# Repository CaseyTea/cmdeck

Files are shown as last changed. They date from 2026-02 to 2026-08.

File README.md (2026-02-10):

<p align="center">
    
</p>

Watch the build video ↓

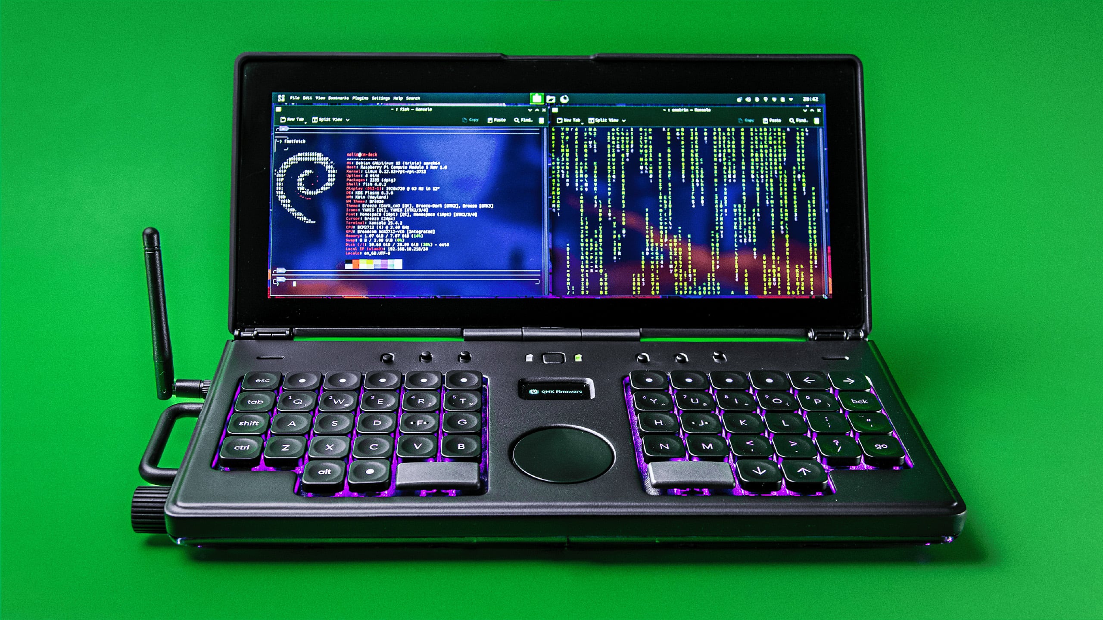
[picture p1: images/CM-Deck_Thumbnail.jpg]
[](https://youtu.be/U5GZeMm5nhI)

CM Deck is a clamshell style cyberdeck built around the Raspberry Pi Compute Module 5. It has a custom carrier board and a low profile mechanical keyboard.

<sub>⚠️ The PCBs will be updated to fix three issues: 1. The flash chip CS pin isn’t connected (see video at [11:09](https://youtu.be/U5GZeMm5nhI?si=vS6aNDHk9gTeop53&t=669)) | 2. Add jumper pads for the power button so I can solder wires and connect it to the power board (see video at [16:32](https://youtu.be/U5GZeMm5nhI?si=_Pz7x-TjfpxkA6fn&t=992)) | 3. Add an open jumper pad on the 3V3 line of the DSI connector on the main board (see video at [15:09](https://youtu.be/U5GZeMm5nhI?si=e3sX7tEprCDsY_S7&t=909))</sub>

[][cc-by-nc-sa]

[][cc-by-nc-sa]

[cc-by-nc-sa]: http://creativecommons.org/licenses/by-nc-sa/4.0/
[cc-by-nc-sa-image]: https://licensebuttons.net/l/by-nc-sa/4.0/88x31.png
[cc-by-nc-sa-shield]: https://img.shields.io/badge/License-CC%20BY--NC--SA%204.0-lightgrey.svg

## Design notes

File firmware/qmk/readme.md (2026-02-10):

⚠️ Copy the `cmdeck` folder to your qmk directory → `qmk_firmware/keyboards/cmdeck`
____

Flashing example for this keyboard:

    qmk flash -kb cmdeck -km default

See the [build environment setup](https://docs.qmk.fm/#/getting_started_build_tools).
Brand new to QMK? Start with our [Complete Newbs Guide](https://docs.qmk.fm/#/newbs).

## Bootloader

Enter the bootloader in 3 ways:

* **Bootmagic reset**: Hold down the key at top right and plug in the keyboard
* **Physical reset button**: Briefly press the button on the the PCB
* **Keycode in layout**: Press the key mapped to `QK_BOOT` if it is available

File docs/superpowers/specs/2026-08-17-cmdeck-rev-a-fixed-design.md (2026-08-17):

# CMDeck Rev A Fixed Design

## Scope

Correct only the three PCB defects documented in the upstream README. Preserve unrelated electrical, mechanical, manufacturing, and firmware behavior.

## Keyboard flash chip select

Rename the anonymous flash-select net `N$12` to `QSPI_SS_N` and connect RP2040 U1 pin `QSPI_SS_N` (physical pad 56) to it. The same net must contain W25Q128JVSIM U3 pin `!CS` (physical pad 1), pull-up R4 pin 1, and BOOT-series resistor R6 pin 2.

Route the new pad-56 connection on the keyboard bottom copper using the existing 0.2032 mm QSPI width. Follow the outside of the existing QSPI bundle with the board's 0.1524 mm clearance instead of crossing another QSPI trace.

No firmware changes are permitted because this is RP2040's dedicated external-flash interface.

## X1203 power-button pads

Add two enlarged plated through-hole wire/test pads to the main board:

- TP15: `PWR_BUTTON`
- TP16: `GND`

Use the existing `testpad:TP` device with its `PAD1-13` device / `P1-13` package: one 1.3208 mm plated hole in a 2.159 mm octagonal pad. Place the pair outside the X1203 module footprint and label the board silkscreen `X1203 BTN`, `PWR`, and `GND`. TP15 replaces an existing same-net 0.35 mm via so the original top-to-bottom connection remains intact without stacking a solder pad over a via.

TP15 is wired in parallel with the existing keyboard power switch and X1203 `PWR_SW` pad. TP16 connects to ground. The external two-pin X1203 power-button connector is wired to these pads without polarity; pressing the keyboard switch produces a momentary short between them.

Both test pads are DNP PCB features, not BOM line items or pick-and-place parts.

## DSI 3V3 isolation jumper

Add main-board JP5 as a dedicated two-terminal, normally-open solder jumper with two 1.2 x 1.5 mm top SMD pads separated by a 0.3 mm copper gap. It has no paste apertures and is not an assembled component.

Insert JP5 in series immediately before DSI connector J1 pin 22:

- JP5 pad 1: `CM5_3.3V`
- JP5 pad 2 and J1 pin 22: `DSI_3V3`

Default state is open. Do not apply solder. Closing JP5 is optional only for a separately verified DSI peripheral that requires host-supplied 3V3 and cannot back-power the carrier.

## Verification and fabrication policy

Use XML/netlist assertions before and after editing. Validate that the Eagle schematic and board agree on every new part, footprint, and target net. Compare BOM, pick-and-place, drill, Gerber, and logical netlist outputs against upstream and explain every change.

Run Autodesk Fusion/EAGLE ERC and DRC and export fresh manufacturing data when the tool is available. If it is unavailable or any CAD/export check remains incomplete, `FABRICATION_READINESS.md` must conclude **DO NOT FABRICATE** and identify the missing verification explicitly.

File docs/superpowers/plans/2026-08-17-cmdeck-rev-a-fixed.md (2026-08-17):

# CMDeck Rev A Fixed Implementation Plan

> **For agentic workers:** REQUIRED SUB-SKILL: Use superpowers:subagent-driven-development (recommended) or superpowers:executing-plans to implement this plan task-by-task. Steps use checkbox (`- [ ]`) syntax for tracking.

**Goal:** Correct the three documented CMDeck PCB defects while preserving unrelated behavior and producing an evidence-based fabrication-readiness decision.

**Architecture:** Make minimal native Eagle XML changes to the paired schematic/board sources. Use structural netlist tests as the regression harness, then use Autodesk Fusion/EAGLE for ERC, DRC, and manufacturing exports if available.

**Tech Stack:** Autodesk Eagle/Fusion XML (`.sch`, `.brd`), Python standard-library XML validation, Gerber X2, Excellon, CSV, pick-and-place text.

**Spec:** `docs/superpowers/specs/2026-08-17-cmdeck-rev-a-fixed-design.md`

## Global Constraints

- Work only on branch `rev-a-fixed`.
- Preserve unrelated electrical, mechanical, and firmware behavior.
- Keep schematic and board files mutually consistent.
- Do not modify firmware unless electrical evidence requires it.
- Do not claim fabrication readiness while ERC, DRC, export, or comparison evidence is missing.

---

### Task 1: Structural regression validator

**Files:**
- Create: `tools/validate_rev_a_fixed.py`

**Interfaces:**
- Consumes: the four Eagle source files.
- Produces: exit-zero structural validation with a human-readable assertion summary.

- [x] Write assertions for the required keyboard CS membership, main-board power pads, DSI series split, footprint defaults, and unchanged firmware tree hash.
- [x] Run the validator against upstream and confirm it fails for the three missing repairs.
- [x] Keep the validator as the repeatable source/netlist regression check.

### Task 2: Keyboard flash CS repair

**Files:**
- Modify: `pcbs/keyboard/src/Keyboard _Schematic.sch`
- Modify: `pcbs/keyboard/src/Keyboard _Board.brd`

**Interfaces:**
- Consumes: existing U1, U3, R4, R6, and QSPI routing.
- Produces: net `QSPI_SS_N` containing U1.56, U3.1, R4.1, and R6.2.

- [x] Add U1 `QSPI_SS_N` to the existing flash-select net in the schematic and rename the net.
- [x] Add U1 pad 56 to the board signal and route it around the outside of the existing bottom-layer QSPI bundle.
- [x] Run XML parsing and the keyboard validator; confirm the CS assertion passes.

### Task 3: Main-board X1203 wire pads

**Files:**
- Modify: `pcbs/main board/src/Main_Board_Schematic.sch`
- Modify: `pcbs/main board/src/Main Board _Board.brd`

**Interfaces:**
- Consumes: `PWR_BUTTON`, `GND`, and existing schematic device `testpad:PAD1-13` / package `P1-13`.
- Produces: plated through-hole TP15 (`PWR_BUTTON`) and TP16 (`GND`) with explicit silkscreen assembly labels.

- [x] Add TP15 and TP16 parts and schematic instances on the UPS/interconnect sheet.
- [x] Add their pin references to `PWR_BUTTON` and `GND`.
- [x] Add the used P1-13 package to the board's embedded testpad library and place both pads outside the X1203 footprint.
- [x] Route TP15 to the existing `PWR_BUTTON` trace and connect TP16 to ground.
- [x] Run XML parsing and the power-pad validator.

### Task 4: Main-board DSI 3V3 isolation

**Files:**
- Modify: `pcbs/main board/src/Main_Board_Schematic.sch`
- Modify: `pcbs/main board/src/Main Board _Board.brd`

**Interfaces:**
- Consumes: `CM5_3.3V` and DSI J1 pin 22.
- Produces: JP5 pad 1 on `CM5_3.3V`, JP5 pad 2 and J1.22 on `DSI_3V3`, default open.

- [x] Add a dedicated two-pad normally-open solder-jumper package, symbol, and device.
- [x] Place JP5 directly in the existing J1.22 trace and split that trace into the two named nets.
- [x] Add the schematic instance and series net split.
- [x] Run XML parsing and the DSI validator.

### Task 5: Manufacturing outputs and comparisons

**Files:**
- Update: `pcbs/keyboard/fab/`
- Update: `pcbs/main board/fab/`
- Create: `verification/upstream-comparison/`

**Interfaces:**
- Consumes: corrected Eagle sources and immutable upstream files from commit `66e5f08`.
- Produces: Gerber, Excellon, BOM, front/back PnP, hashes, and explained comparisons.

- [ ] Run Fusion/EAGLE ERC and DRC with the repository design rules. **Blocked: Fusion/EAGLE is unavailable.**
- [ ] Export fresh Gerber and Excellon files for both boards. **Blocked: Fusion/EAGLE is unavailable.**
- [ ] Export BOM and front/back pick-and-place files for both boards. **Blocked: Fusion/EAGLE is unavailable.**
- [x] Compare source logical nets and source-derived expected aperture/feature, drill, BOM, and placement differences against upstream.
- [x] Do not synthesize or relabel upstream outputs as fresh exports; record the native-CAD deliverables as blocked.

### Task 6: Release documentation and final verification

**Files:**
- Create: `REV_A_FIXED_CHANGELOG.md`
- Create: `FABRICATION_READINESS.md`

**Interfaces:**
- Consumes: all source, validation, ERC/DRC, export, and comparison evidence.
- Produces: exact assembly instructions and an unambiguous fabricate/do-not-fabricate conclusion.

- [x] Document exact nets, pins, footprints, jumper defaults, wiring, and assembly instructions.
- [x] Document every source-derived output difference and every missing native-export verification.
- [x] Run the full structural validator, XML parser, git diff checks, and checked-in fabrication-tree comparison.
- [x] Conclude `DO NOT FABRICATE` because CAD and manufacturing checks remain blocked.

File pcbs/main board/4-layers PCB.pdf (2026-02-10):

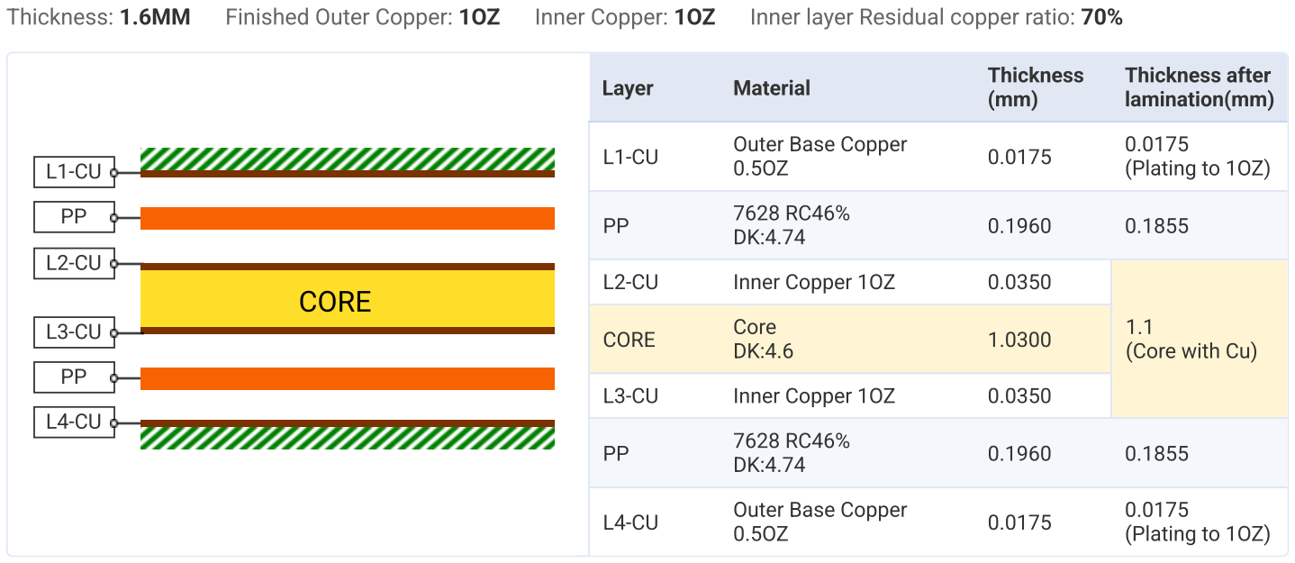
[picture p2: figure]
Layer; Material; Thickness (mm); Thickness after lamination(mm); Outer Base Copper 0.5OZ; 0.0175 (Plating to 1OZ); Inner Copper 1OZ; 1.1 (Core with Cu); CORE; Core DK:4.6

Thickness: 1.6MM | Finished Outer Copper: 1OZ | Inner Copper: 1OZ | Inner layer Residual copper ratio: 70%

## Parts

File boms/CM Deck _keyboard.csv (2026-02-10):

Qty | Value | Parts | Description | Digikey | MPN
64 | 0.1uF | C3, C4, C5, C6, C7, C8, C9, C10, C11, C16, C17, C18, C19, C20, C21, C22, C23, C24, C25, C26, C27, C28, C29, C30, C31, C32, C33, C34, C35, C36, C37, C38, C39, C40, C41, C42, C43, C44, C45, C46, C47, C48, C49, C50, C51, C52, C53, C54, C55, C56, C57, C58, C59, C60, C61, C62, C63, C64, C65, C66, C67, C68, C69, C70 | 0.1 µF ±10% 50V Ceramic Capacitor X7R 0805 (2012 Metric) | 1276-1003-1-ND | CL21B104KBCNNNC
1 | 1-1775333-6CONN16_1-1775333-6_TEC | J3 | 16 Position FPC Connector Contacts, Bottom 0.020" (0.50mm) Surface Mount, Right Angle | A120285CT-ND | 1-1775333-6
7 | 10K | R4, R5, R11, R12, R13, R14, R15 | 10 kOhms ±1% 0.125W, 1/8W Chip Resistor 0805 (2012 Metric) | A129761CT-ND | CRGCQ0805F10K
4 | 10uF | C1, C2, C71, C72 | 10 µF ±10% 25V Ceramic Capacitor X7R 1206 (3216 Metric) | 1276-1804-1-ND | CL31B106KAHNNNE
2 | 15pF | C14, C15 | 15 pF ±5% 50V Ceramic Capacitor C0G, NP0 0805 (2012 Metric) | 732-7847-1-ND | 885012007052
2 | 1K | R1, R6 | 1 kOhms ±5% 0.125W, 1/8W Chip Resistor 0805 (2012 Metric) | A126391CT-ND | CRG0805J1K0
55 | 1N4148W | D1, D2, D3, D4, D5, D6, D7, D8, D9, D10, D11, D12, D13, D14, D15, D16, D17, D18, D19, D20, D21, D22, D23, D24, D25, D26, D27, D28, D29, D30, D31, D32, D33, D34, D35, D36, D37, D38, D39, D40, D41, D42, D43, D44, D45, D46, D47, D48, D49, D50, D51, D52, D53, D54, D55 | Diode 100 V 150mA Surface Mount SOD-123 | 1N4148W-FDICT-ND | 1N4148W-7-F
4 | 1uF | C12, C13, C73, C74 | 1 µF ±10% 50V Ceramic Capacitor X7R 0805 (2012 Metric) | 1276-1029-1-ND | CL21B105KBFNNNE
2 | 2.2K | R9, R10 | 2.2 kOhms ±1% 0.125W, 1/8W Chip Resistor 0805 (2012 Metric) | A106060CT-ND | CRG0805F2K2
2 | 27 | R2, R3 | 27 Ohms ±1% 0.125W, 1/8W Chip Resistor 0805 (2012 Metric) | A129730CT-ND | CRGCQ0805F27R
1 | 5.1K | R8 | 5.1 kOhms ±1% 0.125W, 1/8W Chip Resistor 0805 (2012 Metric) | A126379CT-ND | CRG0805F5K1
54 | 5114 | S1, S2, S3, S4, S5, S6, S7, S8, S9, S10, S11, S12, S13, S14, S15, S16, S17, S18, S19, S20, S21, S22, S23, S24, S25, S26, S27, S28, S29, S30, S31, S32, S33, S34, S35, S36, S37, S38, S39, S40, S41, S42, S43, S44, S45, S46, S47, S48, S49, S50, S51, S52, S53, S54 | Kailh Low Profile Switch Socket | 1528-5118-ND | CPG135001S30
1 | 680K | R7 | 680 kOhms ±1% 0.125W, 1/8W Chip Resistor 0805 (2012 Metric) | A129783CT-ND | CRGCQ0805F680K
1 | ABM8-272-T3 | Y1 | 12 MHz ±30ppm Crystal 10pF 50 Ohms 4-SMD, No Lead | 5254-MP12641CT-ND | MP12641
1 | AP2112K-3.3TRG1SOT_RG1_DIO | U2 | Linear Voltage Regulator IC Positive Fixed 1 Output 600mA SOT-25 | AP2112K-3.3TRG1DICT-ND | AP2112K-3.3TRG1
2 | CHIP-FLAT-G_1206 | D58, D59 | Green 570nm LED Indication - Discrete 2V 1206 (3216 Metric) | 732-4993-1-ND | 150120VS75000
2 | CMS-151135-18S-X8 | LS1, LS2 | 8 Ohms General Purpose Speaker 1 W 760 Hz ~ 20 kHz Top Rectangular | 2223-CMS-151135-18S-X8-ND | CMS-151135-18S-X8
1 | F31L-1A7H1-11012 | J4 | 12 Position FFC, FPC Connector Contacts, Bottom 0.020" (0.50mm) Surface Mount, Right Angle | 609-F31L-1A7H1-11012CT-ND | F31L-1A7H1-11012
2 | M55-6001242R | J1, J2 | 12 Position Receptacle Connector 0.050" (1.27mm) Surface Mount Gold | 952-3835-1-ND | M55-6001242R
1 | PEC09-2120F-S0012 | U$1 | Rotary Encoder Mechanical 12 Quadrature (Incremental) Right Angle | PEC09-2120F-S0012-ND | PEC09-2120F-S0012
1 | SC0914(13) | U1 | RP2040 ARM® Cortex®-M0+ - Microcontroller IC | 2648-SC0914(13)CT-ND | SC0914(13)
54 | SK6812-EJ | LED1, LED2, LED3, LED4, LED5, LED6, LED7, LED8, LED9, LED10, LED11, LED12, LED13, LED14, LED15, LED16, LED17, LED18, LED19, LED20, LED21, LED22, LED23, LED24, LED25, LED26, LED27, LED28, LED29, LED30, LED31, LED32, LED33, LED34, LED35, LED36, LED37, LED38, LED39, LED40, LED41, LED42, LED43, LED44, LED45, LED46, LED47, LED48, LED49, LED50, LED51, LED52, LED53, LED54 | Neopixel Reverse Mount 3.10mm L x 2.70mm W - SK6812-E | 1528-4960-ND | 4960
6 | SLW-1277744-3A-N-D | S55, S56, S57, S58, S59, S60 | Slide Switch SPDT Through Hole | 2223-SLW-1277744-3A-N-D-ND | SLW-1277744-3A-N-D
2 | SN74AHCT1G125DBVR | U4, U5 | Buffer, Non-Inverting 1 Element 1 Bit per Element 3-State Output SOT-23-5 | 296-4708-1-ND | SN74AHCT1G125DBVR
2 | SPST-NO_SWITCH_KMR2 | BOOT, RESET | Tactile Switch SPST-NO Top Actuated Surface Mount | 401-1426-1-ND | Y78B21110FP
1 | SPST-NO_SWITCH_PTS645-SMT-6MM | S61 | Tactile Switch SPST-NO Top Actuated Surface Mount | CKN11907CT-ND | Y97HT23B4EAFP
1 | W25Q128JVSIM_TR | U3 | Check availability | W25Q128JVSIM-ND | W25Q128JVSIM

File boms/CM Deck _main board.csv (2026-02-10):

Qty | Value | Parts | Description | Digikey | MPN
17 | 0.1uF | C1, C2, C3, C4, C5, C6, C7, C8, C11, C21, C27, C28, C30, C32, C34, C45, C51 | 0.1 µF ±10% 50V Ceramic Capacitor X7R 0805 (2012 Metric) | 1276-1003-1-ND | CL21B104KBCNNNC
1 | 1-2199119-5 | J7 | 67 Position Female Connector M.2 (NGFF) Mini Card | A115902CT-ND | 1-2199119-5
6 | 100K | R7, R11, R12, R13, R14, R17 | 100 kOhms ±1% 0.125W, 1/8W Chip Resistor 0805 (2012 Metric) | A129773CT-ND | CRGCQ0805F100K
1 | 100uF | C18 | 100 µF Molded Tantalum Polymer Capacitor 10 V 1411 (3528 Metric) | 478-TCTOBL1A107M8R-ZS1CT-ND | TCTOBL1A107M8R-ZS1
8 | 10K | R1, R6, R16, R19, R28, R31, R32, R33, R34 | 10 kOhms ±1% 0.125W, 1/8W Chip Resistor 0805 (2012 Metric) | A129761CT-ND | CRGCQ0805F10K
17 | 10uF | C9, C10, C14, C15, C16, C17, C19, C20, C22, C23, C24, C25, C29, C31, C33, C35, C52 | 10 µF ±10% 25V Ceramic Capacitor X7R 1206 (3216 Metric) | 1276-1804-1-ND | CL31B106KAHNNNE
1 | 12K | R10 | 12 kOhms ±1% 0.125W, 1/8W Chip Resistor 0805 (2012 Metric) | A129762CT-ND | CRGCQ0805F12K
1 | 15K | R15 | 15 kOhms ±1% 0.125W, 1/8W Chip Resistor 0805 (2012 Metric) | A126341CT-ND | CRG0805F15K
8 | 1uF | C40, C41, C44, C46, C47, C48, C49, C50 | 1 µF ±10% 50V Ceramic Capacitor X7R 0805 (2012 Metric) | 1276-1029-1-ND | CL21B105KBFNNNE
3 | 2.2K | R18, R24, R25 | 2.2 kOhms ±1% 0.125W, 1/8W Chip Resistor 0805 (2012 Metric) | A106060CT-ND | CRG0805F2K2
2 | 2.2nF | C38, C39 | 2200 pF ±5% 50V Ceramic Capacitor C0G, NP0 0805 (2012 Metric) | 1276-2993-1-ND | CL21C222JBFNNNE
4 | 2.2uF | C36, C37, C42, C43 | 2.2 µF ±10% 10V Ceramic Capacitor X7R 0805 (2012 Metric) | 1276-1188-1-ND | CL21B225KPFNNNE
1 | 2.2uH | L1 | 2.2 µH Shielded Molded Inductor 10.3 A 14.52mOhm Max | 732-74439334022CT-ND | 74439334022
1 | 2328702-8 | J14 | 8 Position FPC Connector Contacts, Top and Bottom 0.020" (0.50mm) Surface Mount, Right Angle | A141389CT-ND | 2328702-8
1 | 24 MHz | Y1 | 24 MHz ±20ppm Crystal 18pF 50 Ohms 4-SMD, No Lead | 732-830058124CT-ND | 830058124
2 | 27pF | C12, C13 | 27 pF ±5% 50V Ceramic Capacitor C0G, NP0 0805 (2012 Metric) | 738-CML0805C0G270JT50VCT-ND | CML0805C0G270JT50V
1 | 4.7nF | C26 | 4700 pF ±5% 50V Ceramic Capacitor C0G, NP0 0805 (2012 Metric) | 490-3044-1-ND | GRM2165C1H472JA01D
4 | 470 | R2, R3, R26, R27 | 470 Ohms ±5% 0.125W, 1/8W Chip Resistor 0805 (2012 Metric) | A130132CT-ND | CRGCQ0805J470R
4 | 5.1K | R4, R5, R8, R9 | 5.1 kOhms ±1% 0.125W, 1/8W Chip Resistor 0805 (2012 Metric) | A126379CT-ND | CRG0805F5K1
4 | 56K | R20, R21, R22, R23 | 56 kOhms ±1% 0.125W, 1/8W Chip Resistor 0805 (2012 Metric) | A129770CT-ND | CRGCQ0805F56K
2 | 61201621721 | J18, J19 | Connector Header Through Hole, Right Angle 16 position 0.100" (2.54mm) | 732-2099-ND | 61201621721
1 | 614104190121 | J4 | USB-A (USB TYPE-A) USB 2.0 Receptacle Connector | 732-10011-1-ND | 614104190121
1 | AP22653W6-7 | U3 | Power Switch/Driver 1:1 N-Channel 2.1A SOT-26 (Type A1) | 31-AP22653AW6-7CT-ND | AP22653AW6-7
1 | AP3441SHE-7BIC8_AP3441SHE-7B_DIO-M | U12 | Buck Switching Regulator IC Positive Adjustable 0.6V 1 Output 3A | AP3441SHE-7BDICT-ND | AP3441SHE-7B
1 | ASEK-32.768KHZ-L-R-T | Y2 | 32.768 kHz XO (Standard) CMOS Oscillator 3.3V Enable/Disable 4-SMD, No Lead | 535-ASEK-32.768KHZ-L-R-TCT-ND | ASEK-32.768KHZ-L-R-T
2 | CM5108064B | U1 | 100 Position Connector Receptacle, Center Strip Contacts Surface Mount Gold | H11615CT-ND | DF40C-100DS-0.4V(51)
1 | COIN-CELL-SMT-3P-3002-BR2016 | BT1 | Battery Retainer Coin, 20.0mm 1 Cell SMD (SMT) Tab | 36-3002-ND | 3002
1 | FBCHIP-0805(2012-METRIC) | FB1 | 1 kOhms @ 100 MHz 1 Signal Line Ferrite Bead 0805 (2012 Metric) | 732-6704-1-ND | 782851102
1 | FH12-22S-0.5SH(55)CONN_FH12-22S-0.5SH(55)_HIR | J1 | 22 Position FFC, FPC Connector Contacts, Bottom 0.020" (0.50mm) Surface Mount, Right Angle | HFJ122CT-ND | FH12-22S-0.5SH(55)
1 | FSUSB42MUX | U5 | USB Switch IC 1 Channel 10-MSOP | FSUSB42MUXCT-ND | FSUSB42MUX
2 | HD05-19-TH-TR | J2, J3 | HDMI HDMI 2.0 Receptacle Connector 19 Position Surface Mount, Right Angle; Through Hole | 2223-HD05-19-TH-TRCT-ND | HD05-19-TH-TR
1 | L8BE-1G1T-BFH | J10 | 1 Port RJ45 Board Edge, Cutout; Through Hole 10/100/1000 Base-T, AutoMDIX | 5923-L8BE-1G1T-BFH-ND | L8BE-1G1T-BFH
2 | M55-7011242R | J16, J21 | Connector Header Surface Mount 12 position 0.050" (1.27mm) | 952-3875-1-ND | M55-7011242R
1 | MAX98306ETD+T | U14 | Amplifier IC 2-Channel (Stereo) Class D 14-TDFN (3x3) | MAX98306ETD+TCT-ND | MAX98306ETD+T
1 | PCM5100APWRPW0020A | U13 | DAC, Audio 16 b, 24 b, 32 b 384k PCM 20-TSSOP | 296-36705-1-ND | PCM5100APWR
1 | RT9742SNGVSOT_42SNGV_RIT | U2 | Power Switch/Driver 1:1 N-Channel 500mA SOT-23-3 | 1028-RT9742SNGVCT-ND | RT9742SNGV
2 | S2B-XH-A | J12, J13 | Connector Header Through Hole, Right Angle 2 position 0.098" (2.50mm) | 455-S2B-XH-A-1-ND | S2B-XH-A-1
1 | SJ-3579AN | J17 | 3.50mm (0.141", 1/8", Mini Plug) - Headphone Phone Jack Stereo (3 Conductor, TRS) | 102-5874-ND | SJ-3579AN
1 | SM04B-SRSS-TBCONN_SM04B-SRSS-TB_JST | J8 | Connector Header Surface Mount, Right Angle 4 position 0.039" (1.00mm) | 455-SM04B-SRSS-TBCT-ND | SM04B-SRSS-TB
1 | TPA6132A2 | IC1 | Amplifier IC Headphones, 2-Channel (Stereo) Class AB 16-WQFN (3x3) | 296-27194-1-ND | TPA6132A2RTET
5 | TPD2EUSB30DRTR | D1, D2, D3, D4, D5 | 8V Clamp 5A (8/20µs) Ipp Tvs Diode Surface Mount SOT-3 | 296-25509-1-ND | TPD2EUSB30DRTR
6 | TPD4EUSB30DQAR | U6, U7, U8, U9, U10, U11 | 8V Clamp 1A (8/20µs) Ipp Tvs Diode Surface Mount 10-USON (2.5x1) | 296-28063-1-ND | TPD4EUSB30DQAR
4 | UJ20-C-R-G-TH-2-P14-TR | J5, J6, J9, J11 | USB-C (USB TYPE-C) USB 2.0 Receptacle Connector 24 (14+10 Dummy) | 2223-UJ20-C-R-G-TH-2-P14-TRCT-ND | UJ20-C-R-G-TH-2-P14-TR
1 | USB2514B/M2SQFN36_6X6_MCH | U4 | USB Hub Controller USB Interface 36-SQFN (6x6) | USB2514B/M2-ND | USB2514B/M2

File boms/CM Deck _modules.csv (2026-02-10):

Qty | Part | Link
1 | Raspberry Pi Compute Module 5
1 | NVMe SSD
1 | Aluminum Heatsink for Raspberry Pi CM4
1 | 2.4G/5G WiFi Antenna Compatible w/ Raspberry Pi CM4 & CM5
2 | 3.7V 5000mAh Lithium Ion Polymer Battery
1 | 12.3inch DSI Capacitive Touch Screen
1 | SupTronics X1203 UPS for Raspberry Pi 5
1 | Raspberry Pi 27W USB-C Power Supply
1 | Cirque Capacitance Touch Sensor Modules 40mm Round
54 | Kailh c V1 Low Profile Switches
52 | Choc V1 Low profile Keycaps
2 | (2u) Choc V1 Low profile Keycaps
1 | Monochrome 1.3" 128x64 SH1106G SPI OLED Monochrome Display | 1528-5228-ND
1 | 22 Position FFC, FPC Cable 0.020" (0.50mm) 12.0" (304.8mm) | 0151660248-ND
1 | 8 Position FFC, FPC Cable 0.020" (0.50mm) 12.0" (304.8mm) | 2073-05-08-D-0304-A-4-06-4-G-ND

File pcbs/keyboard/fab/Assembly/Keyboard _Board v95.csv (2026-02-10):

Qty | Value | Device | Package | Parts | Description
64 | 0.1uF | C-US_CHIP-0805(2012-METRIC) | CAPC2012X110 | C3, C4, C5, C6, C7, C8, C9, C10, C11, C16, C17, C18, C19, C20, C21, C22, C23, C24, C25, C26, C27, C28, C29, C30, C31, C32, C33, C34, C35, C36, C37, C38, C39, C40, C41, C42, C43, C44, C45, C46, C47, C48, C49, C50, C51, C52, C53, C54, C55, C56, C57, C58, C59, C60, C61, C62, C63, C64, C65, C66, C67, C68, C69, C70 | Capacitor - ANSI
1 | 1-1775333-6CONN16_1-1775333-6_TEC | 1-1775333-6CONN16_1-1775333-6_TEC | CONN16_1-1775333-6_TEC | J3
7 | 10K | R-US_CHIP-0805(2012-METRIC) | RESC2012X65 | R4, R5, R11, R12, R13, R14, R15 | Resistor Fixed - ANSI
4 | 10uF | C-US_CHIP-1206(3216-METRIC) | CAPC3216X135 | C1, C2, C71, C72 | Capacitor - ANSI
2 | 15pF | C-US_CHIP-0805(2012-METRIC) | CAPC2012X110 | C14, C15 | Capacitor - ANSI
2 | 1K | R-US_CHIP-0805(2012-METRIC) | RESC2012X65 | R1, R6 | Resistor Fixed - ANSI
55 | 1N4148W | 1N4148W | SOD3715X135N | D1, D2, D3, D4, D5, D6, D7, D8, D9, D10, D11, D12, D13, D14, D15, D16, D17, D18, D19, D20, D21, D22, D23, D24, D25, D26, D27, D28, D29, D30, D31, D32, D33, D34, D35, D36, D37, D38, D39, D40, D41, D42, D43, D44, D45, D46, D47, D48, D49, D50, D51, D52, D53, D54, D55 | 1N4148W Series 2 A 100 V 400 mW Surface Mount Fast Switching Diode - SOD-123 Check availability
4 | 1uF | C-US_CHIP-0805(2012-METRIC) | CAPC2012X110 | C12, C13, C73, C74 | Capacitor - ANSI
2 | 2.2K | R-US_CHIP-0805(2012-METRIC) | RESC2012X65 | R9, R10 | Resistor Fixed - ANSI
2 | 27 | R-US_CHIP-0805(2012-METRIC) | RESC2012X65 | R2, R3 | Resistor Fixed - ANSI
1 | 5.1K | R-US_CHIP-0805(2012-METRIC) | RESC2012X65 | R8 | Resistor Fixed - ANSI
54 | 5114 | 5114 | SW_5114 | S1, S2, S3, S4, S5, S6, S7, S8, S9, S10, S11, S12, S13, S14, S15, S16, S17, S18, S19, S20, S21, S22, S23, S24, S25, S26, S27, S28, S29, S30, S31, S32, S33, S34, S35, S36, S37, S38, S39, S40, S41, S42, S43, S44, S45, S46, S47, S48, S49, S50, S51, S52, S53, S54 | Check availability
1 | 680K | R-US_CHIP-0805(2012-METRIC) | RESC2012X65 | R7 | Resistor Fixed - ANSI
1 | ABM8-272-T3 | ABM8-272-T3 | XTAL_ABM8-272-T3 | Y1
1 | AP2112K-3.3TRG1SOT_RG1_DIO | AP2112K-3.3TRG1SOT_RG1_DIO | SOT_RG1_DIO | U2
2 | CHIP-FLAT-G_1206 | CHIP-FLAT-G_1206 | LEDC3216X75N_FLAT-G | D58, D59 | Green LED - Generic
2 | CMS-151135-18S-X8 | CMS-151135-18S-X8 | SPKR_CMS-151135-18S-X8 | LS1, LS2
1 | F31L-1A7H1-11012 | F31L-1A7H1-11012 | AMPHENOL_F31L-1A7H1-11012 | J4
3 | JUMPER-SMT_2_NC_TRACE_NO-SILK | JUMPER-SMT_2_NC_TRACE_NO-SILK | SMT-JUMPER_2_NC_TRACE_NO-SILK | JP1, JP2, JP3 | Normally closed trace jumper
2 | M55-6001242R | M55-6001242R | HARWIN_M55-6001242R | J1, J2
1 | PEC09-2120F-S0012 | PEC09-2120F-S0012 | PEC09-2XXXF-SXXXX | U$1
1 | SC0914(13) | SC0914(13) | QFN40P700X700X90-57N | U1
54 | SK6812-EJ | SK6812-EJ | LED_SK6812-E | LED1, LED2, LED3, LED4, LED5, LED6, LED7, LED8, LED9, LED10, LED11, LED12, LED13, LED14, LED15, LED16, LED17, LED18, LED19, LED20, LED21, LED22, LED23, LED24, LED25, LED26, LED27, LED28, LED29, LED30, LED31, LED32, LED33, LED34, LED35, LED36, LED37, LED38, LED39, LED40, LED41, LED42, LED43, LED44, LED45, LED46, LED47, LED48, LED49, LED50, LED51, LED52, LED53, LED54 | Check availability
6 | SLW-1277744-3A-N-D | SLW-1277744-3A-N-D | SW_SLW-1277744-3A-N-D | S55, S56, S57, S58, S59, S60
2 | SN74AHCT1G125DBVR | SN74AHCT1G125DBVR | SOT95P280X145-5N | U4, U5
2 | SPST-NO_SWITCH_KMR2 | SPST-NO_SWITCH_KMR2 | KMR2 | BOOT, RESET | SPST Switches with NO Configuration
1 | SPST-NO_SWITCH_PTS645-SMT-6MM | SPST-NO_SWITCH_PTS645-SMT-6MM | PTS645-SMT-6MM | S61 | SPST Switches with NO Configuration
8 | TPB1,27 | TPB1,27 | B1,27 | TP4, TP6, TP7, TP8, TP9, TP10, TP11, TP12 | Test pad
5 | TPB2,54 | TPB2,54 | B2,54 | TP1, TP2, TP3, TP5, TP13 | Test pad
1 | W25Q128JVSIM_TR | W25Q128JVSIM_TR | SOIC127P790X216-8N | U3 | Check availability

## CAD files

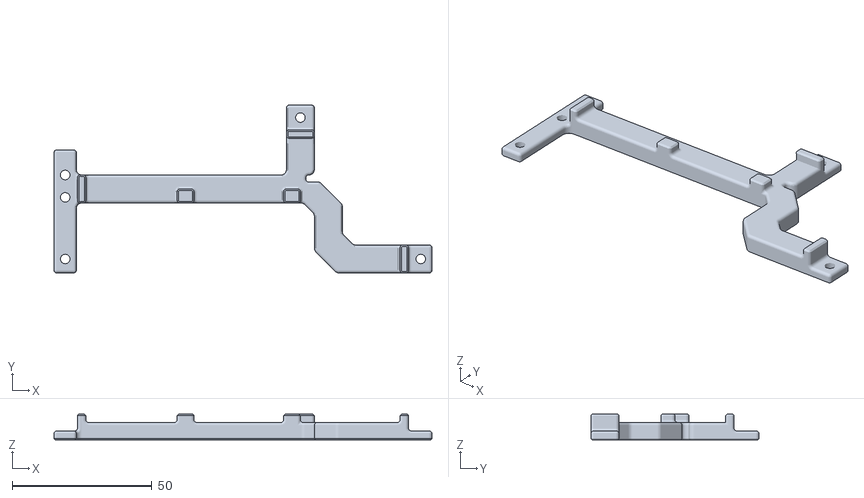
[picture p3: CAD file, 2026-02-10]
enclosure/exports/STL/02_support structure/CDMDECK_KB_INTERNAL_SUP_MAIN_BOARD_RIGHT.stl
135.0 x 60.0 x 9.25

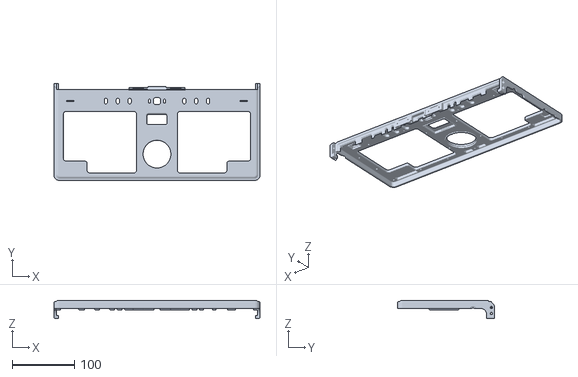
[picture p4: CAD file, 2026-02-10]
enclosure/exports/STL/00_shell/CMDECK_KB_SHELL_TOP.stl
330.0 x 155.0 x 29.1

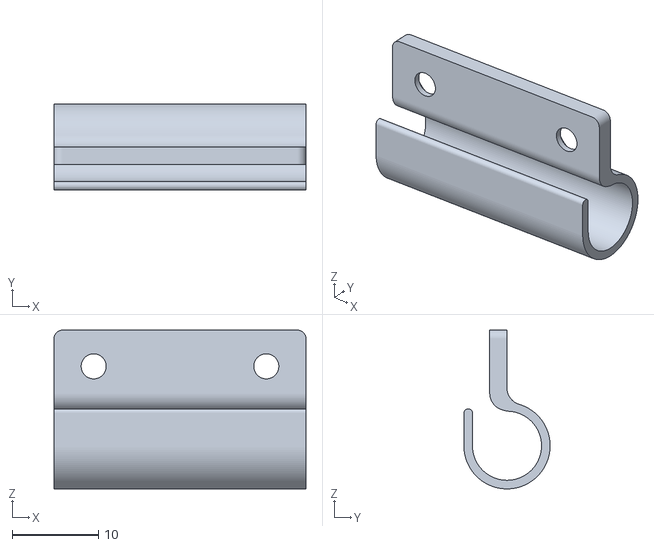
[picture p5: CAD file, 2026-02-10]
enclosure/exports/STL/01_display/CMDECK_DISPLAY_FFC_HINGE_COVER.stl
29.2 x 10.00 x 18.4

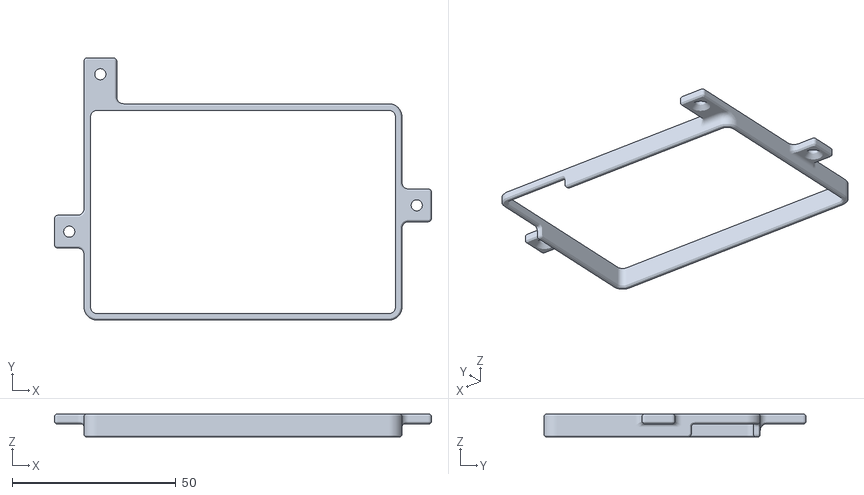
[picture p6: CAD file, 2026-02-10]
enclosure/exports/STL/02_support structure/CDMDECK_KB_INTERNAL_SUP_BAT_PERI_RIGHT.stl
115.0 x 80.0 x 7.00

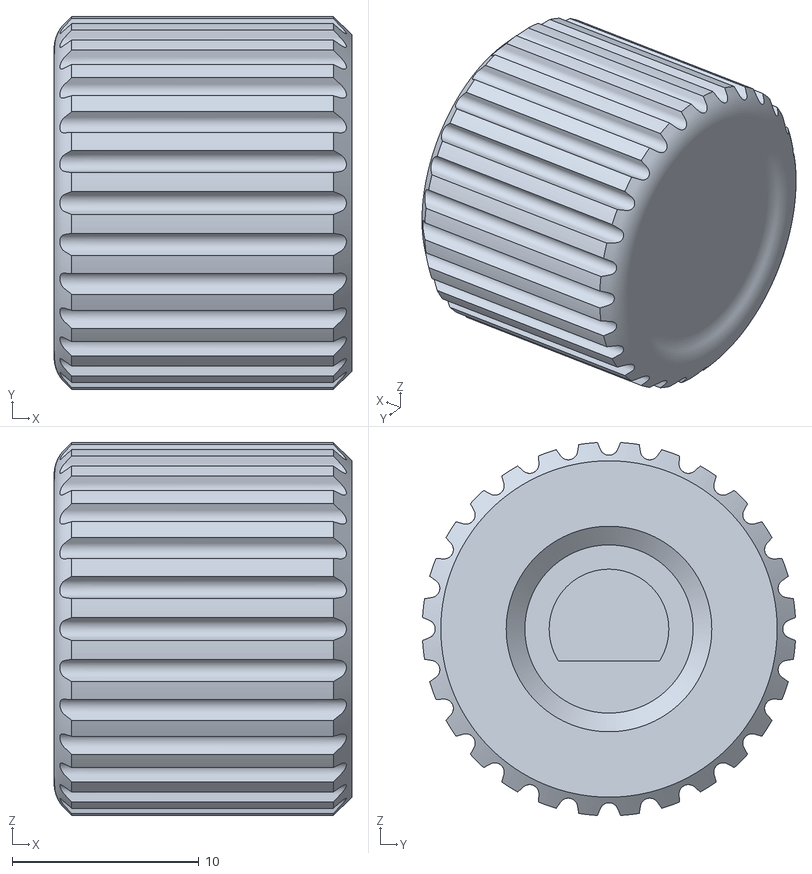
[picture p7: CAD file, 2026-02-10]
enclosure/exports/STL/03_controls/CMDECK_KB_ENCODER_KNOB.stl
15.9 x 20.0 x 20.0

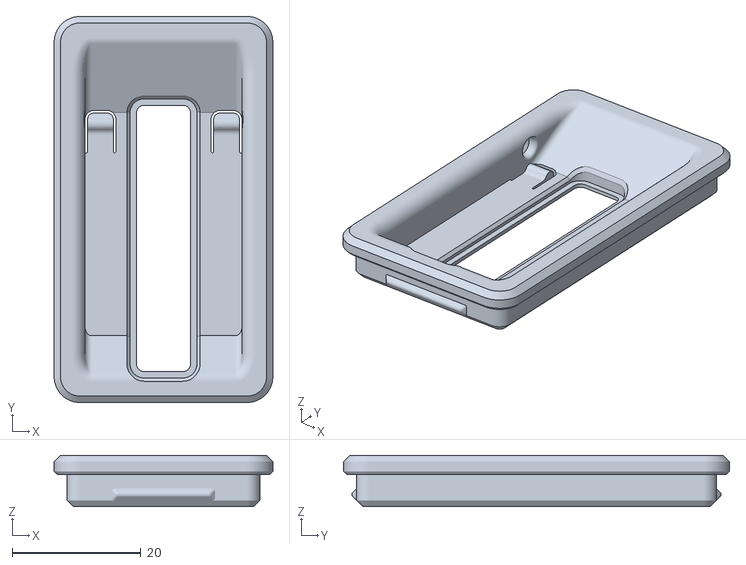
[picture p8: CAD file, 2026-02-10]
enclosure/exports/STL/04_risers/CDMDECK_KB_RISER_FEET_HOLDER.stl
34.0 x 60.0 x 8.00

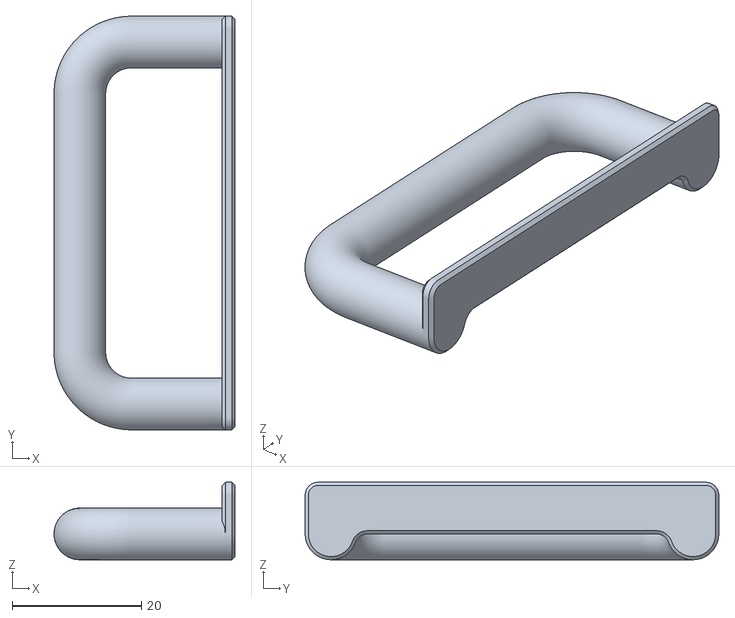
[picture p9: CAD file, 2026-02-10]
enclosure/exports/STL/05_misc/CMDECK_KB_HANDLE.stl
28.0 x 64.0 x 12.0

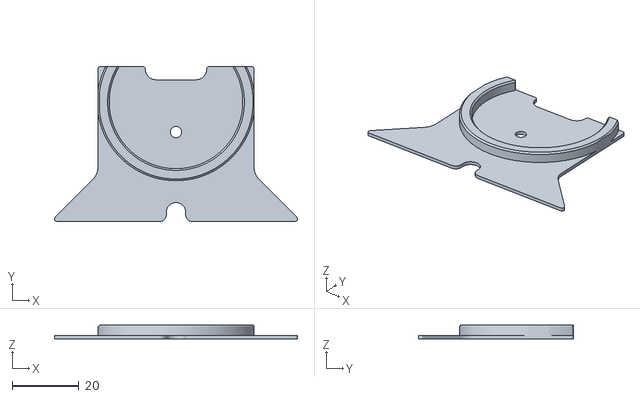
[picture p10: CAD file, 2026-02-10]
enclosure/exports/STL/02_support structure/CDMDECK_KB_INTERNAL_SUP_TRACKPAD_COVER.stl
72.8 x 46.5 x 4.20

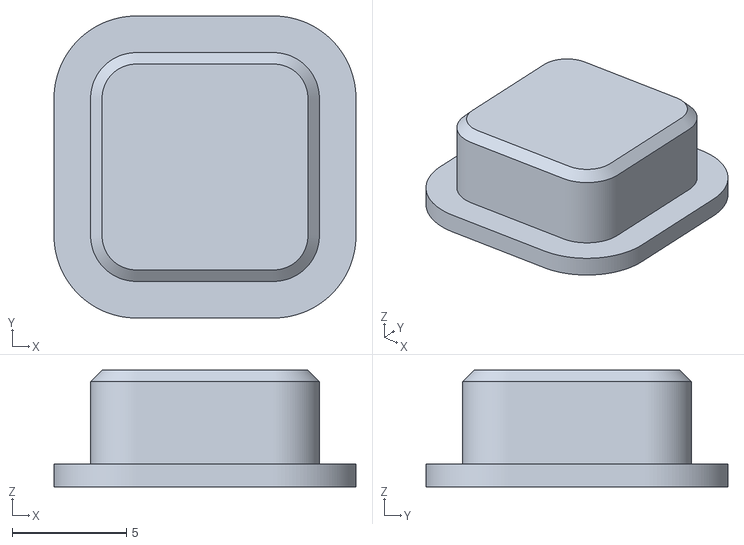
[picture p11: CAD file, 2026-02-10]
enclosure/exports/STL/03_controls/CMDECK_KB_PWR_BUTTON.stl
13.2 x 13.2 x 5.10

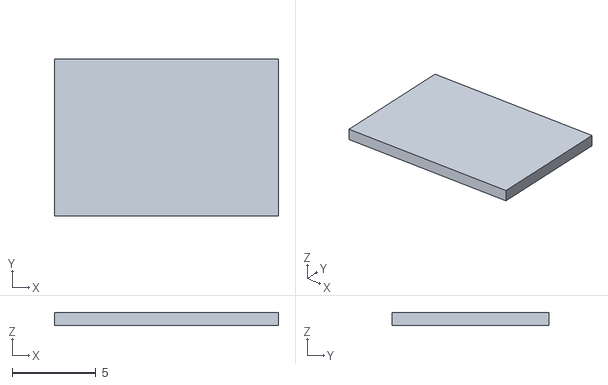
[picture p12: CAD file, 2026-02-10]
enclosure/exports/STL/05_misc/CMDECK_KB_SPEAKER_GRILL_THIN.stl
13.4 x 9.40 x 0.8

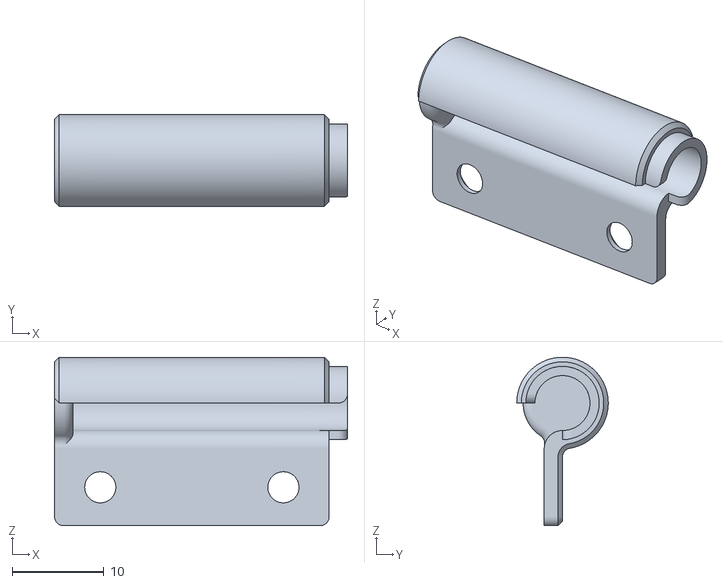
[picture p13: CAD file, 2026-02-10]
enclosure/exports/STL/00_shell/CMDECK_KB_FFC_HINGE_COVER_RIGHT.stl
32.0 x 10.00 x 18.4

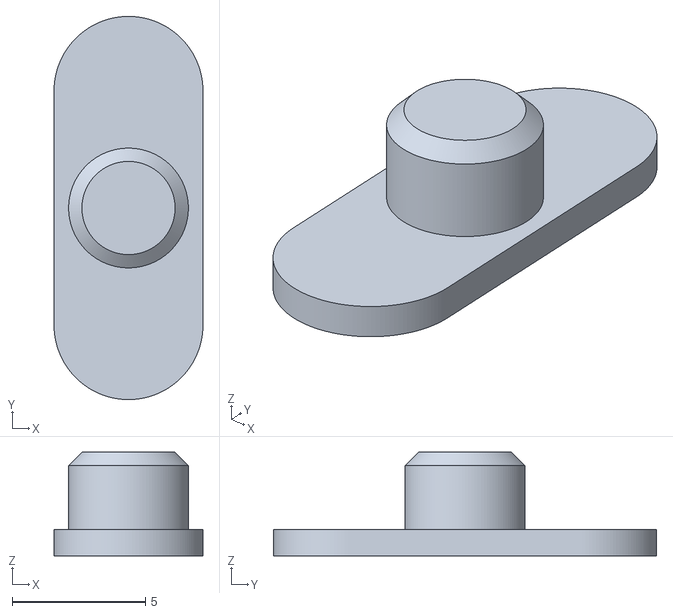
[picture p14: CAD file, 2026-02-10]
enclosure/exports/STL/03_controls/CMDECK_KB_SLIDER_SWITCH.stl
5.60 x 14.4 x 3.90

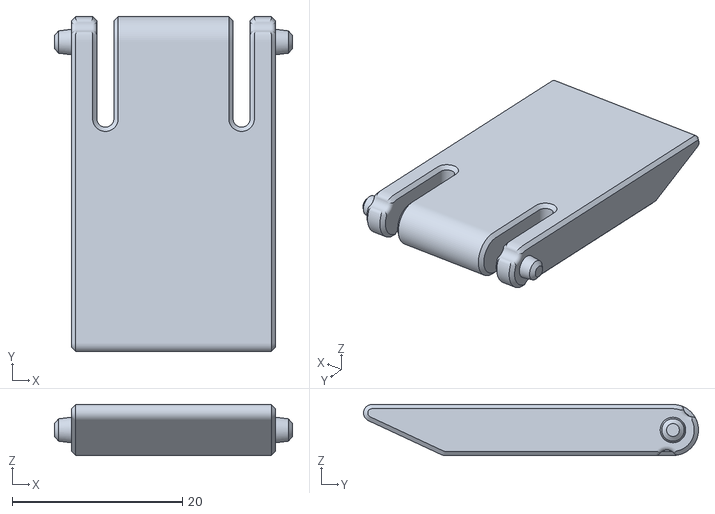
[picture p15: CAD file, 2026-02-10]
enclosure/exports/STL/04_risers/CDMDECK_KB_RISER_FEET.stl
28.0 x 39.4 x 6.00

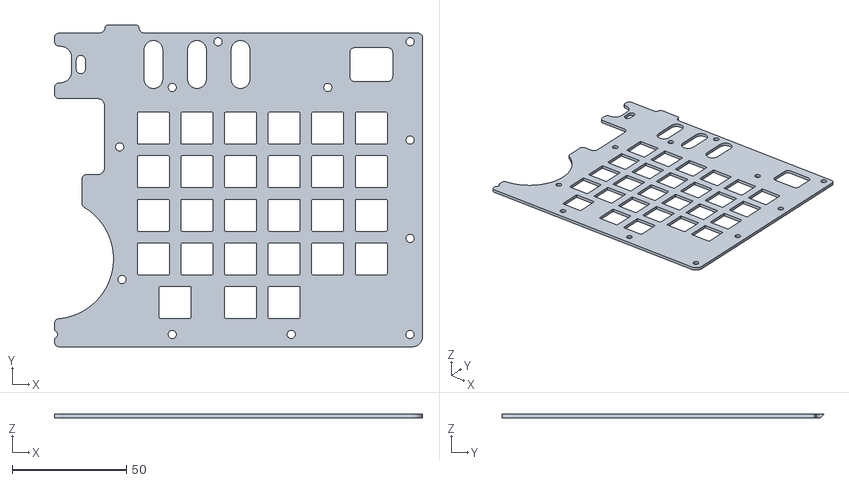
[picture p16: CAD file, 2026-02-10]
enclosure/exports/STL/05_misc/CMDECK_KB_SWITCH_PLATE_RIGHT.stl
160.9 x 140.6 x 1.80

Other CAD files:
enclosure/exports/STL/02_support structure/CDMDECK_KB_INTERNAL_SUP_MAIN_BOARD_LEFT.stl
enclosure/exports/STL/00_shell/CMDECK_KB_SHELL_TOP_ALT.stl
enclosure/exports/STL/00_shell/CMDECK_KB_BACK_IO_PLATE.stl
enclosure/exports/STL/02_support structure/CDMDECK_KB_INTERNAL_SUP_TRACKPAD_SHELL.stl
enclosure/exports/STL/00_shell/CMDECK_KB_FFC_HINGE_COVER_LEFT.stl
enclosure/exports/STL/02_support structure/CDMDECK_KB_INTERNAL_SUP_BAT_LEFT.stl
enclosure/exports/STL/02_support structure/CDMDECK_KB_INTERNAL_SUP_BAT_PERI_LEFT.stl
enclosure/exports/STL/02_support structure/CDMDECK_KB_INTERNAL_SUP_BAT_RIGHT.stl
enclosure/exports/STL/02_support structure/CDMDECK_KB_INTERNAL_SUP_STRUC_LEFT.stl
enclosure/exports/STL/02_support structure/CDMDECK_KB_INTERNAL_SUP_STRUC_RIGHT.stl
enclosure/exports/STL/02_support structure/CMDECK_KB_OLED_SUPPORT.stl
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

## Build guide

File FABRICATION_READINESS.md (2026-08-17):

# CMDeck Rev A Fixed Fabrication Readiness

## Conclusion

**DO NOT FABRICATE.**

The three source-level electrical repairs are implemented and pass structural checks, but the required Autodesk Fusion/EAGLE verification and fresh manufacturing export have not been completed. Existing upstream fabrication outputs remain unsafe.

## Completed evidence

- Both corrected schematic files and both corrected board files parse as well-formed Eagle 9.7 XML.
- Every board element has a corresponding schematic part.
- Every board signal contact reference resolves to a real pad in its embedded footprint.
- Every pre-existing component footprint and placement matches upstream.
- Every unrelated schematic and board endpoint-to-net assignment matches upstream.
- Keyboard `QSPI_SS_N` contains exactly the required functional endpoints, including RP2040 pad 56.
- Main-board TP15 and TP16 exist in both schematic and board on `PWR_BUTTON` and `GND` respectively.
- JP5 is represented consistently in schematic and board as a series split between `CM5_3.3V` and `DSI_3V3`.
- JP5 has no default copper bridge and no paste apertures.
- Local copper inspection found and corrected an initial wire-pad placement conflict; the final plated-hole locations are clear of non-target routed copper in both outer layers by source geometry inspection.
- Firmware is byte-for-byte unchanged from upstream commit `66e5f08`.
- `git diff --check` reports no whitespace errors.

## ERC result

**NOT RUN - BLOCKED.** Autodesk Fusion/EAGLE is not installed or discoverable in `/Applications`, the user Applications directory, `/opt`, `/usr/local`, `/Users/Shared`, or Spotlight metadata on this workstation.

The Python structural validator is not an ERC substitute. It does not evaluate Eagle pin electrical types, supply conflicts, or schematic warnings.

## DRC result

**NOT RUN - BLOCKED.** The Autodesk routing/design-rule engine is unavailable.

Source-level geometry review is not a DRC substitute. It does not prove every copper-to-copper, copper-to-edge, mask-sliver, annular-ring, differential-pair, or plane-clearance rule.

## Fabrication outputs

**NOT GENERATED - BLOCKED.** No fresh Gerber, Excellon, ODB++, BOM, or pick-and-place export has been produced.

The checked-in files under `pcbs/keyboard/fab/` and `pcbs/main board/fab/` remain byte-for-byte upstream artifacts. They do not contain these repairs and must not be sent to a fabricator.

## Remaining required work

1. Open each corrected `.sch`/`.brd` pair together in Autodesk Fusion/EAGLE 9.7-compatible electronics tooling and confirm forward/back annotation consistency.
2. Inspect all newly added library objects and exact board placement visually in the native editor.
3. Re-pour polygons on both boards.
4. Run ERC and resolve or explicitly waive every warning.
5. Run DRC using the original board rules and resolve or explicitly waive every violation.
6. Export fresh Gerber X2 and Excellon data for both boards.
7. Export fresh BOM plus front/back pick-and-place outputs for both boards. Mark TP15, TP16, and JP5 DNP.
8. Compare every new manufacturing file with upstream as outlined in `verification/upstream-comparison/README.md`.
9. Inspect the corrected exports in an independent Gerber viewer, including layer registration, board outline, mask openings, JP5's open gap, TP15/TP16 drills, and the keyboard CS trace.
10. Update this document to `FABRICATE` only after all preceding evidence passes.

## Assembly defaults after verification

- Keyboard: no rework wire; the U1.56-to-U3.1 CS connection is native copper.
- X1203 button: solder two wires to TP15 (`PWR`) and TP16 (`GND`) and connect them to the X1203 external-button input.
- DSI JP5: leave open for the documented externally powered Waveshare display.

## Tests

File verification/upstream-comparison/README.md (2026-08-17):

# Rev A Fixed vs. Upstream Comparison

Baseline: upstream commit `66e5f08` (`origin/main` when the repair branch was created).

## Source netlist differences

### Keyboard

| Item | Upstream | Rev A Fixed | Reason |
|---|---|---|---|
| Flash select net name | `N$12` | `QSPI_SS_N` | Give the repaired dedicated interface an explicit name. |
| Flash select members | U3.1, R4.1, R6.2 | U1.56, U3.1, R4.1, R6.2 | Connect RP2040 `QSPI_SS_N` to W25Q128 `!CS`. |
| Flash select routing | 3 bottom-copper segments | 14 bottom-copper segments | Add one continuous 0.2032 mm trace outside the existing QSPI bundle. |
| Components / footprints | No change | No change | The repair is copper-only. |

No other keyboard signal membership changed.

### Main board

| Item | Upstream | Rev A Fixed | Reason |
|---|---|---|---|
| `PWR_BUTTON` members | U1.92, X1203 `PWR_SW`, J16.B3 | Same plus TP15 | Accessible X1203 button wire pad. |
| `PWR_BUTTON` vias | 5 | 4 | The 0.35 mm via at (66.04, 33.655) is replaced by plated through-hole TP15 at the same coordinate. |
| `GND` members | Existing ground members | Same plus TP16 | Second accessible X1203 button wire pad. |
| DSI J1.22 | Direct member of `CM5_3.3V` | Removed from `CM5_3.3V` | Prevent display back-powering by default. |
| JP5.1 | Absent | `CM5_3.3V` | Host side of series jumper. |
| `DSI_3V3` | Absent | JP5.2 and J1.22 | Isolated connector-side supply net. |
| New board elements | None | TP15, TP16, JP5 | Two wire pads and one normally-open solder jumper. |

No other main-board signal membership changed.

## Footprint differences

- TP15 and TP16 use `testpad:P1-13`: 1.3208 mm plated hole, 2.159 mm octagonal pad.
- JP5 uses `CMDeck-Jumpers:SJ_2_NO`: two 1.2 x 1.5 mm top pads on 1.5 mm centers, producing a 0.3 mm default copper gap. Both pads have paste disabled.
- JP5 contains no copper wire, polygon, or rectangle joining its pads; it is physically normally open.
- Added top silkscreen identifies `X1203 BTN`, `PWR`, and `GND`. JP5 carries its reference designator.

## BOM and pick-and-place comparison

No assembled electrical component was added:

- TP15 and TP16 are plated PCB wire pads.
- JP5 is a bare solder-jumper land pattern.
- All three are DNP and require no purchased part.

Therefore the assembly BOM is intended to remain electrically identical. A Fusion/EAGLE placement export may list TP15, TP16, and JP5 as front-side board elements; those rows must be marked DNP or filtered from the assembler placement list. Exact fresh BOM and front/back placement comparisons are blocked until Fusion/EAGLE export is available.

## Expected fabrication-layer differences

These are source-derived expectations, not substitutes for Gerber comparison:

- Keyboard bottom copper: the new `QSPI_SS_N` route only.
- Main top copper: JP5 pads and separated DSI 3V3 traces.
- Main copper/mask/drill: TP15 and TP16 plated wire pads; TP15 replaces one small via.
- Main top silkscreen: X1203 button labels and JP5 reference.
- Main drill data: remove one 0.35 mm via hit; add two 1.3208 mm plated hits, for a net increase of one drilled hole.
- Main plane clearances/thermals: must be regenerated around both new plated holes by Fusion/EAGLE.

## Existing upstream fabrication files

`git diff 66e5f08 -- pcbs/keyboard/fab pcbs/main\ board/fab boms` is empty. The checked-in Gerbers, drills, BOMs, PnP files, ODB++ data, and zip archives therefore remain the original unsafe upstream outputs. They were deliberately not relabeled or repackaged as corrected exports.

Fresh Gerber, Excellon, BOM, and PnP comparison is **blocked** because Autodesk Fusion/EAGLE 9.7-compatible electronics tooling is not installed on the workstation.

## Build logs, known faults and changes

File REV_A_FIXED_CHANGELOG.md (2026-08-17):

# CMDeck Rev A Fixed Changelog

Baseline: upstream commit `66e5f08`.

## Keyboard PCB

### Flash chip select

- Renamed anonymous net `N$12` to `QSPI_SS_N` in both schematic and board.
- Connected RP2040 U1 logical pin `QSPI_SS_N`, physical pad 56, to the existing flash-select network.
- The completed net contains:
  - U1 pad 56: RP2040 `QSPI_SS_N`
  - U3 pad 1: W25Q128JVSIM `!CS`
  - R4 pad 1: 10 kOhm pull-up branch to 3V3
  - R6 pad 2: BOOT-button series branch
- Added a 0.2032 mm bottom-copper route around the outside of the existing QSPI bundle. Centerline spacing follows the board's existing 0.1524 mm QSPI clearance pattern.
- Firmware is unchanged. RP2040's boot ROM and QSPI/XIP hardware use this dedicated pin; QMK pin configuration is not involved.

## Main PCB

### X1203 external power-button pads

- Added TP15 on `PWR_BUTTON` at board coordinate (66.04 mm, 33.655 mm).
- Added TP16 on `GND` at board coordinate (68.84 mm, 33.655 mm).
- Both use `testpad:P1-13`, with a 1.3208 mm plated hole and a 2.159 mm octagonal pad.
- TP15 replaces the existing same-net 0.35 mm via at its coordinate, preserving the original top-to-bottom electrical transition.
- Added top-silkscreen labels: `X1203 BTN`, `PWR`, and `GND`.

Assembly instructions:

1. Use two insulated wires suitable for the enclosure routing.
2. Connect TP15 (`PWR`) and TP16 (`GND`) to the X1203's two-pin external power-button connector.
3. Polarity is not significant for this dry-contact switch connection.
4. Do not connect these pads to an X1203 battery connector or 5 V output connector.
5. Pressing the CMDeck keyboard power button shorts `PWR_BUTTON` to `GND` momentarily, in parallel with the X1203 external-button input.

### DSI 3V3 isolation

- Added JP5 using `CMDeck-Jumpers:SJ_2_NO` at board coordinate (181.94 mm, 46.4796 mm).
- JP5 pad 1 is on `CM5_3.3V`.
- JP5 pad 2 and DSI connector J1 pin 22 are on new net `DSI_3V3`.
- Footprint: two 1.2 x 1.5 mm top pads, 1.5 mm center-to-center, 0.3 mm copper gap, no paste apertures.
- Default assembly state: **OPEN / DO NOT BRIDGE**.
- The documented Waveshare display is powered separately from 5 V and was observed by the creator to back-feed approximately 3 V through DSI when J1.22 was connected. Leave JP5 open for this assembly.
- Bridge JP5 only for a separately verified DSI peripheral that needs host-supplied 3V3 and cannot back-power the carrier.

## Unchanged behavior

- No firmware files changed.
- No existing component placement, board outline, mounting geometry, stackup, connector assignment, or unrelated net membership changed.
- The documented 1.6 mm, four-layer, 1 oz outer/inner stackup file is unchanged.
- Existing upstream fabrication data is unchanged and remains unsafe.

## Validation artifacts

- `tools/validate_rev_a_fixed.py` checks schematic/board part consistency, embedded footprint pads, exact repaired net membership, all unrelated endpoint-to-net assignments, pre-existing component placements, jumper default geometry, and unchanged firmware.
- `verification/upstream-comparison/README.md` explains every source-level difference and the blocked manufacturing comparisons.

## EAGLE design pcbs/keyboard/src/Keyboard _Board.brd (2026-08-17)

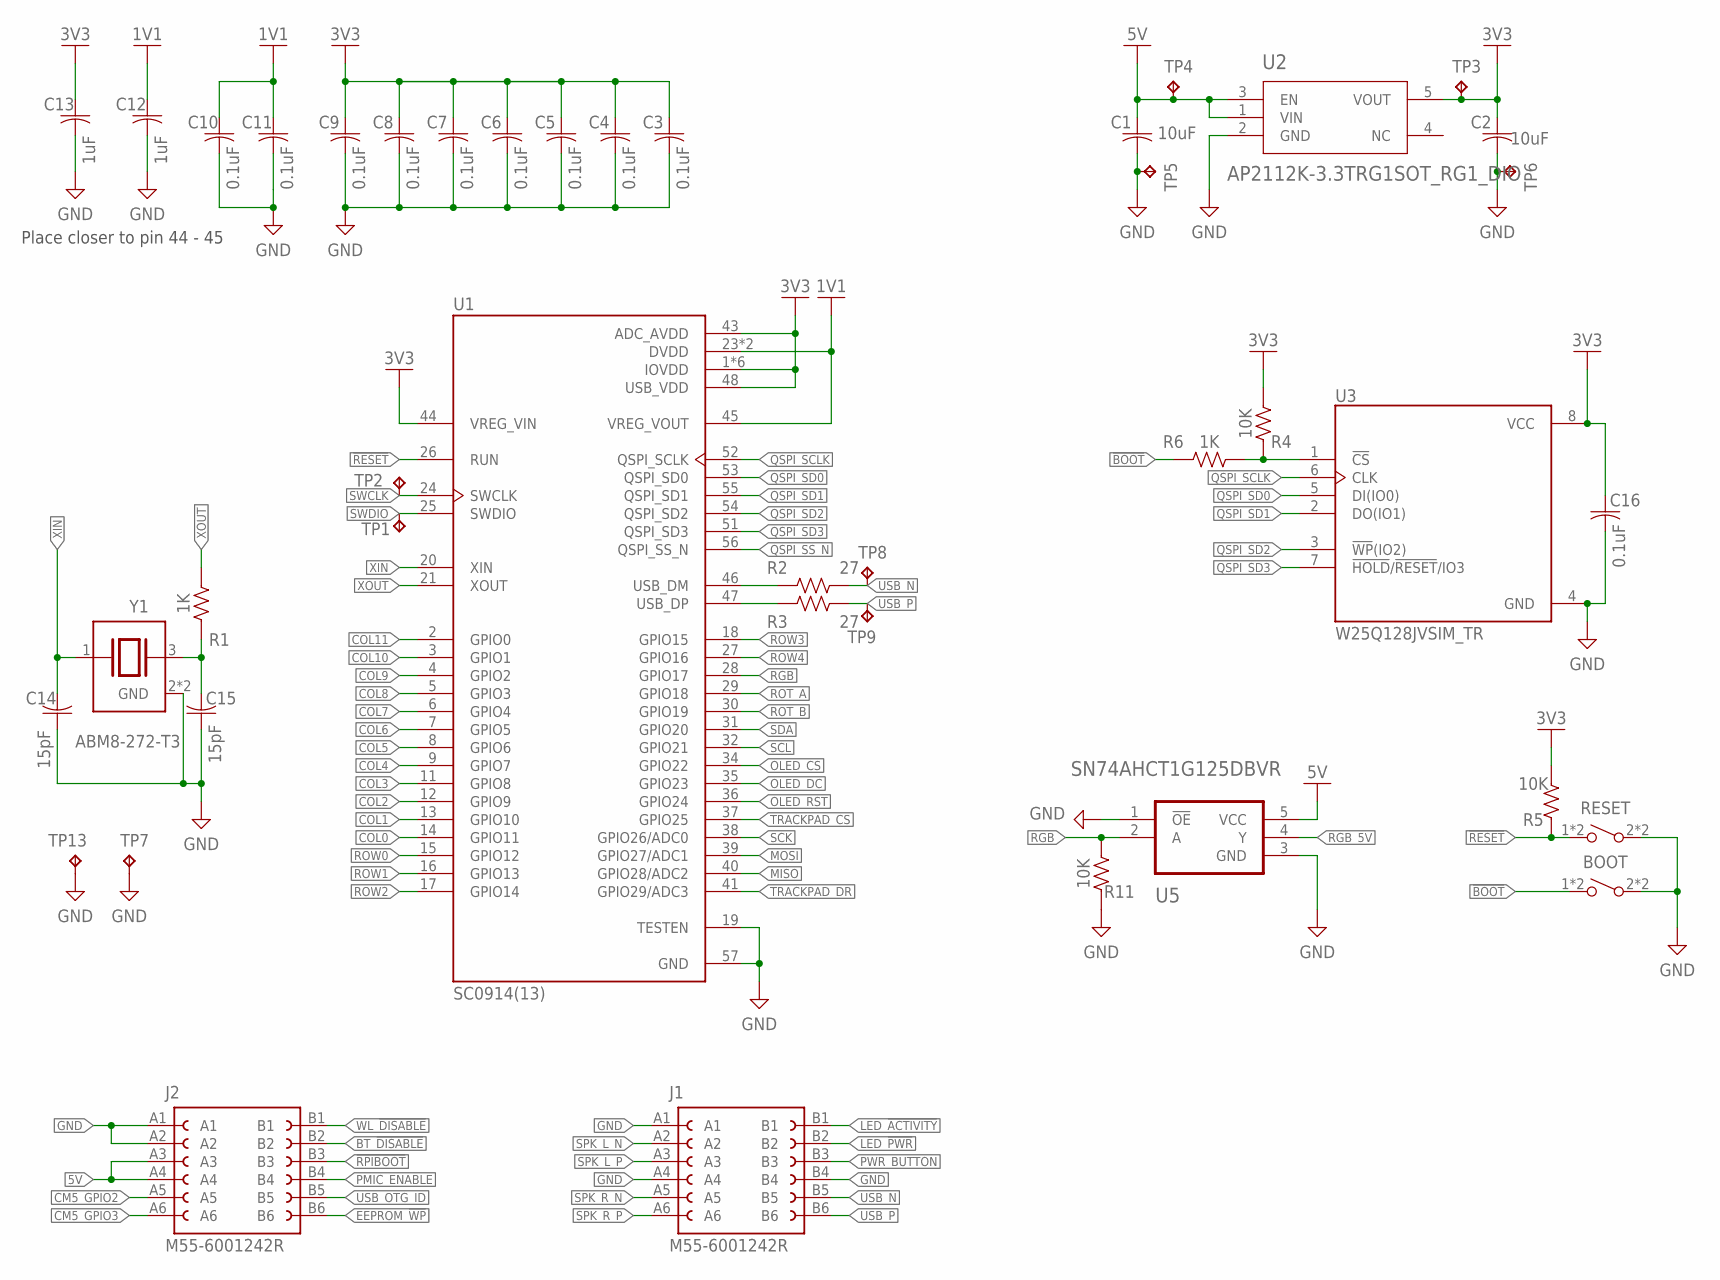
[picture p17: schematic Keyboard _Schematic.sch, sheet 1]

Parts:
BOOT: SPST-NO_SWITCH_KMR2; KMR2
C1, C2: 10uF; CAPC3216X135
C3, C4, C5, C6, C7, C8, C9, C10, C11, C16: 0.1uF; CAPC2012X110
C12, C13: 1uF; CAPC2012X110
C14, C15: 15pF; CAPC2012X110
J1, J2: M55-6001242R; HARWIN_M55-6001242R
R1, R6: 1K; RESC2012X65
R2, R3: 27; RESC2012X65
R4, R5, R11: 10K; RESC2012X65
RESET: SPST-NO_SWITCH_KMR2; KMR2
TP1, TP2, TP3, TP5, TP13: TPB2,54; B2,54
TP4, TP6, TP7, TP8, TP9: TPB1,27; B1,27
U1: SC0914(13); QFN40P700X700X90-57N
U2: AP2112K-3.3TRG1SOT_RG1_DIO; SOT_RG1_DIO
U3: W25Q128JVSIM_TR; SOIC127P790X216-8N
U5: SN74AHCT1G125DBVR; SOT95P280X145-5N
Y1: ABM8-272-T3; XTAL_ABM8-272-T3

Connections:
1V1: C10.1, C11.1, C12.1, U1.23 (DVDD), U1.45 (VREG_VOUT), U1.50 (DVDD)
3V3: C2.1, C3.1, C4.1, C5.1, C6.1, C7.1, C8.1, C9.1, C13.1, C16.1, R4.2, R5.2, TP3.TP, U1.1 (IOVDD), U1.10 (IOVDD), U1.22 (IOVDD), U1.33 (IOVDD), U1.42 (IOVDD), U1.43 (ADC_AVDD), U1.44 (VREG_VIN), U1.48 (USB_VDD), U1.49 (IOVDD), U2.5 (VOUT), U3.8 (VCC); also elsewhere on the board
5V: C1.1, J2.A3, J2.A4, TP4.TP, U2.1 (VIN), U2.3 (EN), U5.5 (VCC); also elsewhere on the board
!BOOT: BOOT.1, BOOT.4 (1), R6.1
!RESET: R5.1, RESET.1, RESET.4 (1), U1.26 (RUN)
!RPIBOOT: J2.B3; also elsewhere on the board
BT_!DISABLE: J2.B2; also elsewhere on the board
CM5_GPIO2: J2.A5; also elsewhere on the board
CM5_GPIO3: J2.A6; also elsewhere on the board
COL0: U1.14 (GPIO11); also elsewhere on the board
COL1: U1.13 (GPIO10); also elsewhere on the board
COL2: U1.12 (GPIO9); also elsewhere on the board
COL3: U1.11 (GPIO8); also elsewhere on the board
COL4: U1.9 (GPIO7); also elsewhere on the board
COL5: U1.8 (GPIO6); also elsewhere on the board
COL6: U1.7 (GPIO5); also elsewhere on the board
COL7: U1.6 (GPIO4); also elsewhere on the board
COL8: U1.5 (GPIO3); also elsewhere on the board
COL9: U1.4 (GPIO2); also elsewhere on the board
COL10: U1.3 (GPIO1); also elsewhere on the board
COL11: U1.2 (GPIO0); also elsewhere on the board
EEPROM_!WP: J2.B6; also elsewhere on the board
GND: BOOT.2, BOOT.3 (2), C1.2, C2.2, C3.2, C4.2, C5.2, C6.2, C7.2, C8.2, C9.2, C10.2, C11.2, C12.2, C13.2, C14.1, C15.1, C16.2, J1.A1, J1.A4, J1.B4, J2.A1, J2.A2, R11.1, RESET.2, RESET.3 (2), TP5.TP, TP6.TP, TP7.TP, TP13.TP, U1.19 (TESTEN), U1.57 (GND), U2.2 (GND), U3.4 (GND), U5.1 (!OE), U5.3 (GND), Y1.2 (GND), Y1.4 (GND); also elsewhere on the board
LED_!ACTIVITY: J1.B1; also elsewhere on the board
LED_!PWR: J1.B2; also elsewhere on the board
MISO: U1.40 (GPIO28/ADC2); also elsewhere on the board
MOSI: U1.39 (GPIO27/ADC1); also elsewhere on the board
unnamed: C15.2, R1.1, Y1.3
OLED_CS: U1.34 (GPIO22); also elsewhere on the board
OLED_DC: U1.35 (GPIO23); also elsewhere on the board
OLED_RST: U1.36 (GPIO24); also elsewhere on the board
PMIC_ENABLE: J2.B4; also elsewhere on the board
PWR_BUTTON: J1.B3; also elsewhere on the board
QSPI_SCLK: U1.52 (QSPI_SCLK), U3.6 (CLK)
QSPI_SD0: U1.53 (QSPI_SD0), U3.5 (DI(IO0))
QSPI_SD1: U1.55 (QSPI_SD1), U3.2 (DO(IO1))
QSPI_SD2: U1.54 (QSPI_SD2), U3.3 (!WP!(IO2))
QSPI_SD3: U1.51 (QSPI_SD3), U3.7 (!HOLD!/!RESET!/IO3)
QSPI_SS_N: R4.1, R6.2, U1.56 (QSPI_SS_N), U3.1 (!CS)
RGB: R11.2, U1.28 (GPIO17), U5.2 (A)
RGB_5V: U5.4 (Y); also elsewhere on the board
ROT_A: U1.29 (GPIO18); also elsewhere on the board
ROT_B: U1.30 (GPIO19); also elsewhere on the board
ROW0: U1.15 (GPIO12); also elsewhere on the board
ROW1: U1.16 (GPIO13); also elsewhere on the board
ROW2: U1.17 (GPIO14); also elsewhere on the board
ROW3: U1.18 (GPIO15); also elsewhere on the board
ROW4: U1.27 (GPIO16); also elsewhere on the board
SCK: U1.38 (GPIO26/ADC0); also elsewhere on the board
SCL: U1.32 (GPIO21); also elsewhere on the board
SDA: U1.31 (GPIO20); also elsewhere on the board
SPK_L_N: J1.A2; also elsewhere on the board
SPK_L_P: J1.A3; also elsewhere on the board
SPK_R_N: J1.A5; also elsewhere on the board
SPK_R_P: J1.A6; also elsewhere on the board
SWCLK: TP2.TP, U1.24 (SWCLK)
SWDIO: TP1.TP, U1.25 (SWDIO)
TRACKPAD_CS: U1.37 (GPIO25); also elsewhere on the board
TRACKPAD_DR: U1.41 (GPIO29/ADC3); also elsewhere on the board
USB_D_N: R2.1, U1.46 (USB_DM)
USB_D_P: R3.2, U1.47 (USB_DP)
USB_N: J1.B5, R2.2, TP8.TP
USB_OTG_ID: J2.B5; also elsewhere on the board
USB_P: J1.B6, R3.1, TP9.TP
WL_!DISABLE: J2.B1; also elsewhere on the board
XIN: C14.2, U1.20 (XIN), Y1.1
XOUT: R1.2, U1.21 (XOUT)

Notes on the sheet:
Place closer to pin 44 - 45

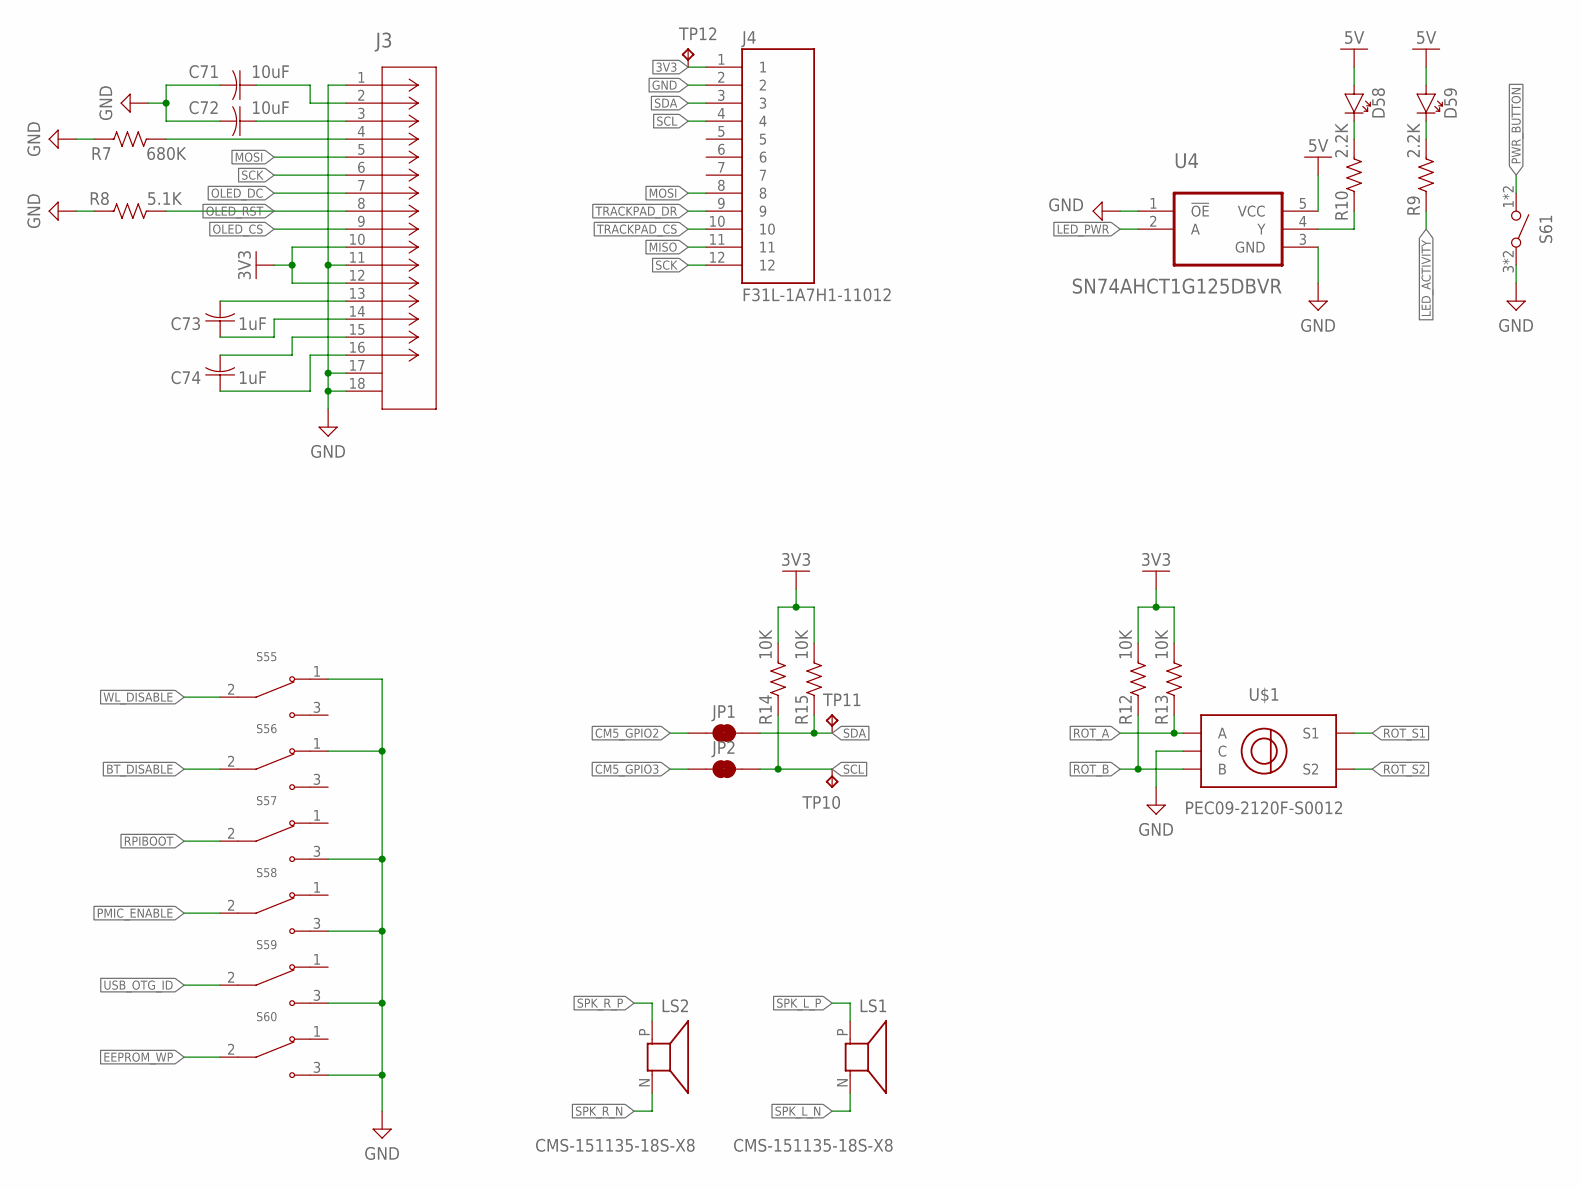
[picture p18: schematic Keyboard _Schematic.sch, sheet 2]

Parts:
C71, C72: 10uF; CAPC3216X135
C73, C74: 1uF; CAPC2012X110
D58, D59: CHIP-FLAT-G_1206; LEDC3216X75N_FLAT-G
J3: 1-1775333-6CONN16_1-1775333-6_TEC; CONN16_1-1775333-6_TEC
J4: F31L-1A7H1-11012; AMPHENOL_F31L-1A7H1-11012
JP1, JP2: JUMPER-SMT_2_NC_TRACE_NO-SILK; SMT-JUMPER_2_NC_TRACE_NO-SILK
LS1, LS2: CMS-151135-18S-X8; SPKR_CMS-151135-18S-X8
R7: 680K; RESC2012X65
R8: 5.1K; RESC2012X65
R9, R10: 2.2K; RESC2012X65
R12, R13, R14, R15: 10K; RESC2012X65
S55, S56, S57, S58, S59, S60: SLW-1277744-3A-N-D; SW_SLW-1277744-3A-N-D
S61: SPST-NO_SWITCH_PTS645-SMT-6MM; PTS645-SMT-6MM
TP10, TP11, TP12: TPB1,27; B1,27
U4: SN74AHCT1G125DBVR; SOT95P280X145-5N
U$1: PEC09-2120F-S0012; PEC09-2XXXF-SXXXX

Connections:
3V3: J3.10, J3.12, J4.1, R12.2, R13.2, R14.2, R15.2, TP12.TP; also elsewhere on the board
5V: D58.A, D59.A, U4.5 (VCC); also elsewhere on the board
!RPIBOOT: S57.2; also elsewhere on the board
BT_!DISABLE: S56.2; also elsewhere on the board
CM5_GPIO2: JP1.1; also elsewhere on the board
CM5_GPIO3: JP2.1; also elsewhere on the board
EEPROM_!WP: S60.2; also elsewhere on the board
GND: C71.2, C72.2, J3.1, J3.11, J3.17, J3.18, J4.2, R7.1, R8.1, S55.1, S56.1, S57.3, S58.3, S59.3, S60.3, S61.3 (2), S61.4 (2), U4.1 (!OE), U4.3 (GND), U$1.P$2 (C); also elsewhere on the board
LED_!ACTIVITY: R9.1; also elsewhere on the board
LED_!PWR: U4.2 (A); also elsewhere on the board
MISO: J4.11; also elsewhere on the board
MOSI: J3.5, J4.8; also elsewhere on the board
unnamed: D59.C, R9.2
unnamed: C71.1, J3.2
unnamed: C72.1, J3.3
unnamed: J3.4, R7.2
unnamed: C73.2, J3.13
unnamed: C73.1, J3.14
unnamed: C74.2, J3.15
unnamed: C74.1, J3.16
unnamed: D58.C, R10.2
unnamed: R10.1, U4.4 (Y)
OLED_CS: J3.9; also elsewhere on the board
OLED_DC: J3.7; also elsewhere on the board
OLED_RST: J3.8, R8.2; also elsewhere on the board
PMIC_ENABLE: S58.2; also elsewhere on the board
PWR_BUTTON: S61.1, S61.2 (1); also elsewhere on the board
ROT_A: R13.1, U$1.P$3 (A); also elsewhere on the board
ROT_B: R12.1, U$1.P$1 (B); also elsewhere on the board
ROT_S1: U$1.P$4 (S1); also elsewhere on the board
ROT_S2: U$1.P$5 (S2); also elsewhere on the board
SCK: J3.6, J4.12; also elsewhere on the board
SCL: J4.4, JP2.2, R14.1, TP10.TP; also elsewhere on the board
SDA: J4.3, JP1.2, R15.1, TP11.TP; also elsewhere on the board
SPK_L_N: LS1.N; also elsewhere on the board
SPK_L_P: LS1.P; also elsewhere on the board
SPK_R_N: LS2.N; also elsewhere on the board
SPK_R_P: LS2.P; also elsewhere on the board
TRACKPAD_CS: J4.10; also elsewhere on the board
TRACKPAD_DR: J4.9; also elsewhere on the board
USB_OTG_ID: S59.2; also elsewhere on the board
WL_!DISABLE: S55.2; also elsewhere on the board

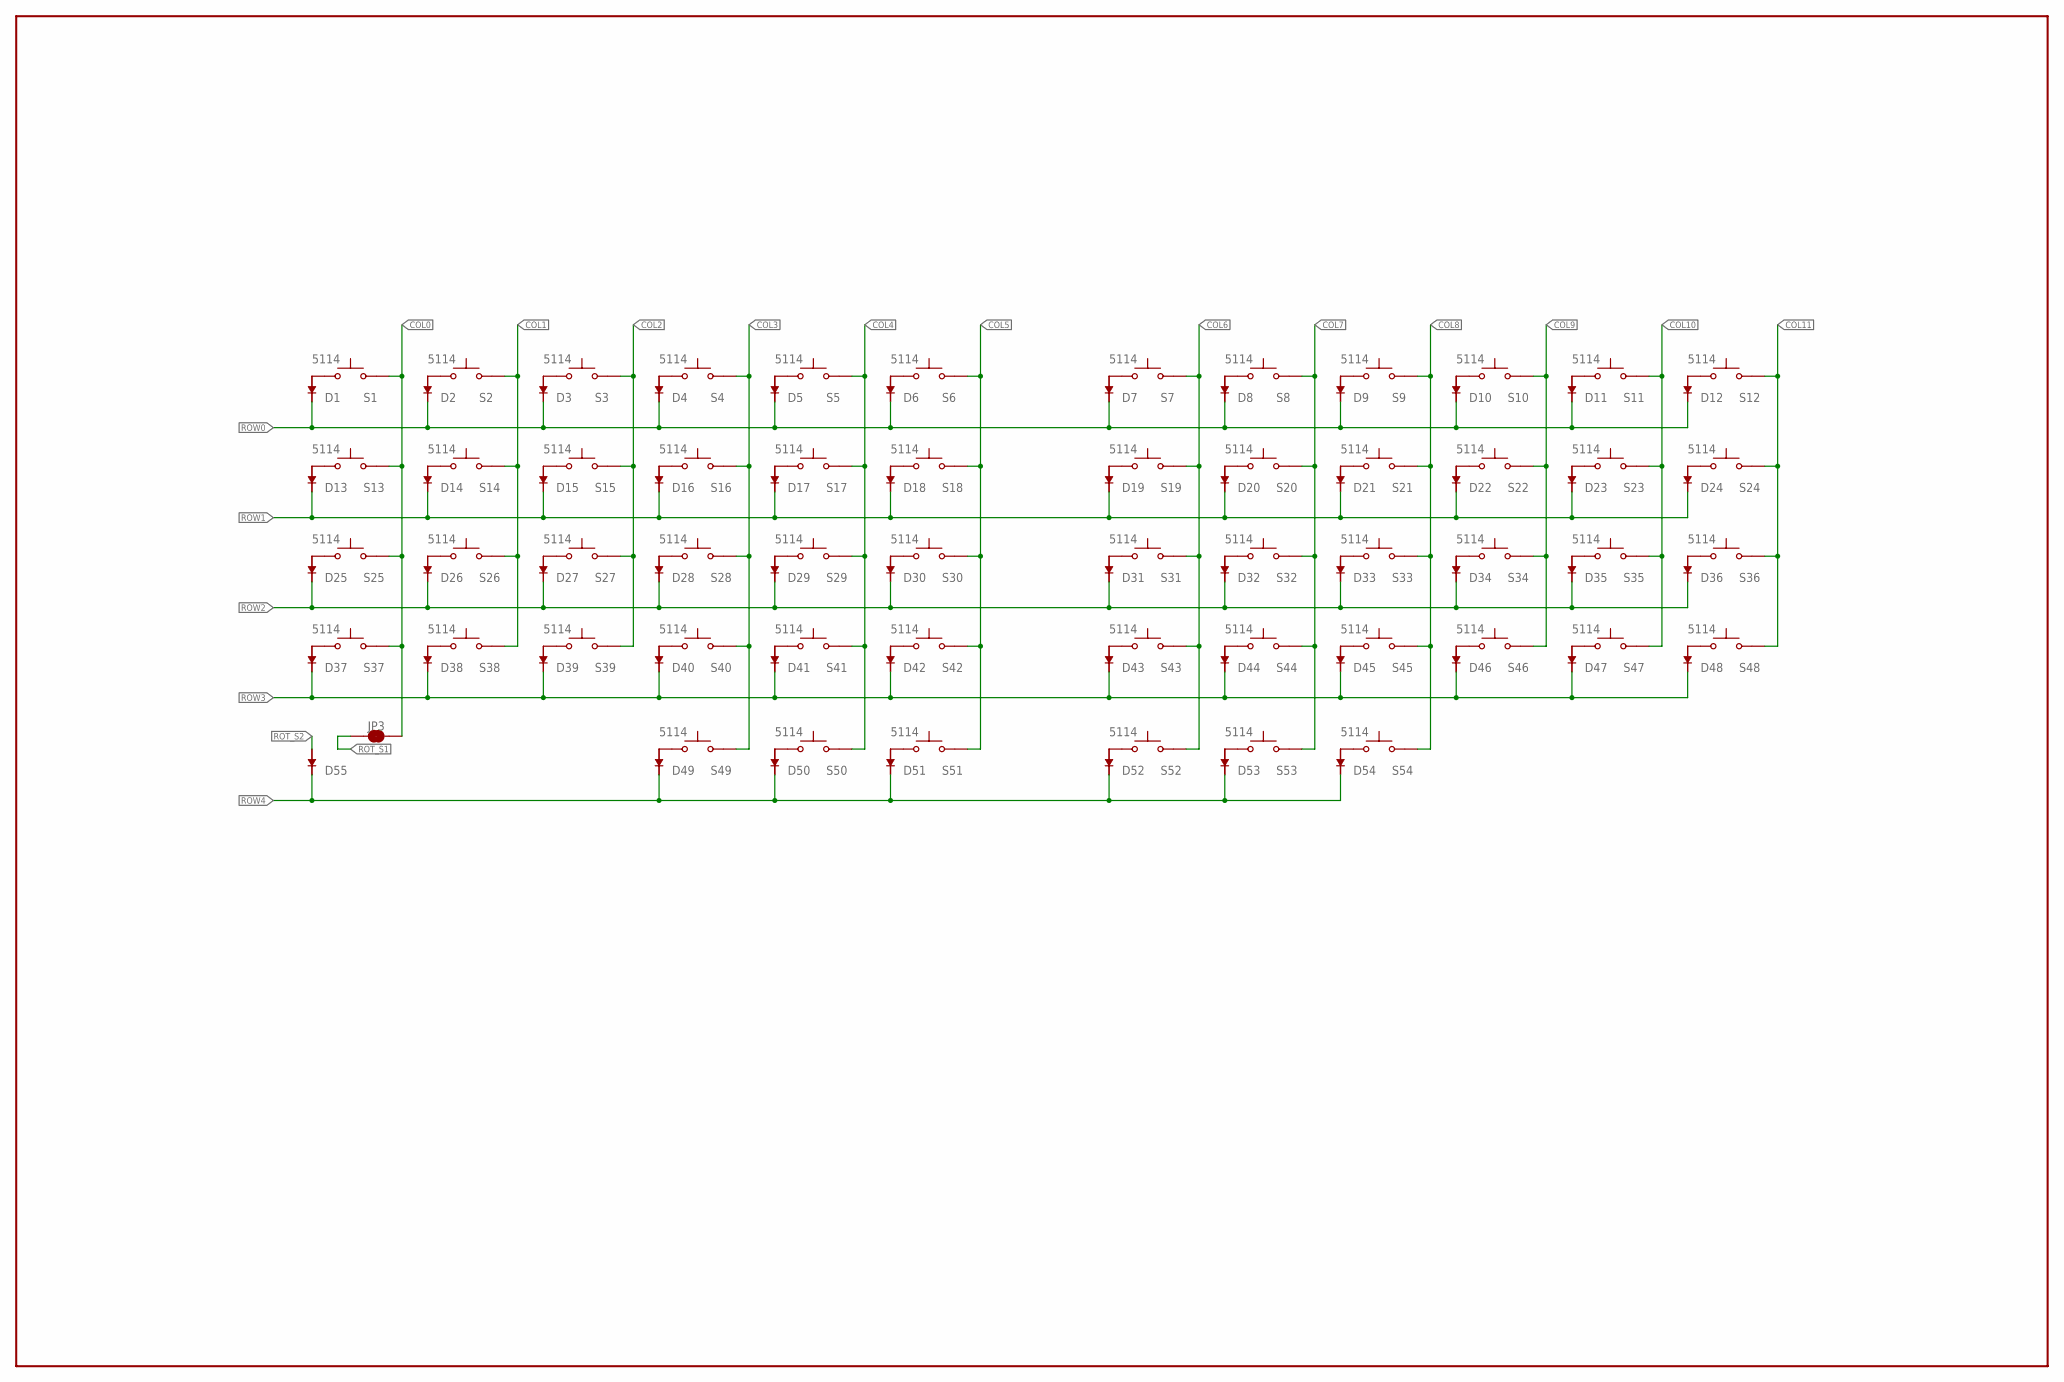
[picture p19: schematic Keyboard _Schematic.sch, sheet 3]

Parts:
D1, D2, D3, D4, D5, D6, D7, D8, D9, D10, D11, D12, D13, D14, D15, D16, D17, D18, D19, D20, D21, D22, D23, D24, D25, D26, D27, D28, D29, D30, D31, D32, D33, D34, D35, D36, D37, D38, D39, D40, D41, D42, D43, D44, D45, D46, D47, D48, D49, D50, D51, D52, D53, D54, D55: 1N4148W; SOD3715X135N
JP3: JUMPER-SMT_2_NC_TRACE_NO-SILK; SMT-JUMPER_2_NC_TRACE_NO-SILK
S1, S2, S3, S4, S5, S6, S7, S8, S9, S10, S11, S12, S13, S14, S15, S16, S17, S18, S19, S20, S21, S22, S23, S24, S25, S26, S27, S28, S29, S30, S31, S32, S33, S34, S35, S36, S37, S38, S39, S40, S41, S42, S43, S44, S45, S46, S47, S48, S49, S50, S51, S52, S53, S54: 5114; SW_5114

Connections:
COL0: JP3.1, S1.P$2 (2), S13.P$2 (2), S25.P$2 (2), S37.P$2 (2); also elsewhere on the board
COL1: S2.P$2 (2), S14.P$2 (2), S26.P$2 (2), S38.P$2 (2); also elsewhere on the board
COL2: S3.P$2 (2), S15.P$2 (2), S27.P$2 (2), S39.P$2 (2); also elsewhere on the board
COL3: S4.P$2 (2), S16.P$2 (2), S28.P$2 (2), S40.P$2 (2), S49.P$2 (2); also elsewhere on the board
COL4: S5.P$2 (2), S17.P$2 (2), S29.P$2 (2), S41.P$2 (2), S50.P$2 (2); also elsewhere on the board
COL5: S6.P$2 (2), S18.P$2 (2), S30.P$2 (2), S42.P$2 (2), S51.P$2 (2); also elsewhere on the board
COL6: S7.P$2 (2), S19.P$2 (2), S31.P$2 (2), S43.P$2 (2), S52.P$2 (2); also elsewhere on the board
COL7: S8.P$2 (2), S20.P$2 (2), S32.P$2 (2), S44.P$2 (2), S53.P$2 (2); also elsewhere on the board
COL8: S9.P$2 (2), S21.P$2 (2), S33.P$2 (2), S45.P$2 (2), S54.P$2 (2); also elsewhere on the board
COL9: S10.P$2 (2), S22.P$2 (2), S34.P$2 (2), S46.P$2 (2); also elsewhere on the board
COL10: S11.P$2 (2), S23.P$2 (2), S35.P$2 (2), S47.P$2 (2); also elsewhere on the board
COL11: S12.P$2 (2), S24.P$2 (2), S36.P$2 (2), S48.P$2 (2); also elsewhere on the board
unnamed: D1.A, S1.P$1 (1)
unnamed: D2.A, S2.P$1 (1)
unnamed: D3.A, S3.P$1 (1)
unnamed: D4.A, S4.P$1 (1)
unnamed: D5.A, S5.P$1 (1)
unnamed: D6.A, S6.P$1 (1)
unnamed: D7.A, S7.P$1 (1)
unnamed: D8.A, S8.P$1 (1)
unnamed: D9.A, S9.P$1 (1)
unnamed: D10.A, S10.P$1 (1)
unnamed: D11.A, S11.P$1 (1)
unnamed: D12.A, S12.P$1 (1)
unnamed: D13.A, S13.P$1 (1)
unnamed: D14.A, S14.P$1 (1)
unnamed: D15.A, S15.P$1 (1)
unnamed: D16.A, S16.P$1 (1)
unnamed: D17.A, S17.P$1 (1)
unnamed: D18.A, S18.P$1 (1)
unnamed: D19.A, S19.P$1 (1)
unnamed: D20.A, S20.P$1 (1)
unnamed: D21.A, S21.P$1 (1)
unnamed: D22.A, S22.P$1 (1)
unnamed: D23.A, S23.P$1 (1)
unnamed: D24.A, S24.P$1 (1)
unnamed: D25.A, S25.P$1 (1)
unnamed: D26.A, S26.P$1 (1)
unnamed: D27.A, S27.P$1 (1)
unnamed: D28.A, S28.P$1 (1)
unnamed: D29.A, S29.P$1 (1)
unnamed: D30.A, S30.P$1 (1)
unnamed: D31.A, S31.P$1 (1)
unnamed: D32.A, S32.P$1 (1)
unnamed: D33.A, S33.P$1 (1)
unnamed: D34.A, S34.P$1 (1)
unnamed: D35.A, S35.P$1 (1)
unnamed: D36.A, S36.P$1 (1)
unnamed: D37.A, S37.P$1 (1)
unnamed: D38.A, S38.P$1 (1)
unnamed: D39.A, S39.P$1 (1)
unnamed: D40.A, S40.P$1 (1)
unnamed: D41.A, S41.P$1 (1)
unnamed: D42.A, S42.P$1 (1)
unnamed: D43.A, S43.P$1 (1)
unnamed: D44.A, S44.P$1 (1)
unnamed: D45.A, S45.P$1 (1)
unnamed: D46.A, S46.P$1 (1)
unnamed: D47.A, S47.P$1 (1)
unnamed: D48.A, S48.P$1 (1)
unnamed: D49.A, S49.P$1 (1)
unnamed: D50.A, S50.P$1 (1)
unnamed: D51.A, S51.P$1 (1)
unnamed: D52.A, S52.P$1 (1)
unnamed: D53.A, S53.P$1 (1)
unnamed: D54.A, S54.P$1 (1)
ROT_S1: JP3.2; also elsewhere on the board
ROT_S2: D55.A; also elsewhere on the board
ROW0: D1.C (K), D2.C (K), D3.C (K), D4.C (K), D5.C (K), D6.C (K), D7.C (K), D8.C (K), D9.C (K), D10.C (K), D11.C (K), D12.C (K); also elsewhere on the board
ROW1: D13.C (K), D14.C (K), D15.C (K), D16.C (K), D17.C (K), D18.C (K), D19.C (K), D20.C (K), D21.C (K), D22.C (K), D23.C (K), D24.C (K); also elsewhere on the board
ROW2: D25.C (K), D26.C (K), D27.C (K), D28.C (K), D29.C (K), D30.C (K), D31.C (K), D32.C (K), D33.C (K), D34.C (K), D35.C (K), D36.C (K); also elsewhere on the board
ROW3: D37.C (K), D38.C (K), D39.C (K), D40.C (K), D41.C (K), D42.C (K), D43.C (K), D44.C (K), D45.C (K), D46.C (K), D47.C (K), D48.C (K); also elsewhere on the board
ROW4: D49.C (K), D50.C (K), D51.C (K), D52.C (K), D53.C (K), D54.C (K), D55.C (K); also elsewhere on the board

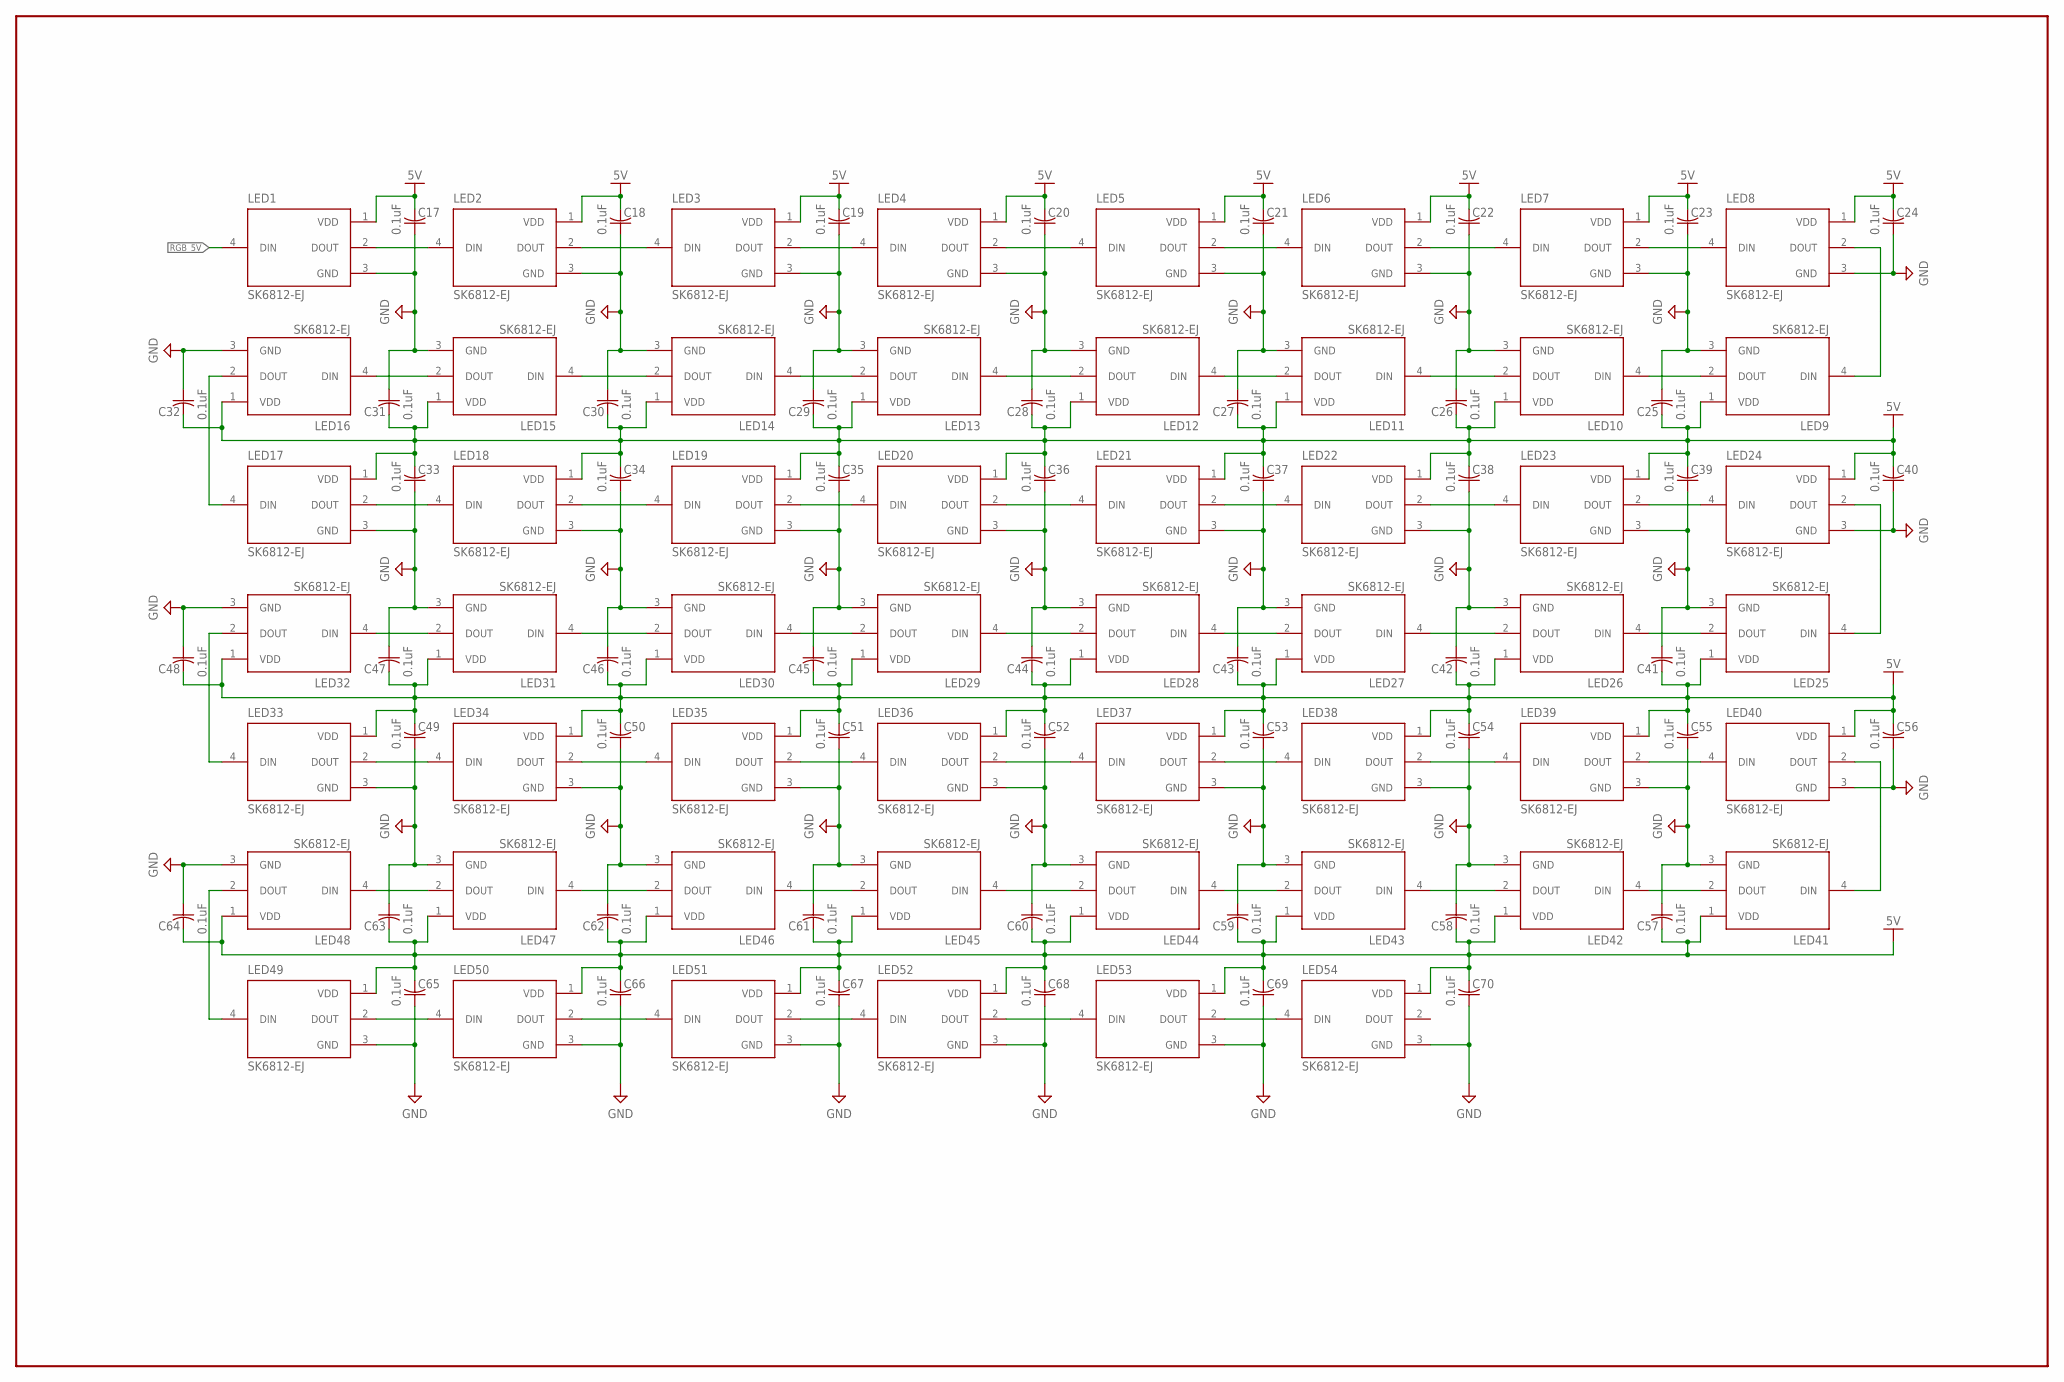
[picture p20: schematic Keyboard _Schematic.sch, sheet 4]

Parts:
C17, C18, C19, C20, C21, C22, C23, C24, C25, C26, C27, C28, C29, C30, C31, C32, C33, C34, C35, C36, C37, C38, C39, C40, C41, C42, C43, C44, C45, C46, C47, C48, C49, C50, C51, C52, C53, C54, C55, C56, C57, C58, C59, C60, C61, C62, C63, C64, C65, C66, C67, C68, C69, C70: 0.1uF; CAPC2012X110
LED1, LED2, LED3, LED4, LED5, LED6, LED7, LED8, LED9, LED10, LED11, LED12, LED13, LED14, LED15, LED16, LED17, LED18, LED19, LED20, LED21, LED22, LED23, LED24, LED25, LED26, LED27, LED28, LED29, LED30, LED31, LED32, LED33, LED34, LED35, LED36, LED37, LED38, LED39, LED40, LED41, LED42, LED43, LED44, LED45, LED46, LED47, LED48, LED49, LED50, LED51, LED52, LED53, LED54: SK6812-EJ; LED_SK6812-E

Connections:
5V: C17.2, C18.2, C19.2, C20.2, C21.2, C22.2, C23.2, C24.2, C25.2, C26.2, C27.2, C28.2, C29.2, C30.2, C31.2, C32.2, C33.2, C34.2, C35.2, C36.2, C37.2, C38.2, C39.2, C40.2, C41.2, C42.2, C43.2, C44.2, C45.2, C46.2, C47.2, C48.2, C49.2, C50.2, C51.2, C52.2, C53.2, C54.2, C55.2, C56.2, C57.2, C58.2, C59.2, C60.2, C61.2, C62.2, C63.2, C64.2, C65.2, C66.2, C67.2, C68.2, C69.2, C70.2, LED1.1 (VDD), LED2.1 (VDD), LED3.1 (VDD), LED4.1 (VDD), LED5.1 (VDD), LED6.1 (VDD), LED7.1 (VDD), LED8.1 (VDD), LED9.1 (VDD), LED10.1 (VDD), LED11.1 (VDD), LED12.1 (VDD), LED13.1 (VDD), LED14.1 (VDD), LED15.1 (VDD), LED16.1 (VDD), LED17.1 (VDD), LED18.1 (VDD), LED19.1 (VDD), LED20.1 (VDD), LED21.1 (VDD), LED22.1 (VDD), LED23.1 (VDD), LED24.1 (VDD), LED25.1 (VDD), LED26.1 (VDD), LED27.1 (VDD), LED28.1 (VDD), LED29.1 (VDD), LED30.1 (VDD), LED31.1 (VDD), LED32.1 (VDD), LED33.1 (VDD), LED34.1 (VDD), LED35.1 (VDD), LED36.1 (VDD), LED37.1 (VDD), LED38.1 (VDD), LED39.1 (VDD), LED40.1 (VDD), LED41.1 (VDD), LED42.1 (VDD), LED43.1 (VDD), LED44.1 (VDD), LED45.1 (VDD), LED46.1 (VDD), LED47.1 (VDD), LED48.1 (VDD), LED49.1 (VDD), LED50.1 (VDD), LED51.1 (VDD), LED52.1 (VDD), LED53.1 (VDD), LED54.1 (VDD); also elsewhere on the board
GND: C17.1, C18.1, C19.1, C20.1, C21.1, C22.1, C23.1, C24.1, C25.1, C26.1, C27.1, C28.1, C29.1, C30.1, C31.1, C32.1, C33.1, C34.1, C35.1, C36.1, C37.1, C38.1, C39.1, C40.1, C41.1, C42.1, C43.1, C44.1, C45.1, C46.1, C47.1, C48.1, C49.1, C50.1, C51.1, C52.1, C53.1, C54.1, C55.1, C56.1, C57.1, C58.1, C59.1, C60.1, C61.1, C62.1, C63.1, C64.1, C65.1, C66.1, C67.1, C68.1, C69.1, C70.1, LED1.3 (GND), LED2.3 (GND), LED3.3 (GND), LED4.3 (GND), LED5.3 (GND), LED6.3 (GND), LED7.3 (GND), LED8.3 (GND), LED9.3 (GND), LED10.3 (GND), LED11.3 (GND), LED12.3 (GND), LED13.3 (GND), LED14.3 (GND), LED15.3 (GND), LED16.3 (GND), LED17.3 (GND), LED18.3 (GND), LED19.3 (GND), LED20.3 (GND), LED21.3 (GND), LED22.3 (GND), LED23.3 (GND), LED24.3 (GND), LED25.3 (GND), LED26.3 (GND), LED27.3 (GND), LED28.3 (GND), LED29.3 (GND), LED30.3 (GND), LED31.3 (GND), LED32.3 (GND), LED33.3 (GND), LED34.3 (GND), LED35.3 (GND), LED36.3 (GND), LED37.3 (GND), LED38.3 (GND), LED39.3 (GND), LED40.3 (GND), LED41.3 (GND), LED42.3 (GND), LED43.3 (GND), LED44.3 (GND), LED45.3 (GND), LED46.3 (GND), LED47.3 (GND), LED48.3 (GND), LED49.3 (GND), LED50.3 (GND), LED51.3 (GND), LED52.3 (GND), LED53.3 (GND), LED54.3 (GND); also elsewhere on the board
unnamed: LED8.2 (DOUT), LED9.4 (DIN)
unnamed: LED24.2 (DOUT), LED25.4 (DIN)
unnamed: LED1.2 (DOUT), LED2.4 (DIN)
unnamed: LED17.2 (DOUT), LED18.4 (DIN)
unnamed: LED3.2 (DOUT), LED4.4 (DIN)
unnamed: LED2.2 (DOUT), LED3.4 (DIN)
unnamed: LED5.2 (DOUT), LED6.4 (DIN)
unnamed: LED19.2 (DOUT), LED20.4 (DIN)
unnamed: LED40.2 (DOUT), LED41.4 (DIN)
unnamed: LED18.2 (DOUT), LED19.4 (DIN)
unnamed: LED7.2 (DOUT), LED8.4 (DIN)
unnamed: LED6.2 (DOUT), LED7.4 (DIN)
unnamed: LED4.2 (DOUT), LED5.4 (DIN)
unnamed: LED9.2 (DOUT), LED10.4 (DIN)
unnamed: LED21.2 (DOUT), LED22.4 (DIN)
unnamed: LED11.2 (DOUT), LED12.4 (DIN)
unnamed: LED10.2 (DOUT), LED11.4 (DIN)
unnamed: LED13.2 (DOUT), LED14.4 (DIN)
unnamed: LED23.2 (DOUT), LED24.4 (DIN)
unnamed: LED22.2 (DOUT), LED23.4 (DIN)
unnamed: LED15.2 (DOUT), LED16.4 (DIN)
unnamed: LED14.2 (DOUT), LED15.4 (DIN)
unnamed: LED12.2 (DOUT), LED13.4 (DIN)
unnamed: LED20.2 (DOUT), LED21.4 (DIN)
unnamed: LED25.2 (DOUT), LED26.4 (DIN)
unnamed: LED27.2 (DOUT), LED28.4 (DIN)
unnamed: LED26.2 (DOUT), LED27.4 (DIN)
unnamed: LED29.2 (DOUT), LED30.4 (DIN)
unnamed: LED31.2 (DOUT), LED32.4 (DIN)
unnamed: LED30.2 (DOUT), LED31.4 (DIN)
unnamed: LED28.2 (DOUT), LED29.4 (DIN)
unnamed: LED16.2 (DOUT), LED17.4 (DIN)
unnamed: LED33.2 (DOUT), LED34.4 (DIN)
unnamed: LED35.2 (DOUT), LED36.4 (DIN)
unnamed: LED34.2 (DOUT), LED35.4 (DIN)
unnamed: LED37.2 (DOUT), LED38.4 (DIN)
unnamed: LED39.2 (DOUT), LED40.4 (DIN)
unnamed: LED38.2 (DOUT), LED39.4 (DIN)
unnamed: LED36.2 (DOUT), LED37.4 (DIN)
unnamed: LED41.2 (DOUT), LED42.4 (DIN)
unnamed: LED43.2 (DOUT), LED44.4 (DIN)
unnamed: LED42.2 (DOUT), LED43.4 (DIN)
unnamed: LED45.2 (DOUT), LED46.4 (DIN)
unnamed: LED47.2 (DOUT), LED48.4 (DIN)
unnamed: LED46.2 (DOUT), LED47.4 (DIN)
unnamed: LED44.2 (DOUT), LED45.4 (DIN)
unnamed: LED32.2 (DOUT), LED33.4 (DIN)
unnamed: LED49.2 (DOUT), LED50.4 (DIN)
unnamed: LED51.2 (DOUT), LED52.4 (DIN)
unnamed: LED50.2 (DOUT), LED51.4 (DIN)
unnamed: LED53.2 (DOUT), LED54.4 (DIN)
unnamed: LED48.2 (DOUT), LED49.4 (DIN)
unnamed: LED52.2 (DOUT), LED53.4 (DIN)
RGB_5V: LED1.4 (DIN); also elsewhere on the board

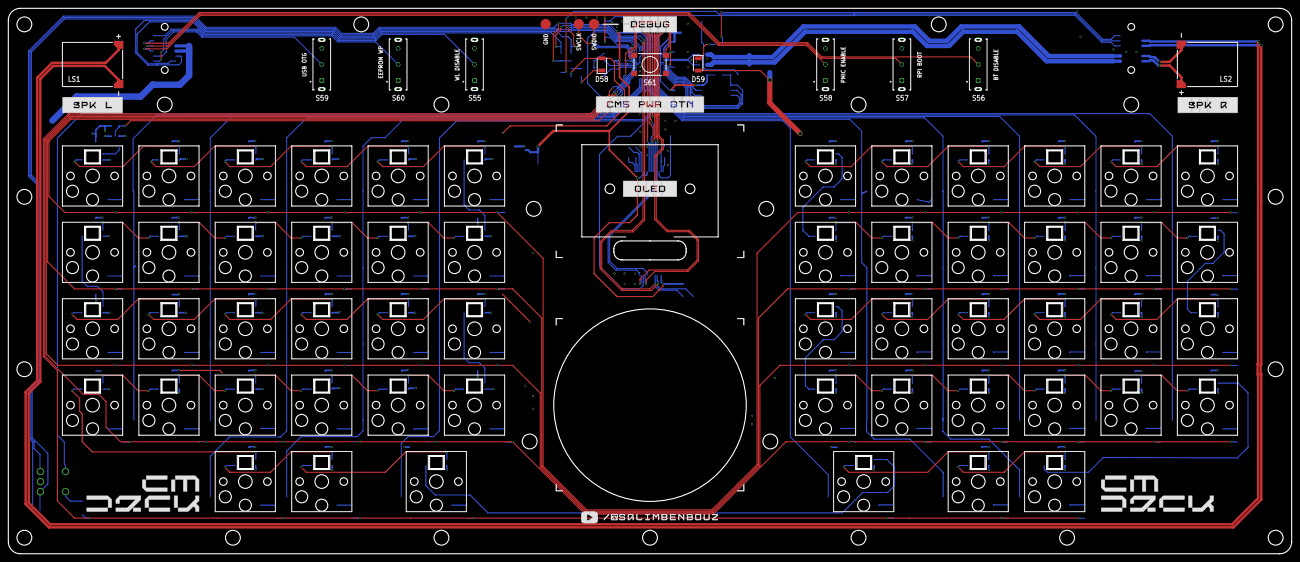
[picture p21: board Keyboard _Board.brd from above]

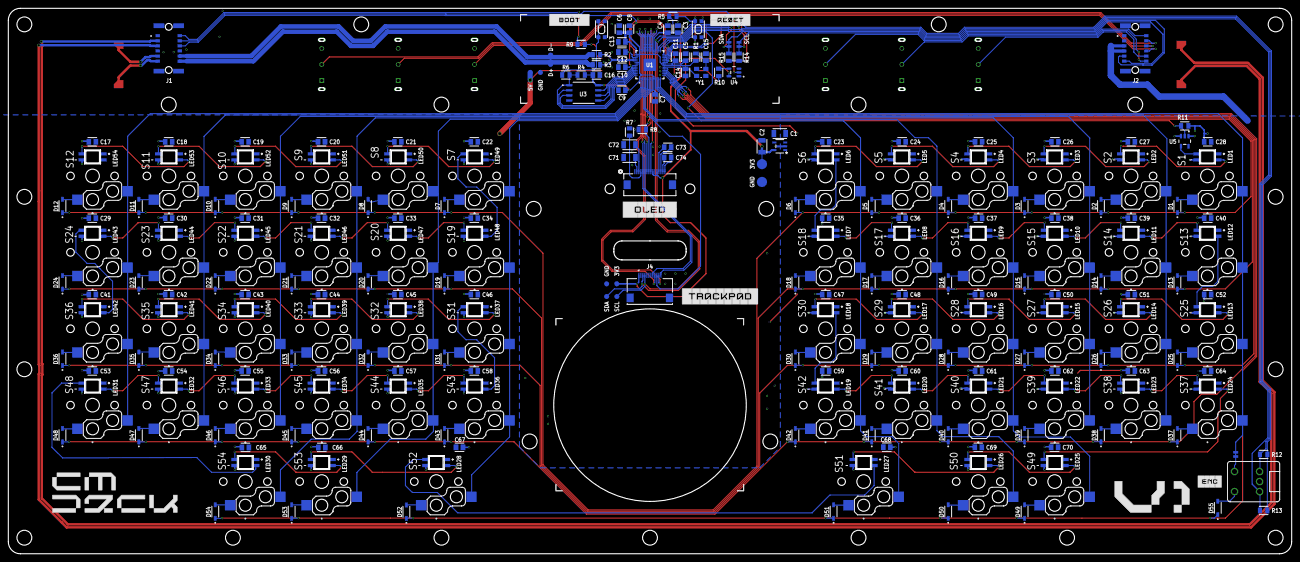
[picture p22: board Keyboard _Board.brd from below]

Board: 2 copper layers, 320.0 x 136.0 mm, 292 parts (278 on the bottom side), 186 nets.

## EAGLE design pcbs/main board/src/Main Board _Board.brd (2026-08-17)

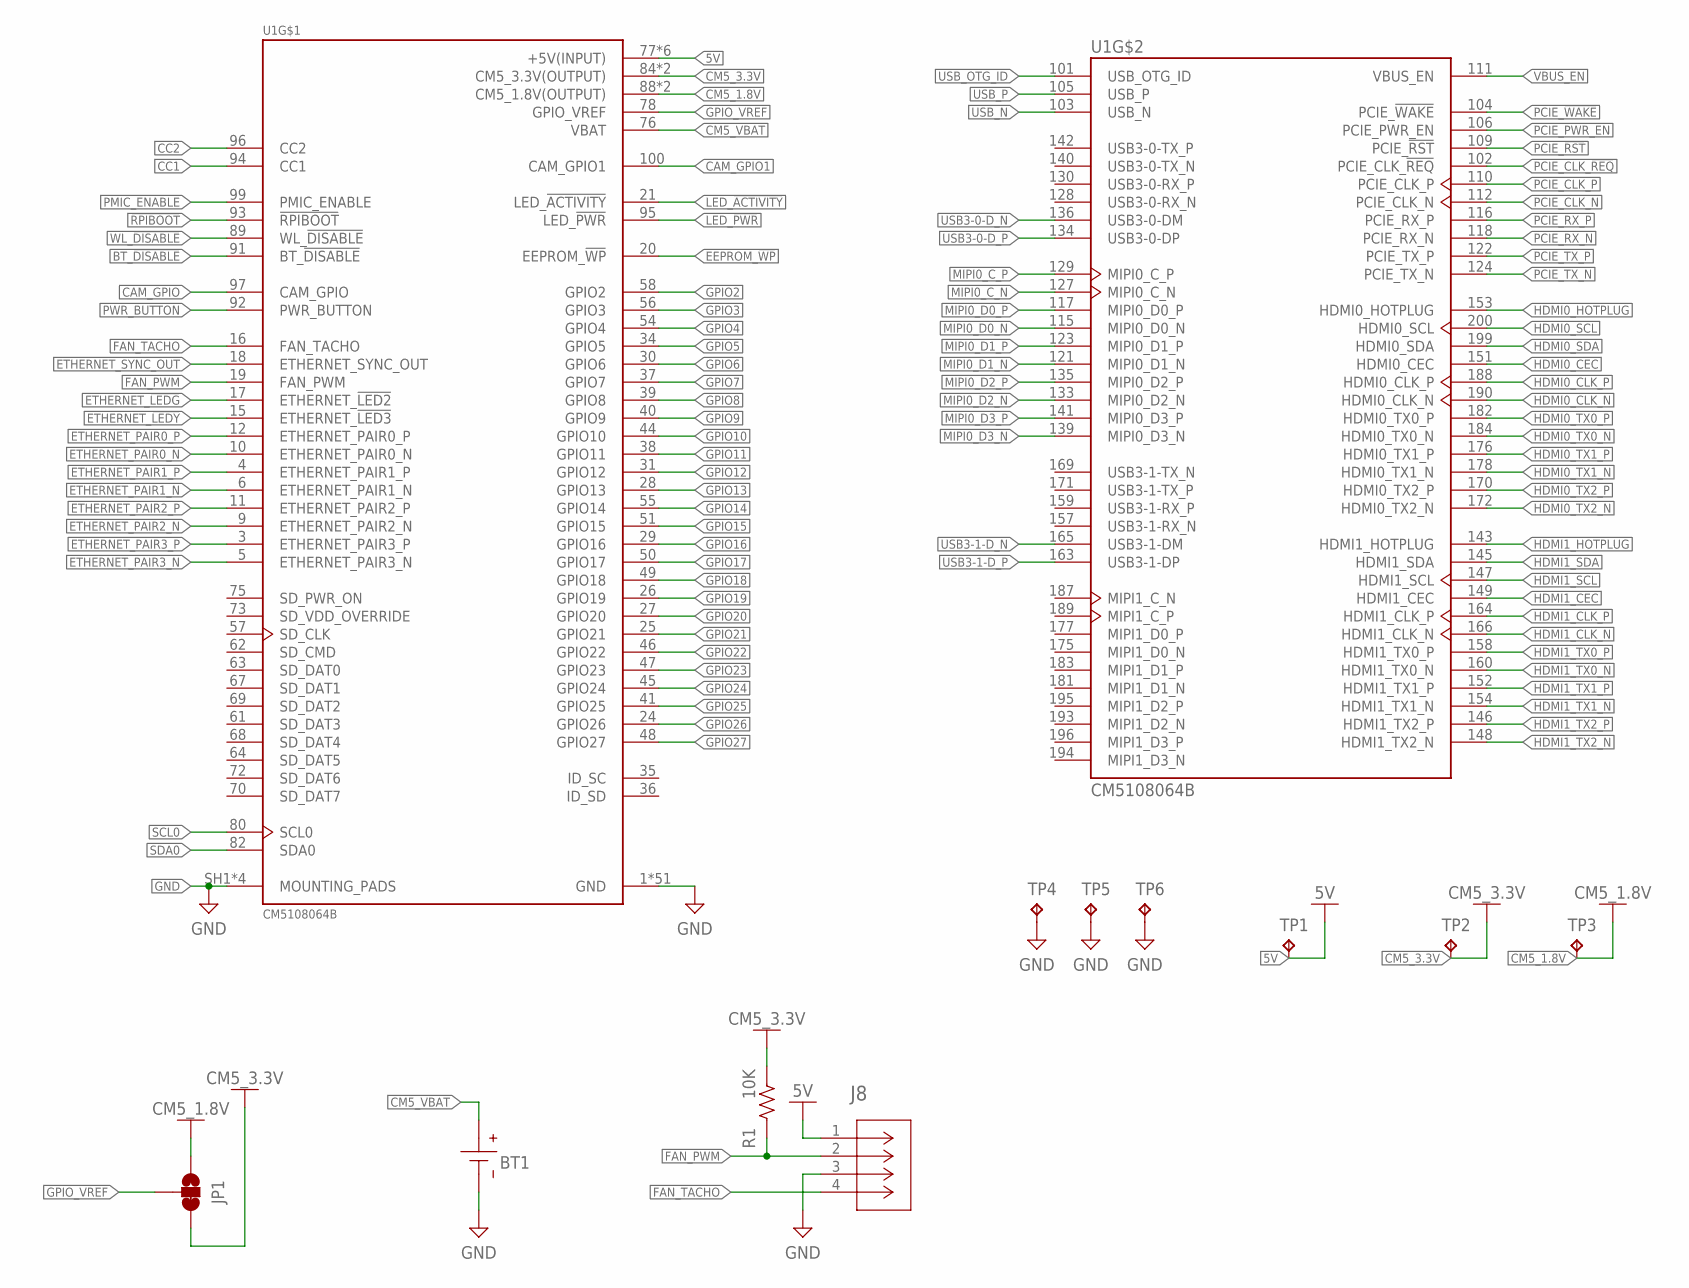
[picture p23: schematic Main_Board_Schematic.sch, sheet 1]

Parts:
BT1: COIN-CELL-SMT-3P-3002-BR2016; BAT_3002
J8: SM04B-SRSS-TBCONN_SM04B-SRSS-TB_JST; CONN_SM04B-SRSS-TB_JST
JP1: JUMPER-SMT_3_1-NC_TRACE_SILK; SMT-JUMPER_3_1-NC_TRACE_SILK
R1: 10K; RESC2012X65
TP1, TP2, TP3, TP4, TP5, TP6: TPB1,27; B1,27
U1: CM5108064B; MODULE_CM5108064B

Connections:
5V: J8.1, TP1.TP, U1.77 (+5V(INPUT)), U1.79 (+5V(INPUT)), U1.81 (+5V(INPUT)), U1.83 (+5V(INPUT)), U1.85 (+5V(INPUT)), U1.87 (+5V(INPUT)); also elsewhere on the board
!RPIBOOT: U1.93 (!RPIBOOT); also elsewhere on the board
BT_!DISABLE: U1.91 (BT_!DISABLE); also elsewhere on the board
CAM_GPIO: U1.97 (CAM_GPIO); also elsewhere on the board
CAM_GPIO1: U1.100 (CAM_GPIO1); also elsewhere on the board
CC1: U1.94 (CC1)
CC2: U1.96 (CC2)
CM5_1.8V: JP1.1, TP3.TP, U1.88 (CM5_1.8V(OUTPUT)), U1.90 (CM5_1.8V(OUTPUT))
CM5_3.3V: JP1.3, R1.2, TP2.TP, U1.84 (CM5_3.3V(OUTPUT)), U1.86 (CM5_3.3V(OUTPUT)); also elsewhere on the board
CM5_VBAT: BT1.P (+), BT1.P1 (+), U1.76 (VBAT)
EEPROM_!WP: U1.20 (EEPROM_!WP); also elsewhere on the board
ETHERNET_!LEDG: U1.17 (ETHERNET_!LED2); also elsewhere on the board
ETHERNET_!LEDY: U1.15 (ETHERNET_!LED3); also elsewhere on the board
ETHERNET_PAIR0_N: U1.10 (ETHERNET_PAIR0_N); also elsewhere on the board
ETHERNET_PAIR0_P: U1.12 (ETHERNET_PAIR0_P); also elsewhere on the board
ETHERNET_PAIR1_N: U1.6 (ETHERNET_PAIR1_N); also elsewhere on the board
ETHERNET_PAIR1_P: U1.4 (ETHERNET_PAIR1_P); also elsewhere on the board
ETHERNET_PAIR2_N: U1.9 (ETHERNET_PAIR2_N); also elsewhere on the board
ETHERNET_PAIR2_P: U1.11 (ETHERNET_PAIR2_P); also elsewhere on the board
ETHERNET_PAIR3_N: U1.5 (ETHERNET_PAIR3_N); also elsewhere on the board
ETHERNET_PAIR3_P: U1.3 (ETHERNET_PAIR3_P); also elsewhere on the board
ETHERNET_SYNC_OUT: U1.18 (ETHERNET_SYNC_OUT)
FAN_PWM: J8.2, R1.1, U1.19 (FAN_PWM)
FAN_TACHO: J8.4, U1.16 (FAN_TACHO)
GND: BT1.N (-), J8.3, TP4.TP, TP5.TP, TP6.TP, U1.1 (GND), U1.2 (GND), U1.7 (GND), U1.8 (GND), U1.13 (GND), U1.14 (GND), U1.22 (GND), U1.23 (GND), U1.32 (GND), U1.33 (GND), U1.42 (GND), U1.43 (GND), U1.52 (GND), U1.53 (GND), U1.59 (GND), U1.60 (GND), U1.65 (GND), U1.66 (GND), U1.71 (GND), U1.74 (GND), U1.98 (GND), U1.107 (GND), U1.108 (GND), U1.113 (GND), U1.114 (GND), U1.119 (GND), U1.120 (GND), U1.125 (GND), U1.126 (GND), U1.131 (GND), U1.132 (GND), U1.137 (GND), U1.138 (GND), U1.144 (GND), U1.150 (GND), U1.155 (GND), U1.156 (GND), U1.161 (GND), U1.162 (GND), U1.167 (GND), U1.168 (GND), U1.173 (GND), U1.174 (GND), U1.179 (GND), U1.180 (GND), U1.185 (GND), U1.186 (GND), U1.191 (GND), U1.192 (GND), U1.197 (GND), U1.198 (GND), U1.SH1 (MOUNTING_PADS), U1.SH2 (MOUNTING_PADS), U1.SH3 (MOUNTING_PADS), U1.SH4 (MOUNTING_PADS); also elsewhere on the board
GPIO2: U1.58 (GPIO2); also elsewhere on the board
GPIO3: U1.56 (GPIO3); also elsewhere on the board
GPIO4: U1.54 (GPIO4); also elsewhere on the board
GPIO5: U1.34 (GPIO5)
GPIO6: U1.30 (GPIO6); also elsewhere on the board
GPIO7: U1.37 (GPIO7); also elsewhere on the board
GPIO8: U1.39 (GPIO8); also elsewhere on the board
GPIO9: U1.40 (GPIO9); also elsewhere on the board
GPIO10: U1.44 (GPIO10); also elsewhere on the board
GPIO11: U1.38 (GPIO11); also elsewhere on the board
GPIO12: U1.31 (GPIO12)
GPIO13: U1.28 (GPIO13)
GPIO14: U1.55 (GPIO14); also elsewhere on the board
GPIO15: U1.51 (GPIO15); also elsewhere on the board
GPIO16: U1.29 (GPIO16); also elsewhere on the board
GPIO17: U1.50 (GPIO17); also elsewhere on the board
GPIO18: U1.49 (GPIO18); also elsewhere on the board
GPIO19: U1.26 (GPIO19); also elsewhere on the board
GPIO20: U1.27 (GPIO20)
GPIO21: U1.25 (GPIO21); also elsewhere on the board
GPIO22: U1.46 (GPIO22); also elsewhere on the board
GPIO23: U1.47 (GPIO23); also elsewhere on the board
GPIO24: U1.45 (GPIO24)
GPIO25: U1.41 (GPIO25)
GPIO26: U1.24 (GPIO26)
GPIO27: U1.48 (GPIO27); also elsewhere on the board
GPIO_VREF: JP1.2, U1.78 (GPIO_VREF)
HDMI0_CEC: U1.151 (HDMI0_CEC); also elsewhere on the board
HDMI0_CLK_N: U1.190 (HDMI0_CLK_N); also elsewhere on the board
HDMI0_CLK_P: U1.188 (HDMI0_CLK_P); also elsewhere on the board
HDMI0_HOTPLUG: U1.153 (HDMI0_HOTPLUG); also elsewhere on the board
HDMI0_SCL: U1.200 (HDMI0_SCL); also elsewhere on the board
HDMI0_SDA: U1.199 (HDMI0_SDA); also elsewhere on the board
HDMI0_TX0_N: U1.184 (HDMI0_TX0_N); also elsewhere on the board
HDMI0_TX0_P: U1.182 (HDMI0_TX0_P); also elsewhere on the board
HDMI0_TX1_N: U1.178 (HDMI0_TX1_N); also elsewhere on the board
HDMI0_TX1_P: U1.176 (HDMI0_TX1_P); also elsewhere on the board
HDMI0_TX2_N: U1.172 (HDMI0_TX2_N); also elsewhere on the board
HDMI0_TX2_P: U1.170 (HDMI0_TX2_P); also elsewhere on the board
HDMI1_CEC: U1.149 (HDMI1_CEC); also elsewhere on the board
HDMI1_CLK_N: U1.166 (HDMI1_CLK_N); also elsewhere on the board
HDMI1_CLK_P: U1.164 (HDMI1_CLK_P); also elsewhere on the board
HDMI1_HOTPLUG: U1.143 (HDMI1_HOTPLUG); also elsewhere on the board
HDMI1_SCL: U1.147 (HDMI1_SCL); also elsewhere on the board
HDMI1_SDA: U1.145 (HDMI1_SDA); also elsewhere on the board
HDMI1_TX0_N: U1.160 (HDMI1_TX0_N); also elsewhere on the board
HDMI1_TX0_P: U1.158 (HDMI1_TX0_P); also elsewhere on the board
HDMI1_TX1_N: U1.154 (HDMI1_TX1_N); also elsewhere on the board
HDMI1_TX1_P: U1.152 (HDMI1_TX1_P); also elsewhere on the board
HDMI1_TX2_N: U1.148 (HDMI1_TX2_N); also elsewhere on the board
HDMI1_TX2_P: U1.146 (HDMI1_TX2_P); also elsewhere on the board
LED_!ACTIVITY: U1.21 (LED_!ACTIVITY); also elsewhere on the board
LED_!PWR: U1.95 (LED_!PWR); also elsewhere on the board
MIPI0_C_N: U1.127 (MIPI0_C_N); also elsewhere on the board
MIPI0_C_P: U1.129 (MIPI0_C_P); also elsewhere on the board
MIPI0_D0_N: U1.115 (MIPI0_D0_N); also elsewhere on the board
MIPI0_D0_P: U1.117 (MIPI0_D0_P); also elsewhere on the board
MIPI0_D1_N: U1.121 (MIPI0_D1_N); also elsewhere on the board
MIPI0_D1_P: U1.123 (MIPI0_D1_P); also elsewhere on the board
MIPI0_D2_N: U1.133 (MIPI0_D2_N); also elsewhere on the board
MIPI0_D2_P: U1.135 (MIPI0_D2_P); also elsewhere on the board
MIPI0_D3_N: U1.139 (MIPI0_D3_N); also elsewhere on the board
MIPI0_D3_P: U1.141 (MIPI0_D3_P); also elsewhere on the board
PCIE_!RST: U1.109 (PCIE_!RST); also elsewhere on the board
PCIE_!WAKE: U1.104 (PCIE_!WAKE); also elsewhere on the board
PCIE_CLK_!REQ: U1.102 (PCIE_CLK_!REQ); also elsewhere on the board
PCIE_CLK_N: U1.112 (PCIE_CLK_N); also elsewhere on the board
PCIE_CLK_P: U1.110 (PCIE_CLK_P); also elsewhere on the board
PCIE_PWR_EN: U1.106 (PCIE_PWR_EN); also elsewhere on the board
PCIE_RX_N: U1.118 (PCIE_RX_N); also elsewhere on the board
PCIE_RX_P: U1.116 (PCIE_RX_P); also elsewhere on the board
PCIE_TX_N: U1.124 (PCIE_TX_N); also elsewhere on the board
PCIE_TX_P: U1.122 (PCIE_TX_P); also elsewhere on the board
PMIC_ENABLE: U1.99 (PMIC_ENABLE); also elsewhere on the board
PWR_BUTTON: U1.92 (PWR_BUTTON); also elsewhere on the board
SCL0: U1.80 (SCL0); also elsewhere on the board
SDA0: U1.82 (SDA0); also elsewhere on the board
USB3-0-D_N: U1.136 (USB3-0-DM)
USB3-0-D_P: U1.134 (USB3-0-DP)
USB3-1-D_N: U1.165 (USB3-1-DM); also elsewhere on the board
USB3-1-D_P: U1.163 (USB3-1-DP); also elsewhere on the board
USB_N: U1.103 (USB_N); also elsewhere on the board
USB_OTG_ID: U1.101 (USB_OTG_ID); also elsewhere on the board
USB_P: U1.105 (USB_P); also elsewhere on the board
VBUS_EN: U1.111 (VBUS_EN); also elsewhere on the board
WL_!DISABLE: U1.89 (WL_!DISABLE); also elsewhere on the board

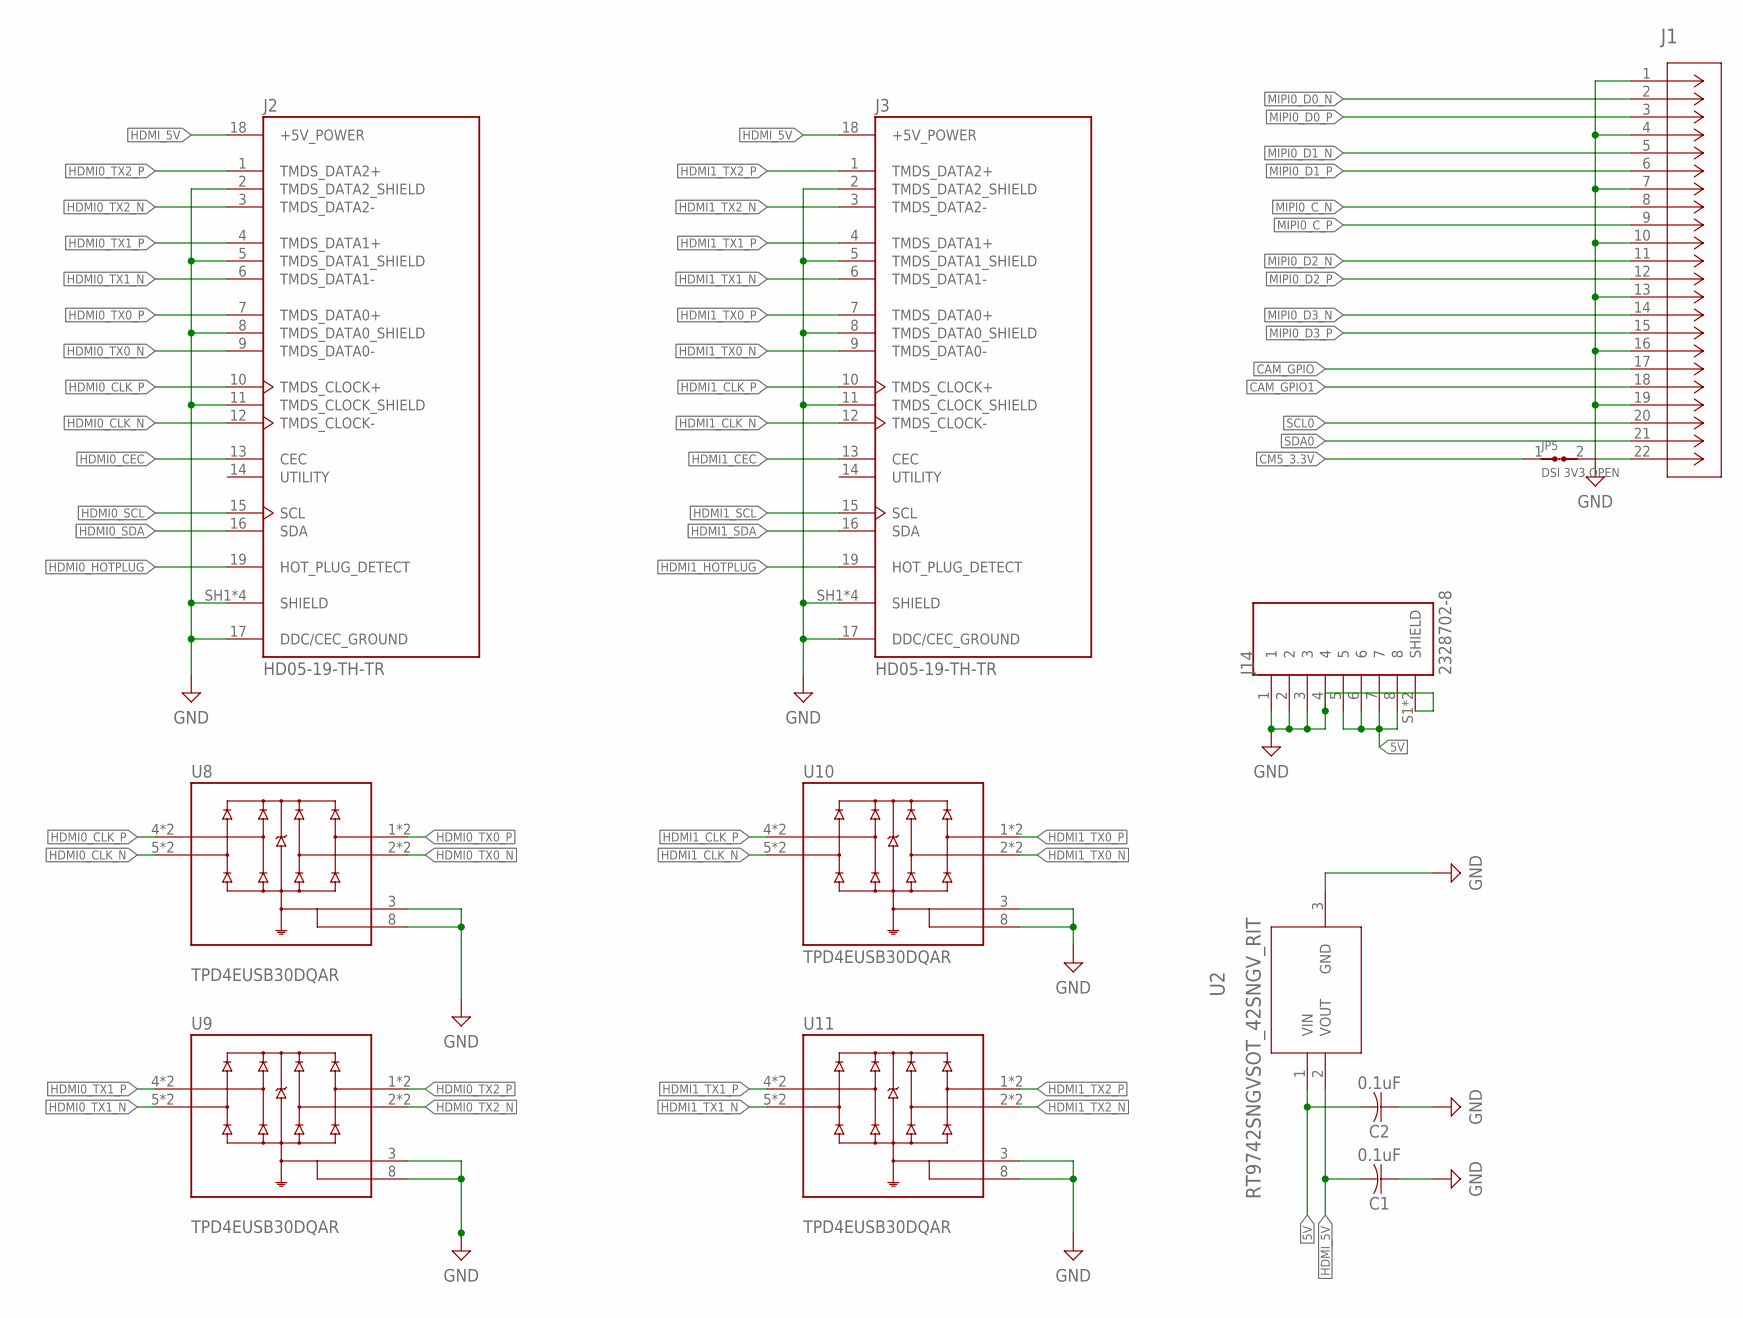
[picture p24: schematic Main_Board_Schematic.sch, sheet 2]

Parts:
C1, C2: 0.1uF; CAPC2012X110
J1: FH12-22S-0.5SH(55)CONN_FH12-22S-0.5SH(55)_HIR; CONN_FH12-22S-0.5SH(55)_HIR
J2, J3: HD05-19-TH-TR; SAMESKY_HD05-19-TH-TR
J14: 2328702-8; TE_2328702-8
JP5: DSI 3V3 OPEN; SJ_2_NO
U2: RT9742SNGVSOT_42SNGV_RIT; SOT_42SNGV_RIT
U8, U9, U10, U11: TPD4EUSB30DQAR; IC_TPD4EUSB30DQAR

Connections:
5V: C2.2, J14.5, J14.6, J14.7, J14.8, U2.1 (VIN); also elsewhere on the board
CAM_GPIO: J1.17; also elsewhere on the board
CAM_GPIO1: J1.18; also elsewhere on the board
CM5_3.3V: JP5.1; also elsewhere on the board
DSI_3V3: J1.22, JP5.2
GND: C1.1, C2.1, J1.1, J1.4, J1.7, J1.10, J1.13, J1.16, J1.19, J2.2 (TMDS_DATA2_SHIELD), J2.5 (TMDS_DATA1_SHIELD), J2.8 (TMDS_DATA0_SHIELD), J2.11 (TMDS_CLOCK_SHIELD), J2.17 (DDC/CEC_GROUND), J2.SH1 (SHIELD), J2.SH2 (SHIELD), J2.SH3 (SHIELD), J2.SH4 (SHIELD), J3.2 (TMDS_DATA2_SHIELD), J3.5 (TMDS_DATA1_SHIELD), J3.8 (TMDS_DATA0_SHIELD), J3.11 (TMDS_CLOCK_SHIELD), J3.17 (DDC/CEC_GROUND), J3.SH1 (SHIELD), J3.SH2 (SHIELD), J3.SH3 (SHIELD), J3.SH4 (SHIELD), J14.1, J14.2, J14.3, J14.4, J14.S1 (SHIELD), J14.S2 (SHIELD), U2.3 (GND), U8.3 (GND_3), U8.8 (GND_8), U9.3 (GND_3), U9.8 (GND_8), U10.3 (GND_3), U10.8 (GND_8), U11.3 (GND_3), U11.8 (GND_8); also elsewhere on the board
HDMI0_CEC: J2.13 (CEC); also elsewhere on the board
HDMI0_CLK_N: J2.12 (TMDS_CLOCK-), U8.5 (D2-), U8.6 (D2-); also elsewhere on the board
HDMI0_CLK_P: J2.10 (TMDS_CLOCK+), U8.4 (D2+), U8.7 (D2+); also elsewhere on the board
HDMI0_HOTPLUG: J2.19 (HOT_PLUG_DETECT); also elsewhere on the board
HDMI0_SCL: J2.15 (SCL); also elsewhere on the board
HDMI0_SDA: J2.16 (SDA); also elsewhere on the board
HDMI0_TX0_N: J2.9 (TMDS_DATA0-), U8.2 (D1-), U8.9 (D1-); also elsewhere on the board
HDMI0_TX0_P: J2.7 (TMDS_DATA0+), U8.1 (D1+), U8.10 (D1+); also elsewhere on the board
HDMI0_TX1_N: J2.6 (TMDS_DATA1-), U9.5 (D2-), U9.6 (D2-); also elsewhere on the board
HDMI0_TX1_P: J2.4 (TMDS_DATA1+), U9.4 (D2+), U9.7 (D2+); also elsewhere on the board
HDMI0_TX2_N: J2.3 (TMDS_DATA2-), U9.2 (D1-), U9.9 (D1-); also elsewhere on the board
HDMI0_TX2_P: J2.1 (TMDS_DATA2+), U9.1 (D1+), U9.10 (D1+); also elsewhere on the board
HDMI1_CEC: J3.13 (CEC); also elsewhere on the board
HDMI1_CLK_N: J3.12 (TMDS_CLOCK-), U10.5 (D2-), U10.6 (D2-); also elsewhere on the board
HDMI1_CLK_P: J3.10 (TMDS_CLOCK+), U10.4 (D2+), U10.7 (D2+); also elsewhere on the board
HDMI1_HOTPLUG: J3.19 (HOT_PLUG_DETECT); also elsewhere on the board
HDMI1_SCL: J3.15 (SCL); also elsewhere on the board
HDMI1_SDA: J3.16 (SDA); also elsewhere on the board
HDMI1_TX0_N: J3.9 (TMDS_DATA0-), U10.2 (D1-), U10.9 (D1-); also elsewhere on the board
HDMI1_TX0_P: J3.7 (TMDS_DATA0+), U10.1 (D1+), U10.10 (D1+); also elsewhere on the board
HDMI1_TX1_N: J3.6 (TMDS_DATA1-), U11.5 (D2-), U11.6 (D2-); also elsewhere on the board
HDMI1_TX1_P: J3.4 (TMDS_DATA1+), U11.4 (D2+), U11.7 (D2+); also elsewhere on the board
HDMI1_TX2_N: J3.3 (TMDS_DATA2-), U11.2 (D1-), U11.9 (D1-); also elsewhere on the board
HDMI1_TX2_P: J3.1 (TMDS_DATA2+), U11.1 (D1+), U11.10 (D1+); also elsewhere on the board
HDMI_5V: C1.2, J2.18 (+5V_POWER), J3.18 (+5V_POWER), U2.2 (VOUT)
MIPI0_C_N: J1.8; also elsewhere on the board
MIPI0_C_P: J1.9; also elsewhere on the board
MIPI0_D0_N: J1.2; also elsewhere on the board
MIPI0_D0_P: J1.3; also elsewhere on the board
MIPI0_D1_N: J1.5; also elsewhere on the board
MIPI0_D1_P: J1.6; also elsewhere on the board
MIPI0_D2_N: J1.11; also elsewhere on the board
MIPI0_D2_P: J1.12; also elsewhere on the board
MIPI0_D3_N: J1.14; also elsewhere on the board
MIPI0_D3_P: J1.15; also elsewhere on the board
SCL0: J1.20; also elsewhere on the board
SDA0: J1.21; also elsewhere on the board

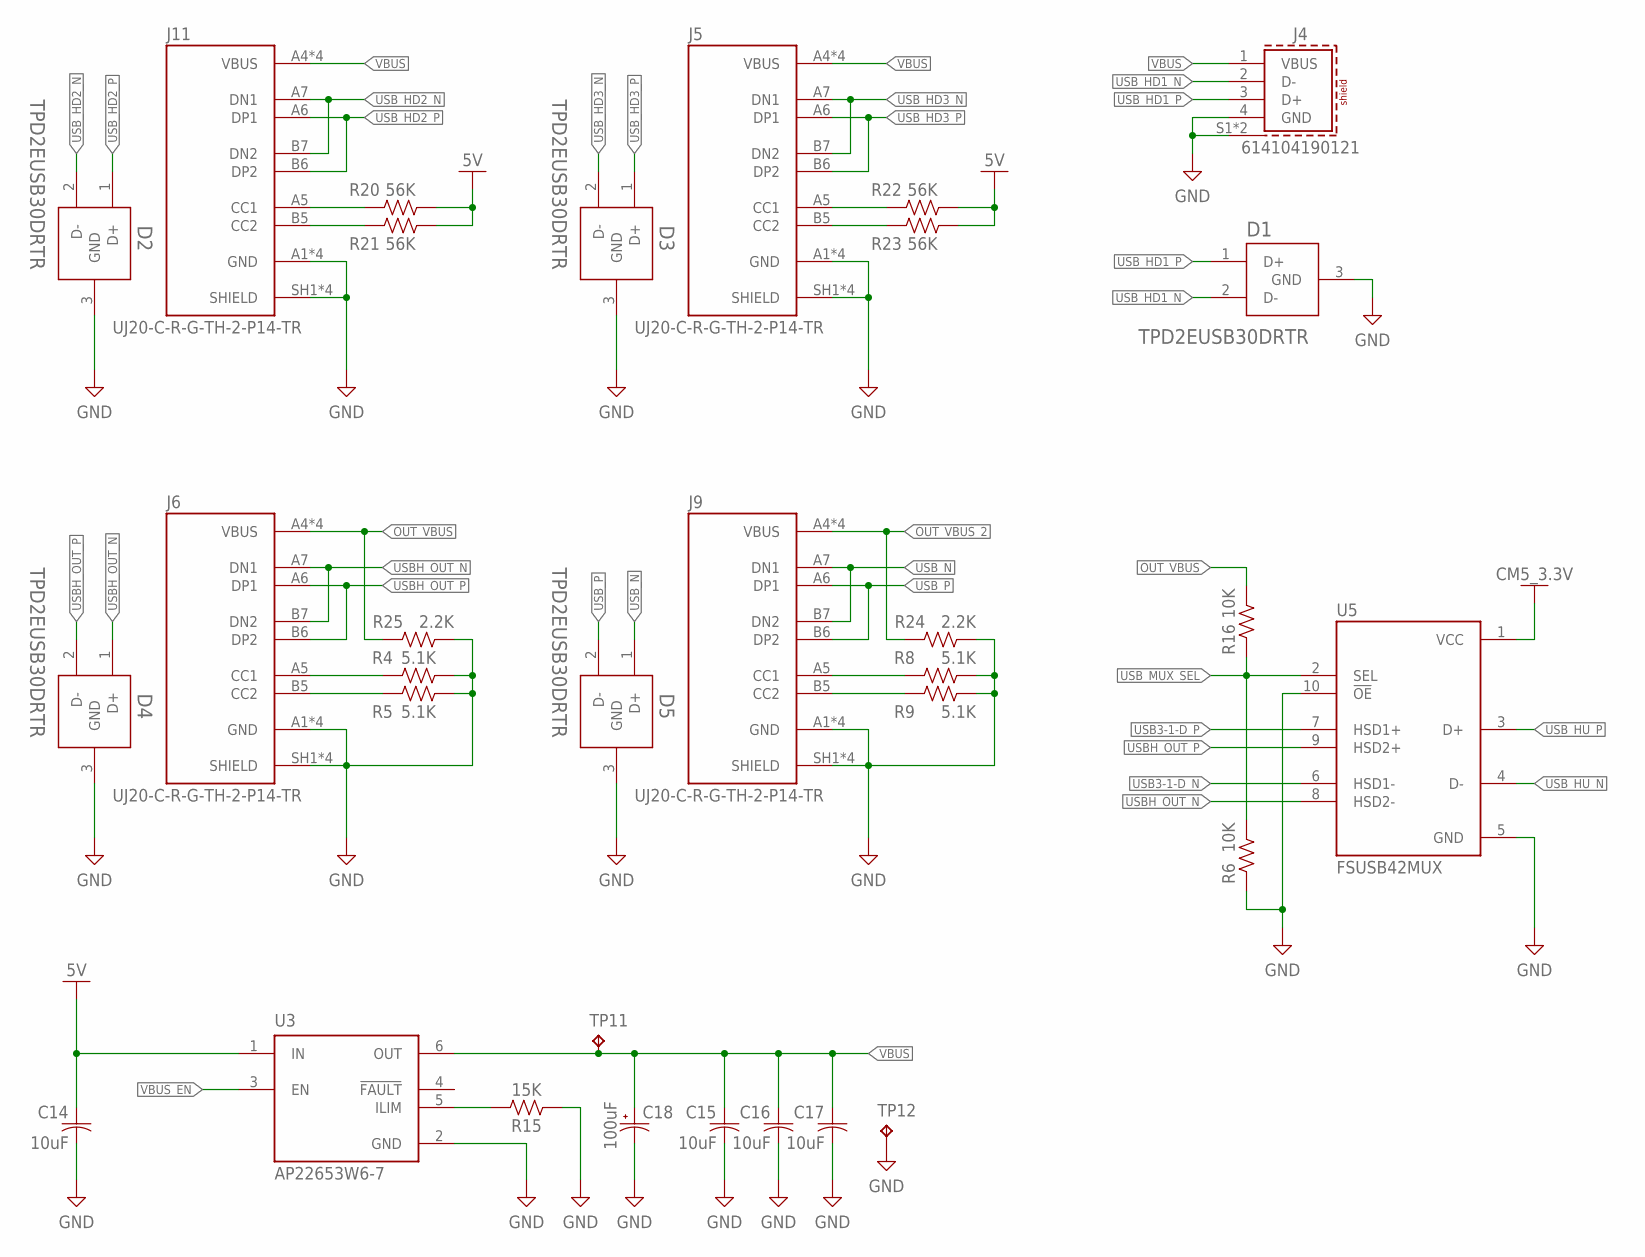
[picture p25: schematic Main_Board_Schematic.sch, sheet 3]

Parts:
C14, C15, C16, C17: 10uF; CAPC3216X135
C18: 100uF; CAPMP3528X210N
D1, D2, D3, D4, D5: TPD2EUSB30DRTR; SOTFL35P100X50-3N
J4: 614104190121
J5, J6, J9, J11: UJ20-C-R-G-TH-2-P14-TR; SAMESKY_UJ20-C-R-G-TH-2-P14-TR
R4, R5, R8, R9: 5.1K; RESC2012X65
R6, R16: 10K; RESC2012X65
R15: 15K; RESC2012X65
R20, R21, R22, R23: 56K; RESC2012X65
R24, R25: 2.2K; RESC2012X65
TP11, TP12: TPB1,27; B1,27
U3: AP22653W6-7; SOT95P280X145-6N
U5: FSUSB42MUX; SOP50P490X110-10N

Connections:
5V: C14.1, R20.1, R21.1, R22.1, R23.1, U3.1 (IN); also elsewhere on the board
CM5_3.3V: U5.1 (VCC); also elsewhere on the board
GND: C14.2, C15.2, C16.2, C17.2, C18.2 (-), D1.3 (GND), D2.3 (GND), D3.3 (GND), D4.3 (GND), D5.3 (GND), J4.4 (GND), J4.S1 (SHIELD), J4.S2 (SHIELD), J5.A1 (GND), J5.A12 (GND), J5.B1 (GND), J5.B12 (GND), J5.SH1 (SHIELD), J5.SH2 (SHIELD), J5.SH3 (SHIELD), J5.SH4 (SHIELD), J6.A1 (GND), J6.A12 (GND), J6.B1 (GND), J6.B12 (GND), J6.SH1 (SHIELD), J6.SH2 (SHIELD), J6.SH3 (SHIELD), J6.SH4 (SHIELD), J9.A1 (GND), J9.A12 (GND), J9.B1 (GND), J9.B12 (GND), J9.SH1 (SHIELD), J9.SH2 (SHIELD), J9.SH3 (SHIELD), J9.SH4 (SHIELD), J11.A1 (GND), J11.A12 (GND), J11.B1 (GND), J11.B12 (GND), J11.SH1 (SHIELD), J11.SH2 (SHIELD), J11.SH3 (SHIELD), J11.SH4 (SHIELD), R4.1, R5.1, R6.1, R8.1, R9.1, R15.1, R24.1, R25.1, TP12.TP, U3.2 (GND), U5.5 (GND), U5.10 (!OE); also elsewhere on the board
unnamed: J11.A5 (CC1), R20.2
unnamed: J5.A5 (CC1), R22.2
unnamed: J9.A5 (CC1), R8.2
unnamed: J9.B5 (CC2), R9.2
unnamed: J6.A5 (CC1), R4.2
unnamed: J6.B5 (CC2), R5.2
unnamed: R15.2, U3.5 (ILIM)
unnamed: J5.B5 (CC2), R23.2
unnamed: J11.B5 (CC2), R21.2
OUT_VBUS: J6.A4 (VBUS), J6.A9 (VBUS), J6.B4 (VBUS), J6.B9 (VBUS), R16.2, R25.2
OUT_VBUS_2: J9.A4 (VBUS), J9.A9 (VBUS), J9.B4 (VBUS), J9.B9 (VBUS), R24.2
USB3-1-D_N: U5.6 (HSD1-); also elsewhere on the board
USB3-1-D_P: U5.7 (HSD1+); also elsewhere on the board
USBH_OUT_N: D4.1 (D+), J6.A7 (DN1), J6.B7 (DN2), U5.8 (HSD2-)
USBH_OUT_P: D4.2 (D-), J6.A6 (DP1), J6.B6 (DP2), U5.9 (HSD2+)
USB_HD1_N: D1.2 (D-), J4.2 (D-); also elsewhere on the board
USB_HD1_P: D1.1 (D+), J4.3 (D+); also elsewhere on the board
USB_HD2_N: D2.2 (D-), J11.A7 (DN1), J11.B7 (DN2); also elsewhere on the board
USB_HD2_P: D2.1 (D+), J11.A6 (DP1), J11.B6 (DP2); also elsewhere on the board
USB_HD3_N: D3.2 (D-), J5.A7 (DN1), J5.B7 (DN2); also elsewhere on the board
USB_HD3_P: D3.1 (D+), J5.A6 (DP1), J5.B6 (DP2); also elsewhere on the board
USB_HU_N: U5.4 (D-); also elsewhere on the board
USB_HU_P: U5.3 (D+); also elsewhere on the board
USB_MUX_SEL: R6.2, R16.1, U5.2 (SEL)
USB_N: D5.1 (D+), J9.A7 (DN1), J9.B7 (DN2); also elsewhere on the board
USB_P: D5.2 (D-), J9.A6 (DP1), J9.B6 (DP2); also elsewhere on the board
VBUS: C15.1, C16.1, C17.1, C18.1 (+), J4.1 (VBUS), J5.A4 (VBUS), J5.A9 (VBUS), J5.B4 (VBUS), J5.B9 (VBUS), J11.A4 (VBUS), J11.A9 (VBUS), J11.B4 (VBUS), J11.B9 (VBUS), TP11.TP, U3.6 (OUT)
VBUS_EN: U3.3 (EN); also elsewhere on the board

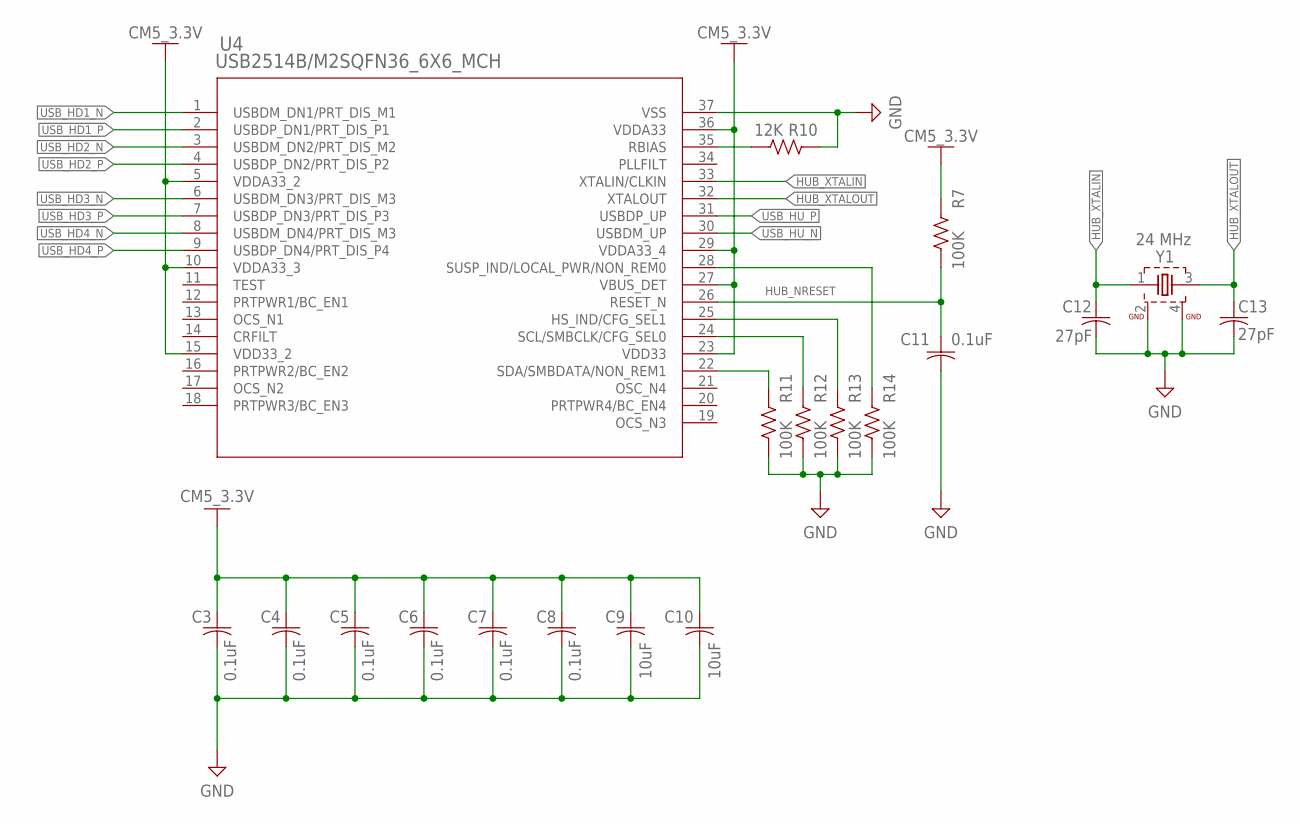
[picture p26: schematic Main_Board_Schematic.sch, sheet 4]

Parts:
C3, C4, C5, C6, C7, C8, C11: 0.1uF; CAPC2012X110
C9, C10: 10uF; CAPC3216X135
C12, C13: 27pF; CAPC2012X110
R7, R11, R12, R13, R14: 100K; RESC2012X65
R10: 12K; RESC2012X65
U4: USB2514B/M2SQFN36_6X6_MCH; SQFN36_6X6_MCH
Y1: 24 MHz; WE-XTAL_CFPX-180

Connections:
CM5_3.3V: C3.1, C4.1, C5.1, C6.1, C7.1, C8.1, C9.1, C10.1, R7.1, U4.5 (VDDA33_2), U4.10 (VDDA33_3), U4.15 (VDD33_2), U4.23 (VDD33), U4.27 (VBUS_DET), U4.29 (VDDA33_4), U4.36 (VDDA33); also elsewhere on the board
GND: C3.2, C4.2, C5.2, C6.2, C7.2, C8.2, C9.2, C10.2, C11.2, C12.2, C13.2, R10.1, R11.2, R12.2, R13.2, R14.2, U4.37 (VSS), Y1.2 (GND), Y1.4 (GND1); also elsewhere on the board
HUB_NRESET: C11.1, R7.2, U4.26 (RESET_N)
HUB_XTALIN: C12.1, U4.33 (XTALIN/CLKIN), Y1.1
HUB_XTALOUT: C13.1, U4.32 (XTALOUT), Y1.3 (2)
unnamed: R10.2, U4.35 (RBIAS)
unnamed: R11.1, U4.22 (SDA/SMBDATA/NON_REM1)
unnamed: R12.1, U4.24 (SCL/SMBCLK/CFG_SEL0)
unnamed: R13.1, U4.25 (HS_IND/CFG_SEL1)
unnamed: R14.1, U4.28 (SUSP_IND/LOCAL_PWR/NON_REM0)
USB_HD1_N: U4.1 (USBDM_DN1/PRT_DIS_M1); also elsewhere on the board
USB_HD1_P: U4.2 (USBDP_DN1/PRT_DIS_P1); also elsewhere on the board
USB_HD2_N: U4.3 (USBDM_DN2/PRT_DIS_M2); also elsewhere on the board
USB_HD2_P: U4.4 (USBDP_DN2/PRT_DIS_P2); also elsewhere on the board
USB_HD3_N: U4.6 (USBDM_DN3/PRT_DIS_M3); also elsewhere on the board
USB_HD3_P: U4.7 (USBDP_DN3/PRT_DIS_P3); also elsewhere on the board
USB_HD4_N: U4.8 (USBDM_DN4/PRT_DIS_M3); also elsewhere on the board
USB_HD4_P: U4.9 (USBDP_DN4/PRT_DIS_P4); also elsewhere on the board
USB_HU_N: U4.30 (USBDM_UP); also elsewhere on the board
USB_HU_P: U4.31 (USBDP_UP); also elsewhere on the board

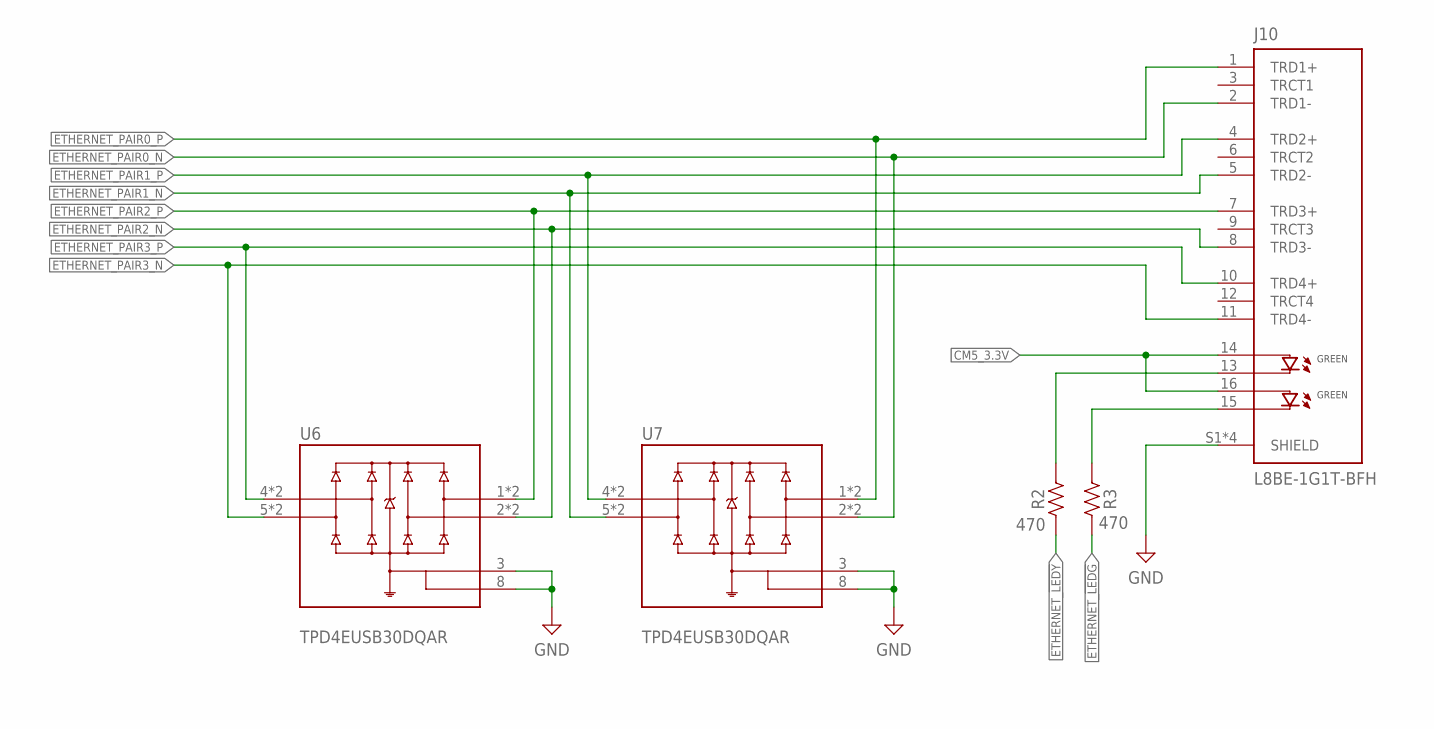
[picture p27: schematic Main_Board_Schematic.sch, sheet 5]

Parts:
J10: L8BE-1G1T-BFH; BEL_L8BE-1G1T-BFH
R2, R3: 470; RESC2012X65
U6, U7: TPD4EUSB30DQAR; IC_TPD4EUSB30DQAR

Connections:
CM5_3.3V: J10.14 (GA_1), J10.16 (GA_2); also elsewhere on the board
ETHERNET_!LEDG: R3.1; also elsewhere on the board
ETHERNET_!LEDY: R2.1; also elsewhere on the board
ETHERNET_PAIR0_N: J10.2 (TRD1-), U7.2 (D1-), U7.9 (D1-); also elsewhere on the board
ETHERNET_PAIR0_P: J10.1 (TRD1+), U7.1 (D1+), U7.10 (D1+); also elsewhere on the board
ETHERNET_PAIR1_N: J10.5 (TRD2-), U7.5 (D2-), U7.6 (D2-); also elsewhere on the board
ETHERNET_PAIR1_P: J10.4 (TRD2+), U7.4 (D2+), U7.7 (D2+); also elsewhere on the board
ETHERNET_PAIR2_N: J10.8 (TRD3-), U6.2 (D1-), U6.9 (D1-); also elsewhere on the board
ETHERNET_PAIR2_P: J10.7 (TRD3+), U6.1 (D1+), U6.10 (D1+); also elsewhere on the board
ETHERNET_PAIR3_N: J10.11 (TRD4-), U6.5 (D2-), U6.6 (D2-); also elsewhere on the board
ETHERNET_PAIR3_P: J10.10 (TRD4+), U6.4 (D2+), U6.7 (D2+); also elsewhere on the board
GND: J10.S1 (SHIELD), J10.S2 (SHIELD), J10.S3 (SHIELD), J10.S4 (SHIELD), U6.3 (GND_3), U6.8 (GND_8), U7.3 (GND_3), U7.8 (GND_8); also elsewhere on the board
unnamed: J10.15 (GK_2), R3.2
unnamed: J10.13 (GK_1), R2.2

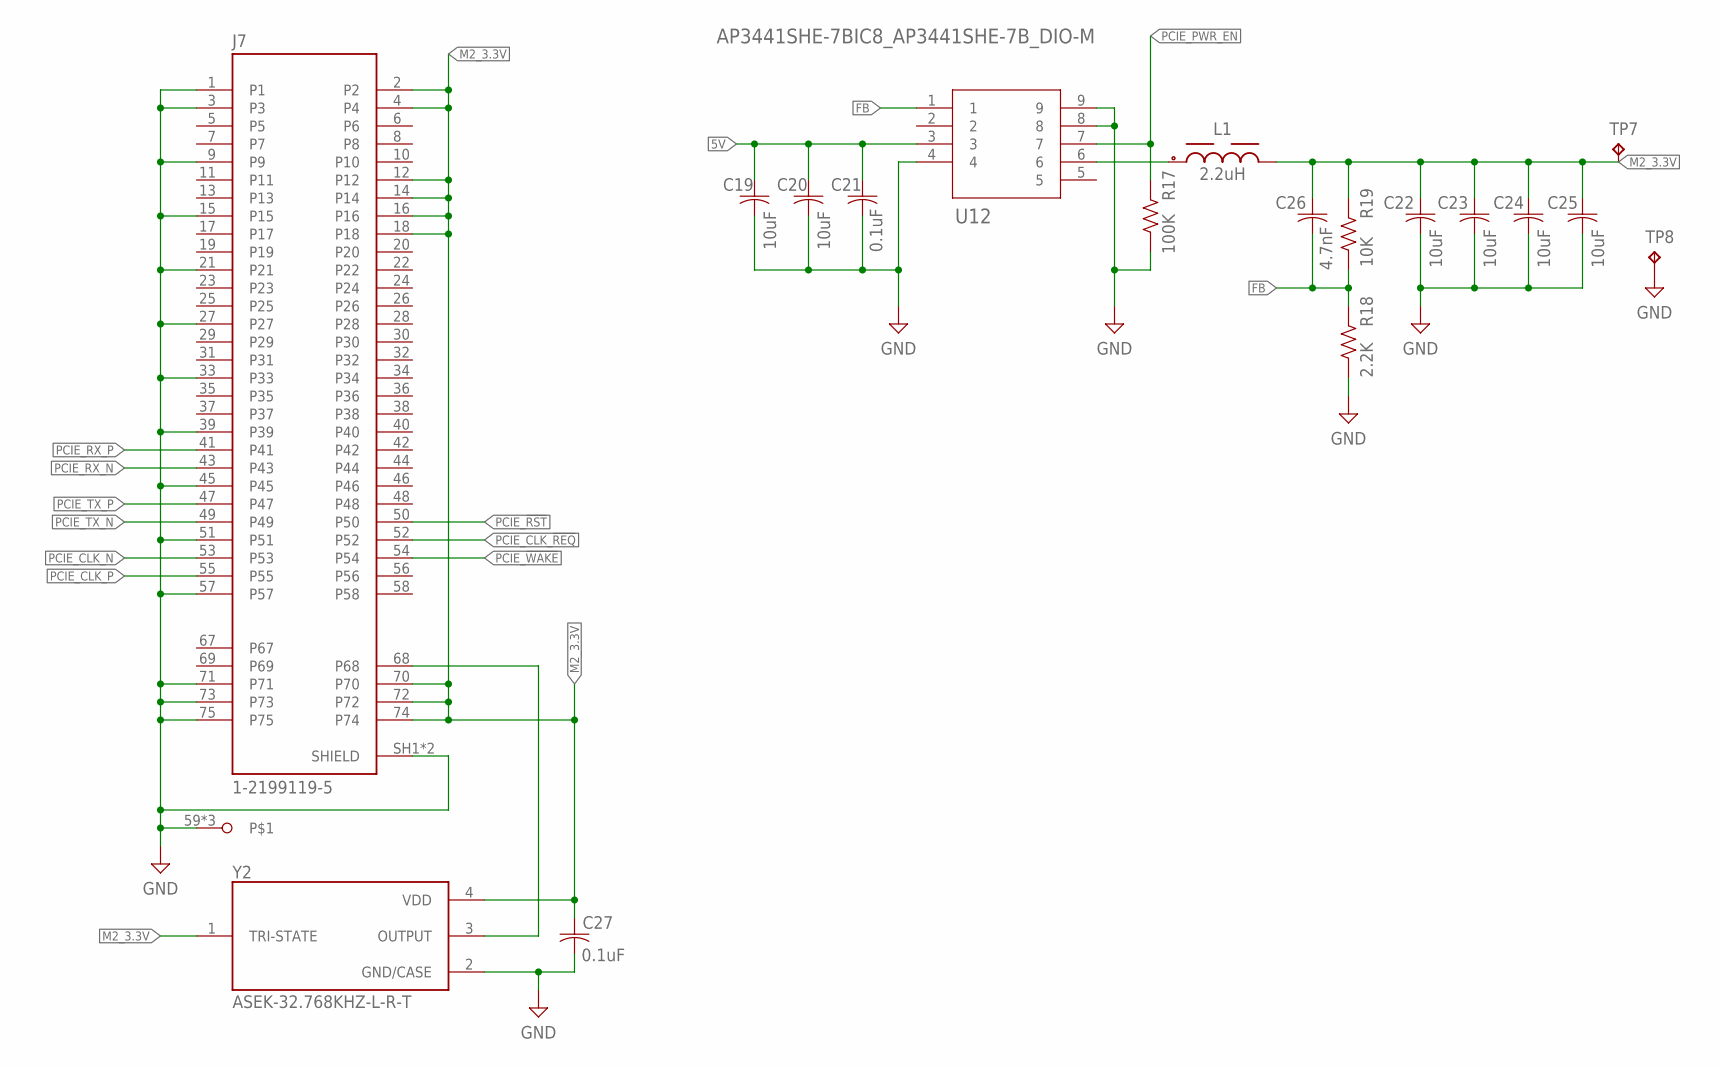
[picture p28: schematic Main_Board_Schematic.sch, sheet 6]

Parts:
C19, C20, C22, C23, C24, C25: 10uF; CAPC3216X135
C21, C27: 0.1uF; CAPC2012X110
C26: 4.7nF; CAPC2012X110
J7: 1-2199119-5; TE_1-2199119-5
L1: 2.2uH; WE-XHMI_5030
R17: 100K; RESC2012X65
R18: 2.2K; RESC2012X65
R19: 10K; RESC2012X65
TP7, TP8: TPB1,27; B1,27
U12: AP3441SHE-7BIC8_AP3441SHE-7B_DIO-M; IC8_AP3441SHE-7B_DIO-M
Y2: ASEK-32.768KHZ-L-R-T; XTAL_ASEK-32.768KHZ-L-R-T

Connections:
5V: C19.1, C20.1, C21.1, U12.3; also elsewhere on the board
FB: C26.2, R18.1, R19.2, U12.1
GND: C19.2, C20.2, C21.2, C22.2, C23.2, C24.2, C25.2, C27.2, J7.1, J7.3, J7.9, J7.15, J7.21, J7.27, J7.33, J7.39, J7.45, J7.51, J7.57, J7.59, J7.60, J7.61, J7.71, J7.73, J7.75, J7.SH1 (SHIELD), J7.SH2 (SHIELD), R17.2, R18.2, TP8.TP, U12.4, U12.8, U12.9, Y2.2 (GND/CASE); also elsewhere on the board
M2_3.3V: C22.1, C23.1, C24.1, C25.1, C26.1, C27.1, J7.2, J7.4, J7.12, J7.14, J7.16, J7.18, J7.70, J7.72, J7.74, L1.2, R19.1, TP7.TP, Y2.1 (TRI-STATE), Y2.4 (VDD)
unnamed: L1.1, U12.6
unnamed: J7.68, Y2.3 (OUTPUT)
PCIE_!RST: J7.50; also elsewhere on the board
PCIE_!WAKE: J7.54; also elsewhere on the board
PCIE_CLK_!REQ: J7.52; also elsewhere on the board
PCIE_CLK_N: J7.53; also elsewhere on the board
PCIE_CLK_P: J7.55; also elsewhere on the board
PCIE_PWR_EN: R17.1, U12.7; also elsewhere on the board
PCIE_RX_N: J7.43; also elsewhere on the board
PCIE_RX_P: J7.41; also elsewhere on the board
PCIE_TX_N: J7.49; also elsewhere on the board
PCIE_TX_P: J7.47; also elsewhere on the board

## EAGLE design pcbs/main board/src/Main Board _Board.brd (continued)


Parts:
J12, J13: S2B-XH-A
J16, J21: M55-7011242R; HARWIN_M55-7011242R
J18, J19: 61201621721
R33, R34: 10K; RESC2012X65
TP9, TP10, TP13, TP14: TPB1,27; B1,27
TP15, TP16: TPPAD1-13; P1-13
U$1: X1203

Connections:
5V: J12.2, J13.2, J18.1, J19.1, J21.A3, J21.A4, U$1.5V$1 (5V), U$1.5V$2 (5V); also elsewhere on the board
!RPIBOOT: J21.B3; also elsewhere on the board
BT_!DISABLE: J21.B2; also elsewhere on the board
CM5_3.3V: R33.2, R34.2, TP13.TP, U$1.3V3_DET; also elsewhere on the board
EEPROM_!WP: J21.B6; also elsewhere on the board
GND: J12.1, J13.1, J16.A1, J16.A4, J16.B4, J18.2, J19.2, J21.A1, J21.A2, TP14.TP, TP16.TP, U$1.GND$1 (GND), U$1.GND$2 (GND), U$1.GND$3 (GND), U$1.GND$4 (GND), U$1.GND$5 (GND), U$1.GND$6 (GND), U$1.GND$7 (GND); also elsewhere on the board
GPIO2: J18.15, J19.15, J21.A5, R33.1, TP9.TP, U$1.SDA; also elsewhere on the board
GPIO3: J18.16, J19.16, J21.A6, R34.1, TP10.TP, U$1.SCL; also elsewhere on the board
GPIO4: J18.13, J19.13; also elsewhere on the board
GPIO6: U$1.AC_DET; also elsewhere on the board
GPIO7: J18.4, J19.4; also elsewhere on the board
GPIO8: J18.3, J19.3; also elsewhere on the board
GPIO9: J18.5, J19.5; also elsewhere on the board
GPIO10: J18.8, J19.8; also elsewhere on the board
GPIO11: J18.6, J19.6; also elsewhere on the board
GPIO14: J18.14, J19.14; also elsewhere on the board
GPIO15: J18.11, J19.11; also elsewhere on the board
GPIO16: U$1.CHRG_CTL; also elsewhere on the board
GPIO17: J18.12, J19.12; also elsewhere on the board
GPIO22: J18.7, J19.7; also elsewhere on the board
GPIO23: J18.10, J19.10; also elsewhere on the board
GPIO27: J18.9, J19.9; also elsewhere on the board
LED_!ACTIVITY: J16.B1; also elsewhere on the board
LED_!PWR: J16.B2; also elsewhere on the board
PMIC_ENABLE: J21.B4; also elsewhere on the board
PWR_BUTTON: J16.B3, TP15.TP, U$1.PWR_SW; also elsewhere on the board
SPK_L_N: J16.A2; also elsewhere on the board
SPK_L_P: J16.A3; also elsewhere on the board
SPK_R_N: J16.A5; also elsewhere on the board
SPK_R_P: J16.A6; also elsewhere on the board
USB_HD4_N: J16.B5; also elsewhere on the board
USB_HD4_P: J16.B6; also elsewhere on the board
USB_OTG_ID: J21.B5; also elsewhere on the board
WL_!DISABLE: J21.B1; also elsewhere on the board


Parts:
C28, C30, C32, C34, C45, C51: 0.1uF; CAPC2012X110
C29, C31, C33, C35, C52: 10uF; CAPC3216X135
C36, C37, C42, C43: 2.2uF; CAPC2012X110
C38, C39: 2.2nF; CAPC2012X110
C40, C41, C44, C46, C47, C48, C49, C50: 1uF; CAPC2012X110
FB1: FBCHIP-0805(2012-METRIC); BEADC2012X105N
IC1: TPA6132A2; QFN16
J17: SJ-3579AN; CUI_SJ-3579AN
JP2, JP3, JP4: JUMPER-SMT_3_1-NC_TRACE_SILK; SMT-JUMPER_3_1-NC_TRACE_SILK
R26, R27: 470; RESC2012X65
R28: 10k; RESC2012X65
R29, R30: 0; RESC2012X65
R31, R32: 10K; RESC2012X65
U13: PCM5100APWRPW0020A; PW0020A
U14: MAX98306ETD+T; SON40P300X300X80-15N

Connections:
5V: C51.1, C52.1, R29.2, R31.2, U14.11 (PVDD), U14.12 (PVDD); also elsewhere on the board
!SPK_SHDN: J17.8, R31.1, U14.2 (!SHDN)
AUDIO_L: C38.1, C41.1, C47.1, R26.1
AUDIO_R: C39.1, C40.1, C48.1, R27.1
AVDD: C32.1, C33.1, C34.1, C35.1, FB1.1, U13.1 (CPVDD), U13.8 (AVDD)
CM5_3.3V: C30.1, C31.1, C45.1, C46.1, FB1.2, IC1.14 (VDD), JP2.3, JP3.1, R28.2, R32.2, U13.20 (DVDD); also elsewhere on the board
GND: C28.2, C29.2, C30.2, C31.2, C32.2, C33.2, C34.2, C35.2, C37.2, C38.2, C39.2, C42.1, C43.2, C45.2, C46.2, C49.1, C50.1, C51.2, C52.2, IC1.2 (INL+), IC1.3 (INR+), IC1.10 (PGND), IC1.15 (SGND), J17.1, J17.4, J17.9, JP2.1, JP3.3, R30.2, U13.3 (CPGND), U13.9 (AGND), U13.10 (DEMP), U13.11 (FLT), U13.12 (SCK), U13.16 (FMT), U13.19 (DGND), U14.1 (PGND), U14.8 (PGND), U14.15 (EP); also elsewhere on the board
GPIO18: U13.13 (BCK); also elsewhere on the board
GPIO19: U13.15 (LRCK); also elsewhere on the board
GPIO21: U13.14 (DIN); also elsewhere on the board
HP_AUDIO_L: IC1.16 (OUTL), J17.2
HP_AUDIO_R: IC1.5 (OUTR), J17.3
HP_EN: IC1.13 (EN), J17.5, R32.1
HP_G0: IC1.6 (GO), JP2.2
HP_G1: IC1.7 (G1), JP3.2
unnamed: R26.2, U13.6 (OUTL)
unnamed: R27.2, U13.7 (OUTR)
unnamed: C28.1, C29.1, U13.18 (LDOO)
unnamed: C36.1, U13.2 (CAPP)
unnamed: C36.2, U13.4 (CAPM)
unnamed: C37.1, U13.5 (VNEG)
unnamed: R28.1, U13.17 (XSMT)
unnamed: C41.2, IC1.1 (INL-)
unnamed: C40.2, IC1.4 (INR-)
unnamed: C43.1, IC1.8 (HPVSS)
unnamed: C42.2, IC1.12 (HPVDD)
unnamed: C44.2, IC1.9 (CPN)
unnamed: C44.1, IC1.11 (CPP)
unnamed: C49.2, U14.4 (INL-)
unnamed: C48.2, U14.7 (INR+)
unnamed: C47.2, U14.3 (INL+)
unnamed: C50.2, U14.6 (INR-)
unnamed: JP4.2, U14.5 (GAIN)
unnamed: JP4.1, R30.1
unnamed: JP4.3, R29.1
SPK_L_N: U14.14 (OUTL-); also elsewhere on the board
SPK_L_P: U14.13 (OUTL+); also elsewhere on the board
SPK_R_N: U14.9 (OUTR-); also elsewhere on the board
SPK_R_P: U14.10 (OUTR+); also elsewhere on the board



Board: 4 copper layers, 320.0 x 57.5 mm, 152 parts (13 on the bottom side), 173 nets.

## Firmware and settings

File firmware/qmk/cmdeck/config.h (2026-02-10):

#pragma once

/* OLED */
#define OLED_DISPLAY_128X64
#define OLED_IC OLED_IC_SH1106
#define OLED_DC_PIN GP23
#define OLED_CS_PIN GP22
#define OLED_RST_PIN GP24
#define OLED_SPI_DIVISOR 4
#define OLED_COLUMN_OFFSET 2

/* ChibiOS SPI definitions */
#define SPI_DRIVER SPID1
#define SPI_SCK_PIN GP26
#define SPI_MOSI_PIN GP27
#define SPI_MISO_PIN GP28

/* RGB MATRIX */
#define RGB_MATRIX_MAXIMUM_BRIGHTNESS 180
#define RGB_MATRIX_TIMEOUT 30000
#define RGB_MATRIX_SLEEP

/* MAGIC BOOT */
#define BOOTMAGIC_ROW 0
#define BOOTMAGIC_COLUMN 11

/* CIRQUE TRACKPAD*/
#define CIRQUE_PINNACLE_SPI_CS_PIN 25
#define CIRQUE_PINNACLE_TAP_ENABLE
#define POINTING_DEVICE_ROTATION_270
#define CIRQUE_PINNACLE_CURVED_OVERLAY
#define CIRQUE_PINNACLE_SECONDARY_TAP_ENABLE
#define CIRQUE_PINNACLE_ATTENUATION EXTREG__TRACK_ADCCONFIG__ADC_ATTENUATE_2X

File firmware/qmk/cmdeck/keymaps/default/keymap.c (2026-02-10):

// Copyright 2023 QMK
// SPDX-License-Identifier: GPL-2.0-or-later

#include QMK_KEYBOARD_H

enum layers {
  _QWERTY,
  _LOWER,
  _RAISE,
  _ADJUST
};

const uint16_t PROGMEM keymaps[][MATRIX_ROWS][MATRIX_COLS] = {
    [_QWERTY]   = LAYOUT(
                            KC_ESC,     KC_CAPS,    MO(3),    _______,    _______,      _______,                    _______,    _______,    _______,    _______,    KC_LEFT,    KC_RIGHT,

                            KC_TAB,     KC_Q,       KC_W,       KC_E,       KC_R,       KC_T,                       KC_Y,       KC_U,       KC_I,       KC_O,       KC_P,       KC_BSPC,

                            KC_LSFT,    KC_A,       KC_S,       KC_D,       KC_F,       KC_G,                       KC_H,       KC_J,       KC_K,       KC_L,       KC_QUOT,    KC_SCLN,

                            KC_LCTL,    KC_Z,       KC_X,       KC_C,       KC_V,       KC_B,                       KC_N,       KC_M,       KC_COMM,    KC_DOT,     KC_SLSH,    KC_ENTER,

                KC_AUDIO_MUTE,                                  KC_LALT,    KC_LGUI,    LT(_LOWER, KC_SPC),         LT(_RAISE, KC_SPC),   KC_DOWN,    KC_UP
                ),
    [_LOWER]    = LAYOUT(
                            KC_TILD,    KC_F1,      KC_F2,      KC_F3,      KC_F4,      KC_F5,                      KC_F6,      KC_F7,      KC_F8,      KC_F9,      KC_LEFT,    KC_RIGHT,

                            KC_DEL,     KC_EXLM,    KC_AT,      KC_HASH,    KC_DLR,     KC_PERC,                    KC_CIRC,    KC_AMPR,    KC_ASTR,    KC_LPRN,    KC_RPRN,    KC_BSPC,

                            _______,    _______,    _______,    _______,    _______,    _______,                    _______,    _______,    _______,    _______,    _______,    _______,

                            _______,    _______,    _______,    _______,    _______,    _______,                    _______,    _______,    _______,    _______,    _______,    _______,

                KC_AUDIO_MUTE,                                  KC_LALT,    KC_LGUI,    _______,                    _______,   KC_DOWN,    KC_UP
            ),
    [_RAISE]    = LAYOUT(
                            KC_TILD,    KC_F1,      KC_F2,      KC_F3,      KC_F4,      KC_F5,                      KC_F6,      KC_F7,      KC_F8,      KC_F9,      KC_LEFT,    KC_RIGHT,

                            KC_DEL,     KC_1,       KC_2,       KC_3,       KC_4,       KC_5,                       KC_6,       KC_7,       KC_8,       KC_9,       KC_0,       KC_BSPC,

                            _______,    _______,    _______,    _______,    _______,    _______,                    _______,    _______,    _______,    _______,    _______,    _______,

                            _______,    _______,    _______,    _______,    _______,    _______,                    _______,    _______,    _______,    _______,    _______,    _______,

                KC_AUDIO_MUTE,                                  KC_LALT,    KC_LGUI,    _______,                    _______,   KC_DOWN,    KC_UP
            ),
    [_ADJUST]   = LAYOUT(
                            QK_BOOT,    _______,    _______,    _______,    _______,    _______,                    RM_SPDU,    RM_SPDD,    RM_SATU,    RM_SATD,    RM_PREV,    RM_NEXT,

                            _______,    _______,    _______,    _______,    _______,    _______,                    _______,    _______,    _______,    _______,    _______,    _______,

                            _______,    _______,    _______,    _______,    _______,    _______,                    _______,    _______,    _______,    _______,    _______,    _______,

                            _______,    _______,    _______,    _______,    _______,    _______,                    _______,    _______,    _______,    _______,    _______,    _______,

                RM_TOGG,                                        _______,    _______,    _______,                    _______,   RM_HUED,    RM_HUEU
            )
};

#ifdef ENCODER_MAP_ENABLE
const uint16_t PROGMEM encoder_map[][NUM_ENCODERS][NUM_DIRECTIONS] = {
    [0] = { ENCODER_CCW_CW(KC_KB_VOLUME_UP, KC_KB_VOLUME_DOWN)  },
    [3] = { ENCODER_CCW_CW(RM_VALU, RM_VALD)  },
};
#endif

#ifdef OLED_ENABLE
static void render_logo(void) {
    static const char PROGMEM qmk_logo[] = {
        0x80, 0x81, 0x82, 0x83, 0x84, 0x85, 0x86, 0x87, 0x88, 0x89, 0x8A, 0x8B, 0x8C, 0x8D, 0x8E, 0x8F, 0x90, 0x91, 0x92, 0x93, 0x94,
        0xA0, 0xA1, 0xA2, 0xA3, 0xA4, 0xA5, 0xA6, 0xA7, 0xA8, 0xA9, 0xAA, 0xAB, 0xAC, 0xAD, 0xAE, 0xAF, 0xB0, 0xB1, 0xB2, 0xB3, 0xB4,
        0xC0, 0xC1, 0xC2, 0xC3, 0xC4, 0xC5, 0xC6, 0xC7, 0xC8, 0xC9, 0xCA, 0xCB, 0xCC, 0xCD, 0xCE, 0xCF, 0xD0, 0xD1, 0xD2, 0xD3, 0xD4, 0x00
    };
    oled_set_cursor(0, 2);
    oled_write_P(qmk_logo, false);
}

bool oled_task_user(void) {
    render_logo();
    return false;
}
#endif

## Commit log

2026-02-10 Video Upload
    [CDMDECK_KB_INTERNAL_SUP_BAT_LEFT.stl, CDMDECK_KB_INTERNAL_SUP_BAT_PERI_LEFT.stl, CDMDECK_KB_INTERNAL_SUP_BAT_PERI_RIGHT.stl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]
2026-08-17 fix: repair CMDeck Rev A PCB defects
    [Keyboard _Board.brd, Keyboard _Schematic.sch, Main Board _Board.brd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]

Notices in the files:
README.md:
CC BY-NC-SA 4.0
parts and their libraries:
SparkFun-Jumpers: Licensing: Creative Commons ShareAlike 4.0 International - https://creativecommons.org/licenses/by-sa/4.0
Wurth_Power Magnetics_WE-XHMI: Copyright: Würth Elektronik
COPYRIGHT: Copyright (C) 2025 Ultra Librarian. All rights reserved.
